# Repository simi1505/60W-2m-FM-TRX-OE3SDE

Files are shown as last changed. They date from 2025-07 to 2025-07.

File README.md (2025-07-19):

# 60W-2m-FM-TRX-OE3SDE
 60W 2m FM TRX with RA60H1317M1A + DRA818V by OE3SDE

## Result

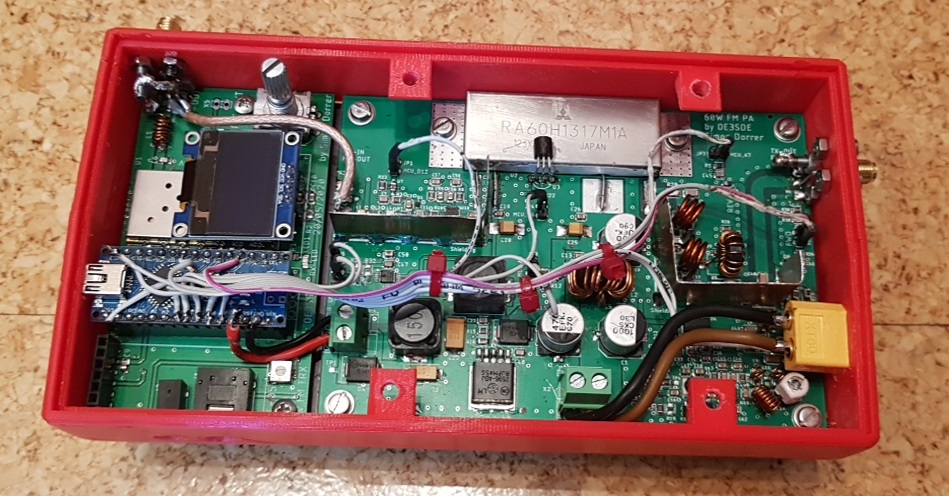
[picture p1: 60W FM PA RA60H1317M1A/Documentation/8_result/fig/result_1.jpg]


**Figure 1**: Final 60W 2m FM TRX in enclosure.

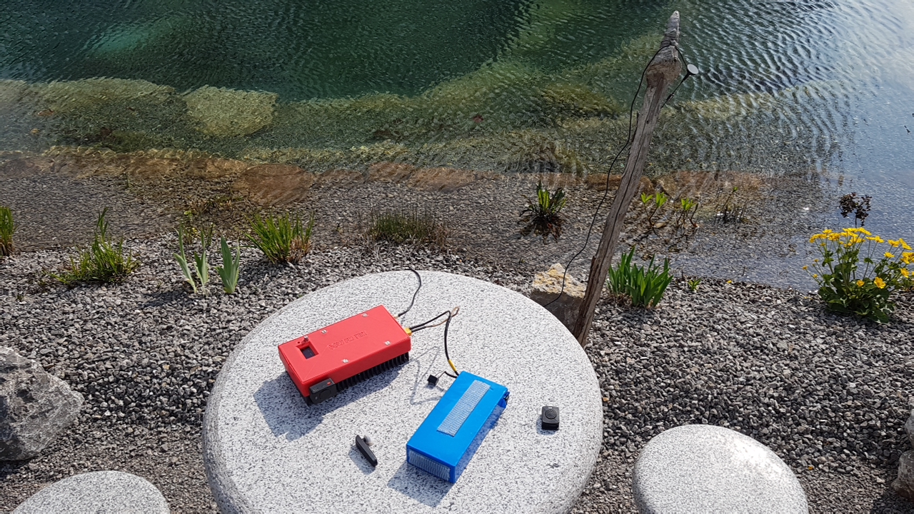
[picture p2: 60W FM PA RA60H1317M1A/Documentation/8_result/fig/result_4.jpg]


**Figure 2**: 60W 2m FM TRX on air.

## 60W TRX

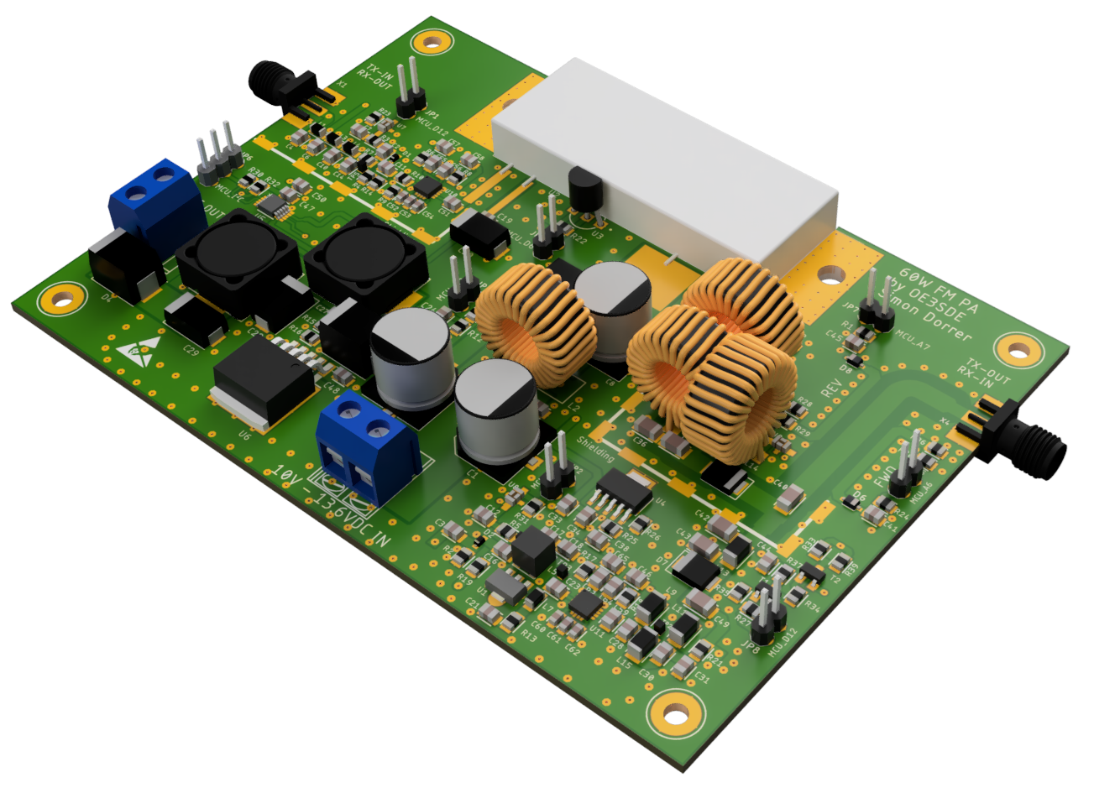
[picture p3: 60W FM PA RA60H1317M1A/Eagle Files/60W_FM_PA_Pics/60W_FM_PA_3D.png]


**Figure 3**: 3D View of RA60H1317M1A PCB.

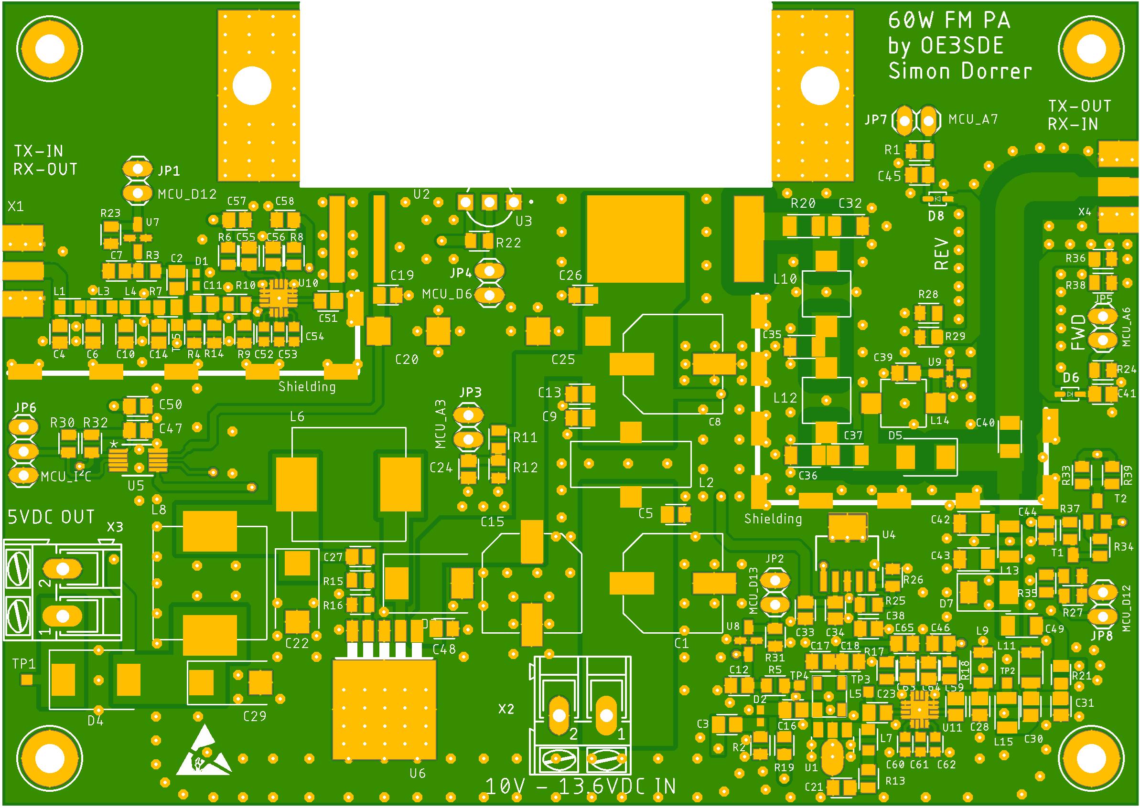
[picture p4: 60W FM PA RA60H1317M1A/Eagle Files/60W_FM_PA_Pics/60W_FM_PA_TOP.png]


**Figure 4**: Top View of RA60H1317M1A PCB.

## 1W TRX and control PCB

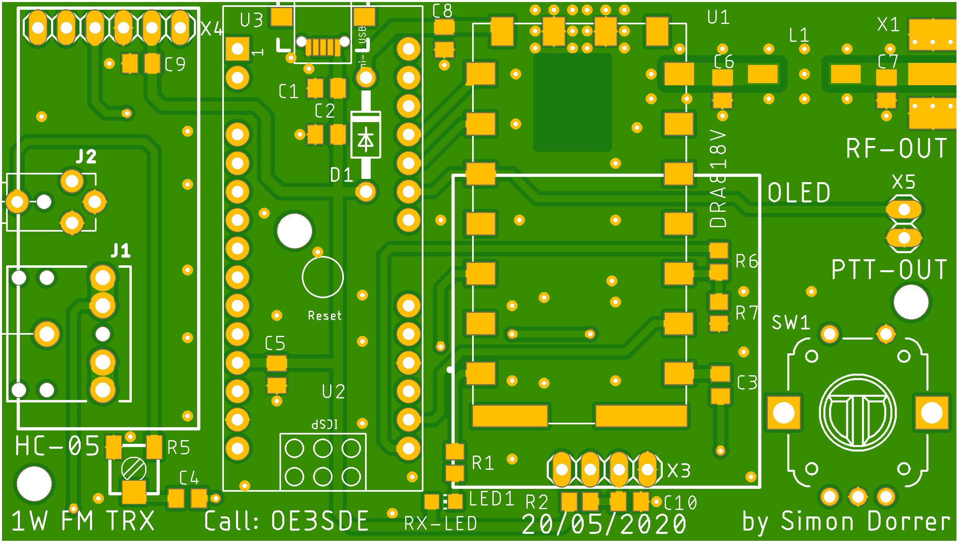
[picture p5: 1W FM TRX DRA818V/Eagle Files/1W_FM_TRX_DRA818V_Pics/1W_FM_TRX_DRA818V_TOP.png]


**Figure 5**: Top View of DRA818V PCB.

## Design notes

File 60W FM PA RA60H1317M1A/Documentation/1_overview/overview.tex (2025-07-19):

\section{Description}
On the following pages the most important details for the 60W 144MHz FM power amplifier are shown. This document includes circuits, PCB-Designs, bill of material, microcontroller codes, measurements and final result pictures.

\section{Software}
The theoretical work like circuit simulation, PCB Design and Microcontroller (MCU) programming was done with following software:
\begin{itemize}
	\item Multisim \& LTSpice: Circuit Simulation
	\item ELSIE: Analog Filter Design
	\item Autodesk EAGLE: Circuit- \& PCB-Design
	\item Autodesk Fusion 360: 3D Design
	\item Arduino: MCU Code
\end{itemize}
\newpage
\section{Devices}
The practical work like PCB assembly, fault finding and measurements are done with the following devices:
\begin{itemize}
	\item FLUKE 179 True RMS Multimeter
	\item Weller WT2020M Soldering Station
	\item Zhongdi ZD-939L Hot Air Rework Station
	\item Andonstar AD407 Digital Microscope
	\item Siglent SDS2352X-E Oscilloscope (2xCH, 350MHz)
	\item Siglent SDG2042X Function Generator (2xCH, 120MHz - hacked)
	\item Siglent SVA1015X Spektrum \& Vector Network Analyser (1.5GHz)
	\item Siglent SPD3303X-E Power Supply (2x0-32V with 3.2A, 1x2.5V/3.3V/5V with 3.2A)
	\item QJ3005EIII 300W Power Supply (2x0-30V with 5A, 1x5V with 3A)
	\item Anycubic i3 Mega S 3D Printer
\end{itemize}
A complete list of all my labor equipment can be found here: \url{https://www.oe3sde.com/Workstation.html}

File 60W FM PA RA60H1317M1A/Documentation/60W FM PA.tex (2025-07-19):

%Author: Simon Dorrer, k12005887
\input{./base/packages}
\input{./base/layout}
\input{./base/titlepage}

\begin{document}
	% Align text on top if there is space left on the page (no rubber lengths will be stretched)
	\raggedbottom
	\maketitle
	
	% Abstract
	\input{./abstract}

	\tableofcontents
	
	% -- Chapter 1 ------------------------------------------------------------------------------------	
	\chapter{Overview}
	\label{chp:overview}
	\input{./1_overview/overview}
	
	% -- Chapter 2 ------------------------------------------------------------------------------------	
	\chapter{Circuit}
	\label{chp:circuit}
	\input{./2_circuit/circuit}
	\includepdf[pages=-]{./2_circuit/60W FM PA_Circuit.pdf}
	
	% -- Chapter 3 ------------------------------------------------------------------------------------	
	\chapter{PCB}
	\label{chp:pcb}
	\input{./3_pcb/pcb}
	
	% -- Chapter 4 ------------------------------------------------------------------------------------	
	\chapter{Bill of Material}
	\label{chp:bom}
	\input{./4_bom/bom}
	
	% -- Chapter 5 ------------------------------------------------------------------------------------	
	\chapter{Measurements}
	\label{chp:measurements}
	\input{./5_measurements/measurements}
	
	% -- Chapter 6 ------------------------------------------------------------------------------------	
	\chapter{Microcontroller Code}
	\label{chp:code}
	\input{./6_code/code}
	% -- Chapter 7 ------------------------------------------------------------------------------------	
	\chapter{Enclosure}
	\label{chp:enclosure}
	\input{./7_enclosure/enclosure}
	
	% -- Chapter 8 ------------------------------------------------------------------------------------	
	\chapter{Result Pictures}
	\label{chp:result}
	\input{./8_result/result}

	%Appendix
	\appendix
	
	% -- List of Abbreviations ------------------------------------------------------------------------
	\newpage
	\chapter*{List of Abbreviations}
	\addcontentsline{toc}{chapter}{List of Abbreviations}
	\markboth{List of Abbreviations}{} % Such that also header shows the right title
	\begin{acronym}[CORDIC]
		\input{acronyms}
	\end{acronym}

	% -- List of Figures ---------------------------------------------------------------------------------
	\listoffigures
	
	% -- List of Tables ---------------------------------------------------------------------------------
	\listoftables
	
	% -- Bibliography ---------------------------------------------------------------------------------
	\bibliographystyle{./base/IEEEtran_isp}
	\bibliography{bibliography}
	
\end{document}

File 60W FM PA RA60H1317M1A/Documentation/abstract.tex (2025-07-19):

\begin{abstract}
	This 60W 144MHz FM Power Amplifier is the perfect "Add-On" for my previously released 1W 144MHz FM Transceiver. This power amplifier adds 30dB gain in the TX-Path and a lot of important analog RF filtering. Furthermore, the RX-Path is amplified with a gain of 23dB and is filtered with high order filters to improve the signal noise ration for better understanding of the other transmitters.
	All RX / TX signals are switched with PIN diodes to avoid expensive radio frequency shielded relais.
\end{abstract}

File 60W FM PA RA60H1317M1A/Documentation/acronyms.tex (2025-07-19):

\setlength{\itemsep}{1ex}
\setlength{\parskip}{0ex}

\acro{adc}[ADC]{analog to digital converter}
\acro{cmos}[CMOS]{complementary metal oxide semiconductor}
\acro{cw}[CW]{continuous wave}
\acro{dac}[DAC]{digital to analog converter}
\acro{mcu}[MCU]{microcontroller unit}
\acro{ic}[IC]{integrated circuit}
\acro{lna}[LNA]{low noise amplifier}
\acro{lpf}[LPF]{lowpass filter}
\acro{hpf}[HPF]{highpass filter}
\acro{bpf}[BPF]{bandpass filter}
\acro{lut}[LUT]{lookup table}
\acro{pa}[PA]{power amplifier}
\acro{pcb}[PCB]{printed circuit board}
\acro{rf}[RF]{radio frequency}
\acro{rx}[RX]{receive}
\acro{snr}[SNR]{signal to noise ratio}
\acro{ssb}[SSB]{single sideband}
\acro{tx}[TX]{transmit}
\acro{trx}[TRX]{transceiver}
\acro{fm}[FM]{frequency modulation}

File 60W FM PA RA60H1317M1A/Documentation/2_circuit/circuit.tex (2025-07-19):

\section{Filters}
In ham radio applications it is very important, that transmitted signals are only in the licensed band. This power amplifier works for the 2m band, that means a frequency range of 144MHz to 146MHz.
Of course, also the received signals should be filtered to avoid any unwanted noise.
\subsection{Air Coil Calculation}
The air coils for the TX-OUT and RX-IN filters according to circuit \ref{fig:TX-OUT Filter_Circuit} and \ref{fig:RX-IN Filter_Circuit} can be calculated with the following formula:
\begin{equation}
	L = \frac{N^{2} \cdot d^{2}}{18 \cdot d + 40 \cdot l}
\end{equation}
 Where:
\begin{itemize}
	\item L = Inductance
	\item N = Number of turns
	\item d = Coil outside diameter
	\item l = Length of the coil
\end{itemize}

\bigskip
For a faster result, also an online calculator\footnote{\url{https://m0ukd.com/calculators/air-cored-inductor-calculator/}} \cite{airCoilCalculator.2015} can be used. 

\newpage
\subsection{TX-IN Filter}
This filter is build up with SMT components because of the low input power of 0.5W.
The TX-IN filter is a seventh order chebyshev low pass filter with a cutoff frequency of 175MHz.
The high order is chosen because of the high harmonic distortion of the DRA818V \acs{TRX} at the input.
\begin{figure}[ht!]
	\centering
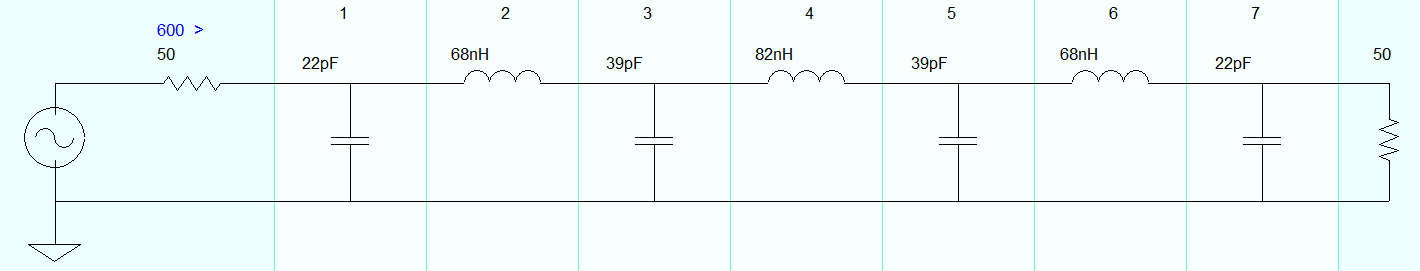
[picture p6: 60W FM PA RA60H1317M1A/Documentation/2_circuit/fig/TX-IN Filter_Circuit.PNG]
	
	\caption{Circuit of the TX-IN Filter}
	\label{fig:TX-IN Filter_Circuit}
\end{figure}
\bigskip
\begin{figure}[ht!]
	\centering
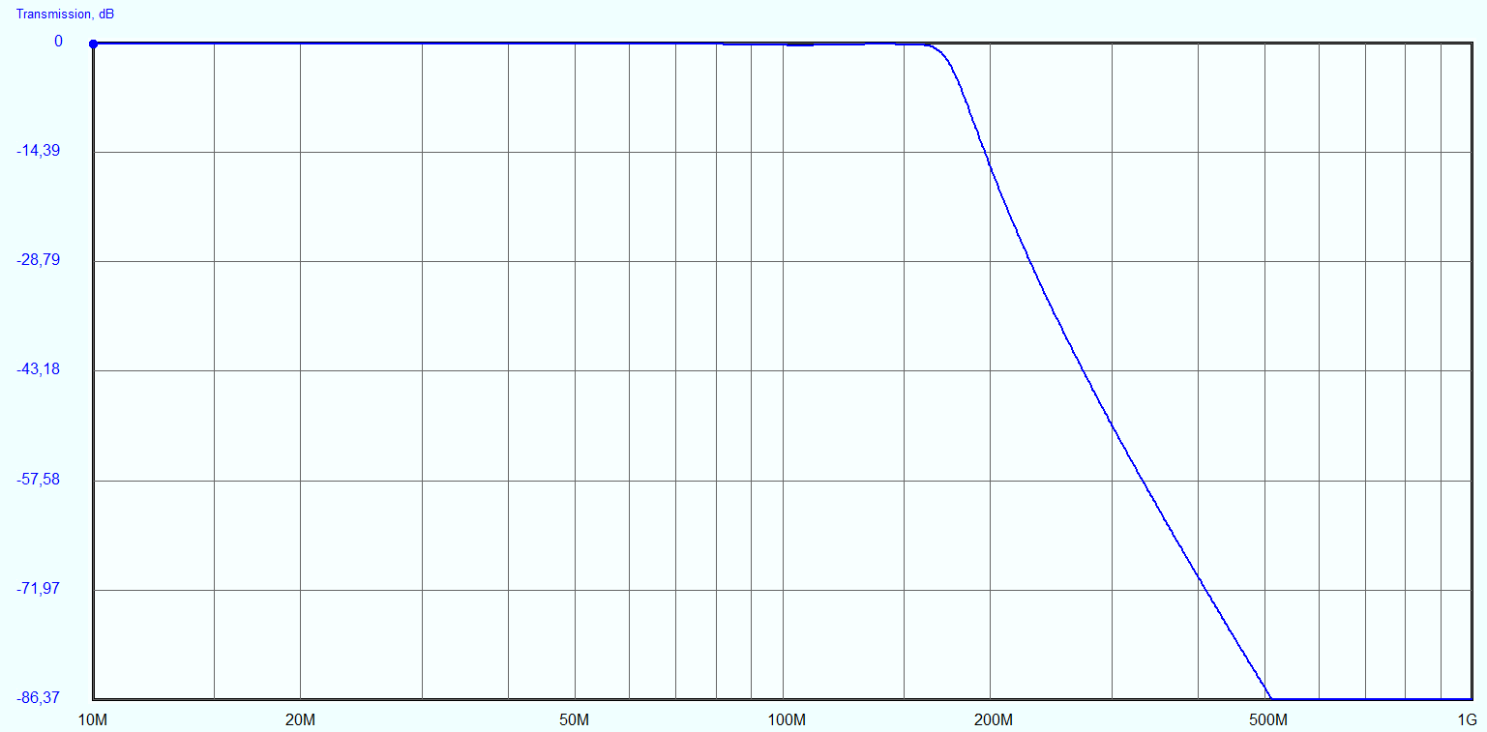
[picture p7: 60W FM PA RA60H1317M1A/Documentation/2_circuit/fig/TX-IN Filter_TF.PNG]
	
	\caption{Transfer Function of the TX-IN Filter}
	\label{fig:TX-IN Filter_TF}
\end{figure}

\newpage
\subsection{TX-OUT Filter}
This filter is build up with self-wound inductors because of the higher output power of 60W.
The TX-OUT filter is a fifth order chebyshev low pass filter with a cutoff frequency of 182MHz.

\begin{figure}[ht!]
	\centering
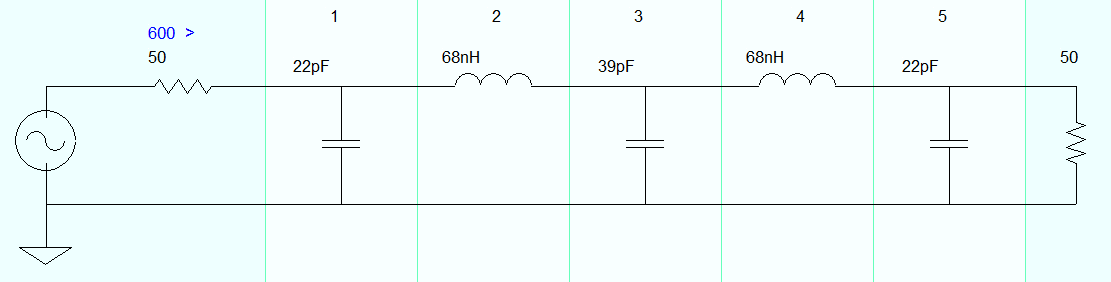
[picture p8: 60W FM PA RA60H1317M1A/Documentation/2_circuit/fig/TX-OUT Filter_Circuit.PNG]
	
	\caption{Circuit of the TX-OUT Filter}
	\label{fig:TX-OUT Filter_Circuit}
\end{figure}
\bigskip
\begin{figure}[ht!]
	\centering
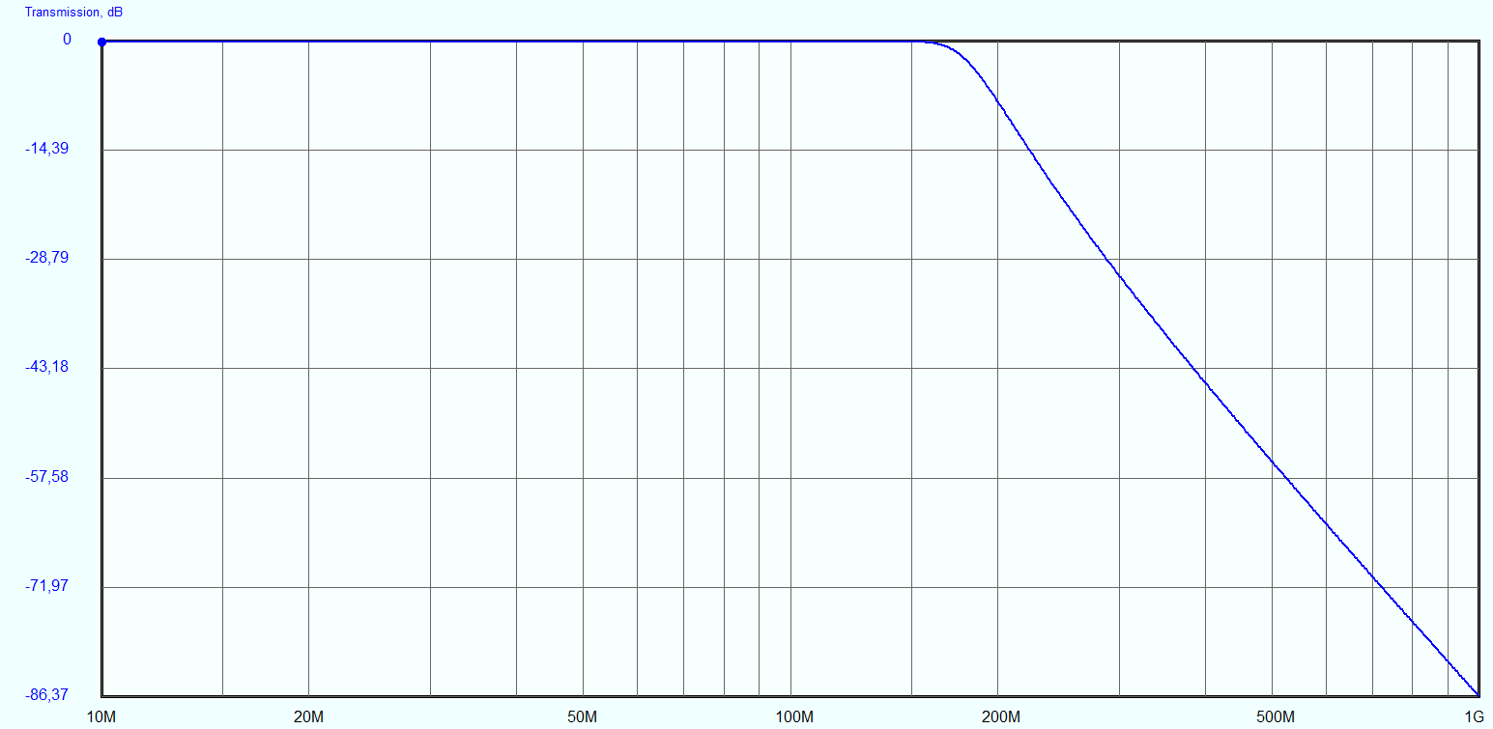
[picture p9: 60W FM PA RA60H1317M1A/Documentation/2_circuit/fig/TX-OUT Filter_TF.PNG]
	
	\caption{Transfer Function of the TX-OUT Filter}
	\label{fig:TX-OUT Filter_TF}
\end{figure}

\newpage
\subsection{RX-IN Filter}
This filter can be build up with SMT components. However, self-wound inductors can be changed easier and the filter band can be adjusted slightly.
The RX-IN filter is a third order chebyshev band pass filter with a lower cutoff frequency of 120MHz and a upper cutoff frequency of 172MHz.

\begin{figure}[ht!]
	\centering
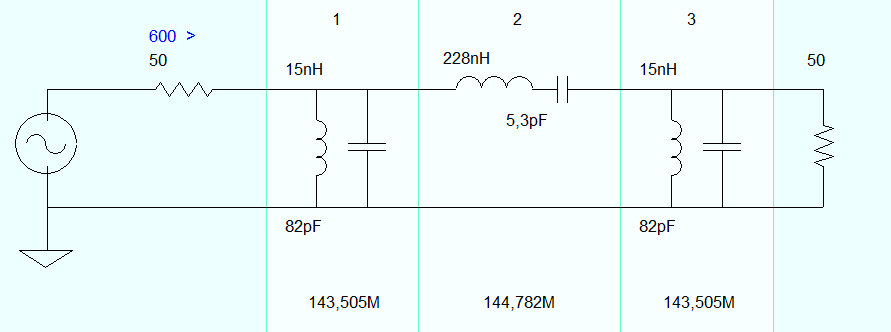
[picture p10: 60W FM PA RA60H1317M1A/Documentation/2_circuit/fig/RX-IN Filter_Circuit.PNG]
	
	\caption{Circuit of the RX-IN Filter}
	\label{fig:RX-IN Filter_Circuit}
\end{figure}
\bigskip
\begin{figure}[ht!]
	\centering
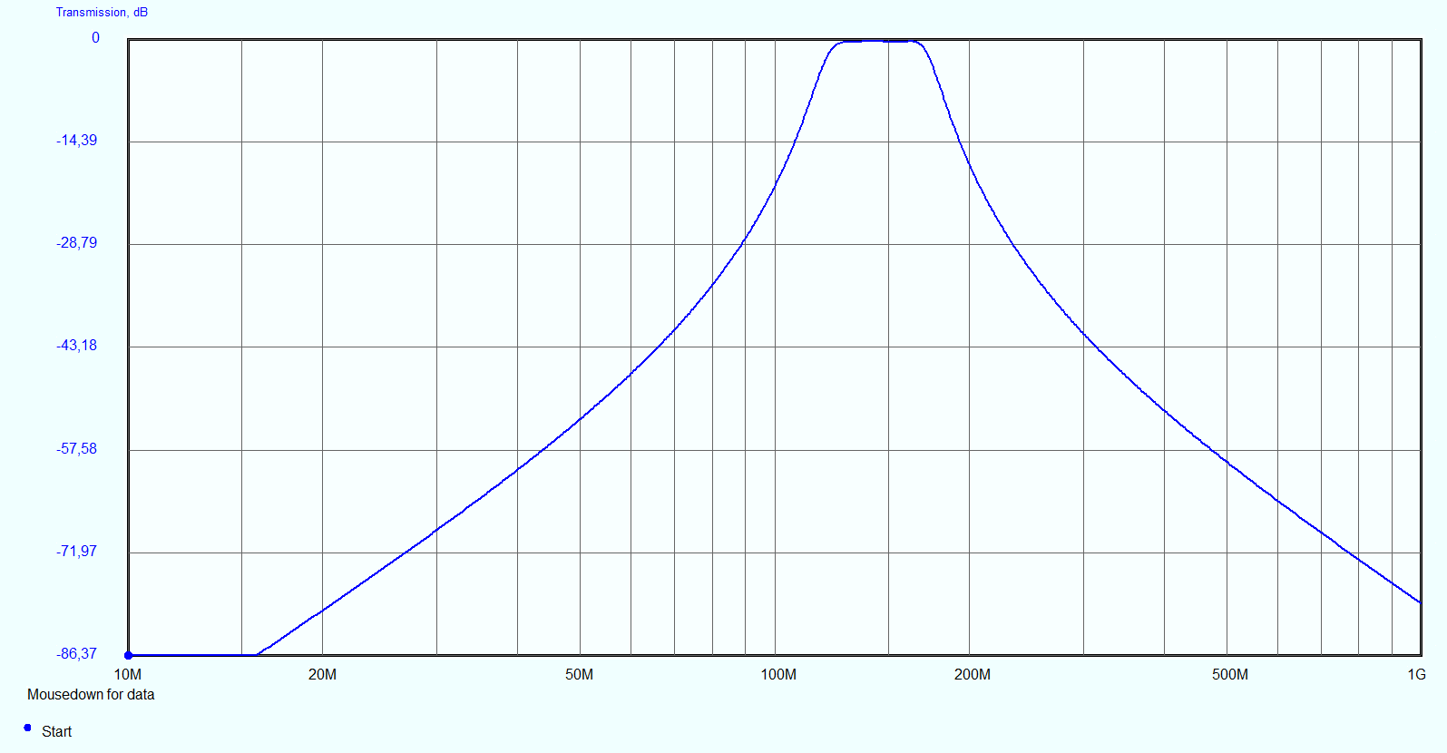
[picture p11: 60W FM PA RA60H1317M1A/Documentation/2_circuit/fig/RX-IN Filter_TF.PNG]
	
	\caption{Transfer Function of the RX-IN Filter}
	\label{fig:RX-IN Filter_TF}
\end{figure}

\newpage
\section{PIN-Diode Switches}
In this project, PIN-Diodes are used instead of relais to switch between RX and TX path.
\subsection{RX/TX Input-Switch}
ToDo Text
\begin{figure}[ht!]
	\centering
	%\includegraphics[width = 12cm]{./2_circuit/fig/}
	
	\caption{Circuit of the RX/TX Input-Switch}
	\label{fig:RX/TX Input-Switch}
\end{figure}

\newpage
\subsection{RX/TX Output-Switch}
ToDo Text
\begin{figure}[ht!]
	\centering
	%\includegraphics[width = 12cm]{./2_circuit/fig/}
	
	\caption{Circuit of the RX/TX Output-Switch}
	\label{fig:RX/TX Output-Switch}
\end{figure}

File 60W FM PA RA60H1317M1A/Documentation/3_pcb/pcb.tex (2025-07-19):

\section{Layer Stackup}
This \acs{PCB} is a two layer PCB. On the top layer the \acs{RF} signals and SMT components are placed. 
The bottom layer is a completed GND layer with some supply traces.
This PCB is produced by my sponsor JLCPCB \footnote{\url{https://jlcpcb.com/}}.
Normally, for bigger RF PCB-Designs a 4 layer PCB is used as follows: 

\begin{figure}[ht!]
	\centering
	
	\caption{Two Layer PCB Stackup}
	\label{fig:PCB Layer Stackup}
\end{figure}
\newpage

\section{Coplanar Waveguide Grounded (CPWG)}
In RF PCB-Design applications it is very important, that the trace impedance is matched to 50$\Omega$.
Therefore, different techniques like Microstrip, Stripline or Coplanar Waveguide are used.
This PCB-Design uses the Coplanar Waveguide method. However, the calculation of this technique is not that easy (elliptical integrals etc.). That is why an online calculator \footnote{\url{https://chemandy.com/calculators/coplanar-waveguide-with-ground-calculator.htm}}  \cite{CPWGCalculator.2021} is used.
The original equations are in \cite{transmissionLineDesign} on page 79.

\subsection{RX CPWG Calculation}
	\begin{figure}[ht!]
		\centering
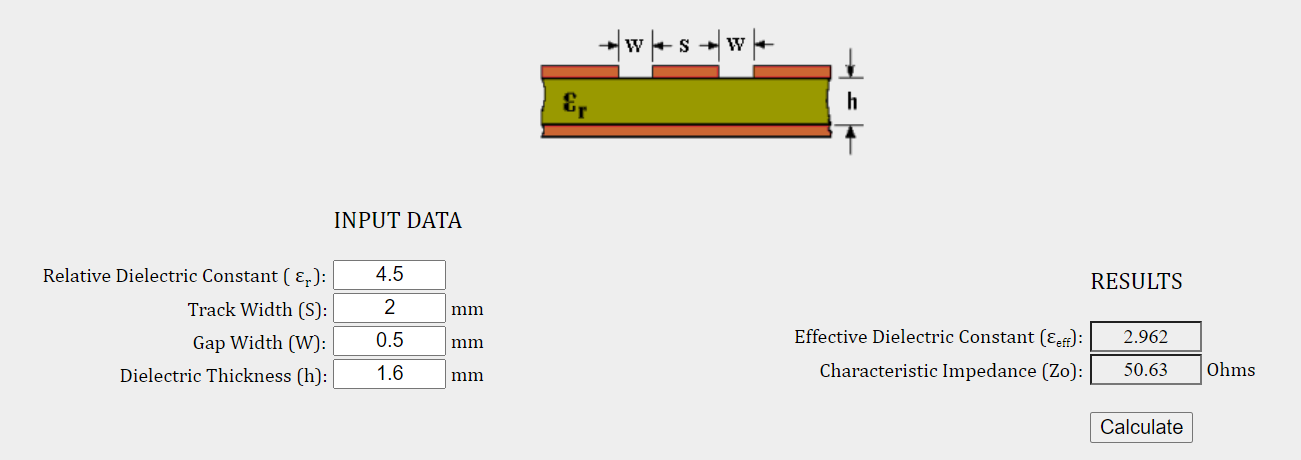
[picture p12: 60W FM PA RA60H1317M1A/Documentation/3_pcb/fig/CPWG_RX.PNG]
		
		\caption{RX CPWG Calculation}
		\label{fig:RX_CPWG}
	\end{figure}

\subsection{TX CPWG Calculation}
	\begin{figure}[ht!]
		\centering
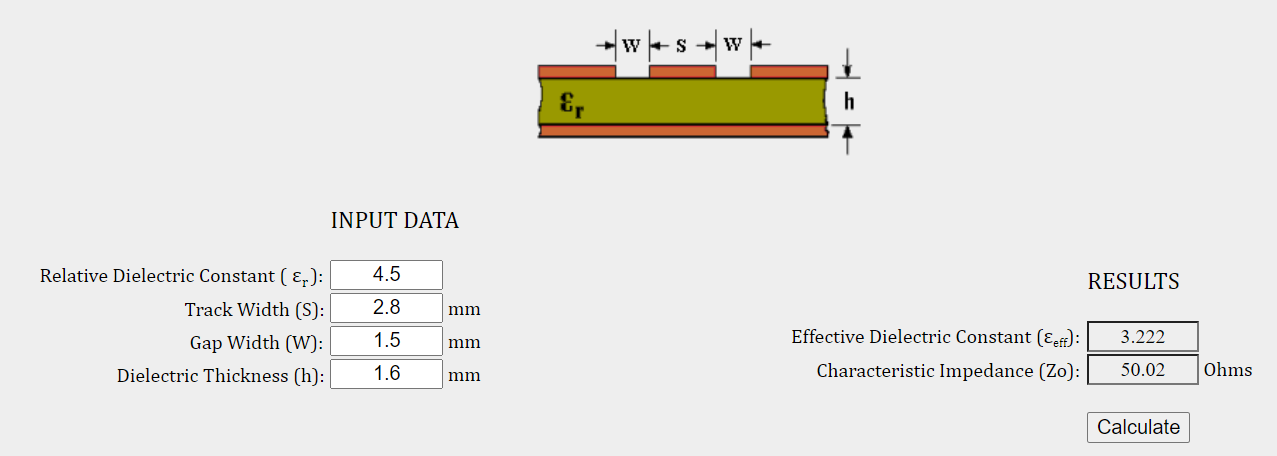
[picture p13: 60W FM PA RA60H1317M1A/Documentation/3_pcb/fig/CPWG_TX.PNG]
		
		\caption{TX CPWG Calculation}
		\label{fig:TX_CPWG}
	\end{figure}

\newpage
\section{Trace corners}	
	ToDo Text
	\begin{figure}[ht!]
		\centering
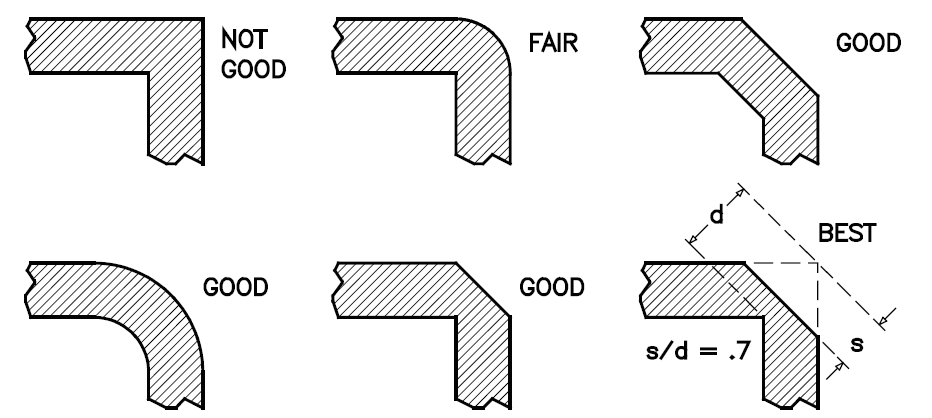
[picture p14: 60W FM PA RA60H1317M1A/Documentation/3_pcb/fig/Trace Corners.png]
		
		\caption{Corners in RF traces}
		\label{fig:Corners}
	\end{figure}

\section{3D PCB}	
	\begin{figure}[ht!]
		\centering
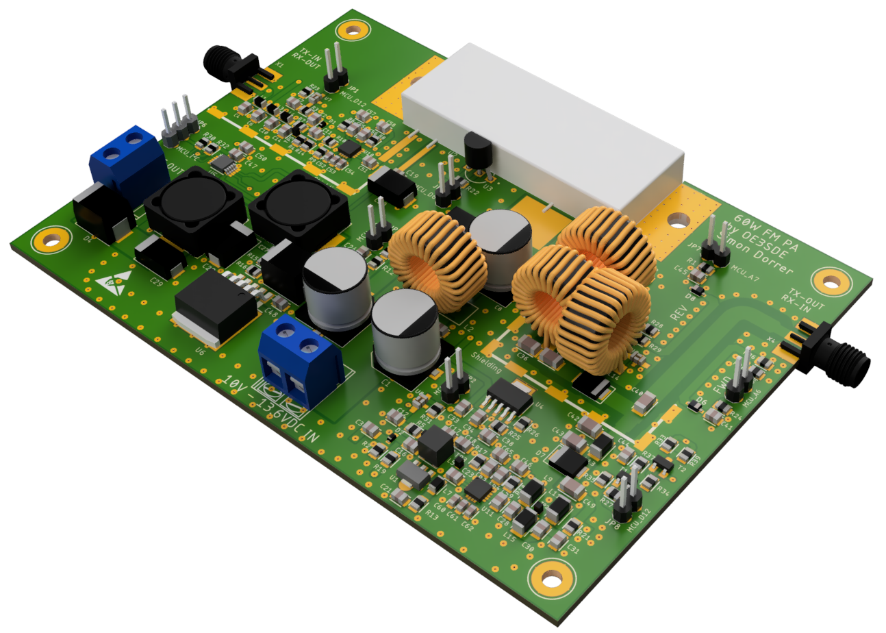
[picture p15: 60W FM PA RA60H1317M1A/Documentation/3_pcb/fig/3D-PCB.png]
		
		\caption{Finished \acs{PCB} 3D view}
		\label{fig:3D-PCB}
	\end{figure}

\newpage
\section{2D PCB}	
	\begin{figure}[ht!]
		\centering
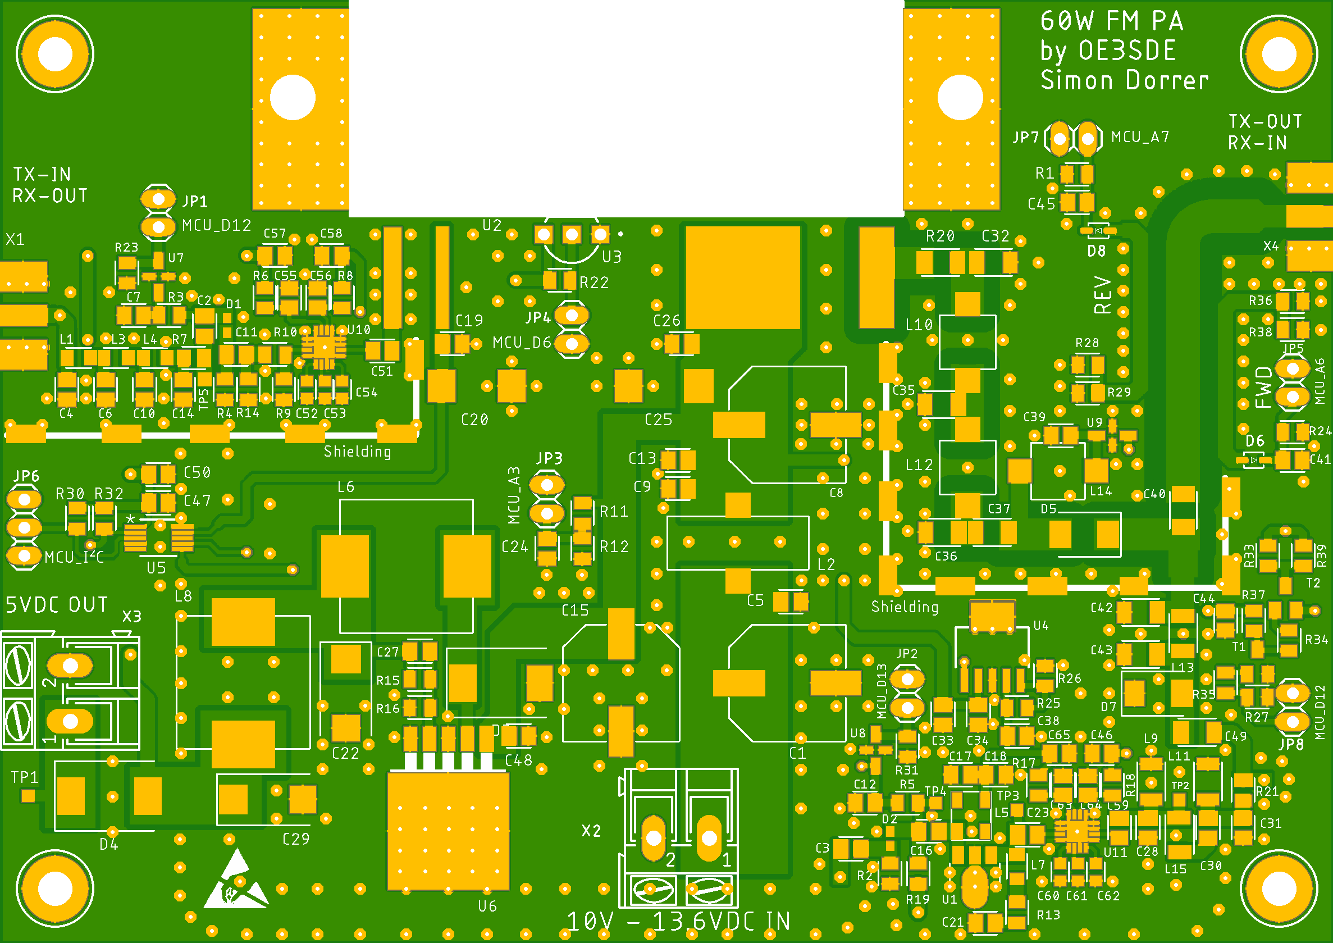
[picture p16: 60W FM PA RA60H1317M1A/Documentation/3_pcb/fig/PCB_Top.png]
		
		\caption{Finished \acs{PCB} 2D top view}
		\label{fig:PCB_Top}
	\end{figure}
	\bigskip
	\begin{figure}[ht!]
		\centering
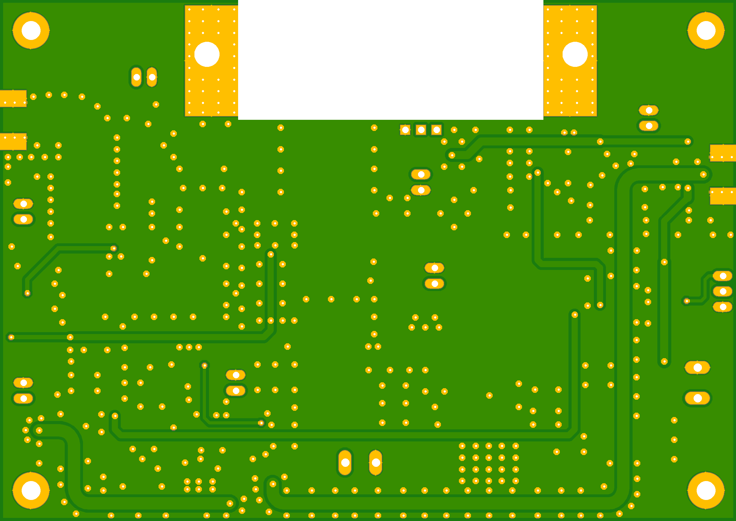
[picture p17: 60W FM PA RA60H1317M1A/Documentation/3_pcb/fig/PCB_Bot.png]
		
		\caption{Finished \acs{PCB} 2D bottom view}
		\label{fig:PCB_Bot}
	\end{figure}
\newpage

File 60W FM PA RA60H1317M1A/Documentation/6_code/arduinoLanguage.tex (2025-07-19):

 %%%%%%%%%%%%%%%%%%%%%%%%%%%%%%%%%%%%%%%%%%%%%%%%%%%%%%%%%%%%%%%%%%%%%%%%%%%%%%%% 
%%% ~ Arduino Language - Arduino IDE Colors ~                                  %%%
%%%                                                                            %%%
%%% Kyle Rocha-Brownell | 10/2/2017 | No Licence                               %%%
%%% -------------------------------------------------------------------------- %%%
%%%                                                                            %%%
%%% Place this file in your working directory (next to the latex file you're   %%%
%%% working on).  To add it to your project, place:                            %%%
%%%    \input{arduinoLanguage.tex}                                             %%%
%%% somewhere before \begin{document} in your latex file.                      %%%
%%%                                                                            %%%
%%% In your document, place your arduino code between:                         %%%
%%%   \begin{lstlisting}[language=Arduino]                                     %%%
%%% and:                                                                       %%%
%%%   \end{lstlisting}                                                         %%%
%%%                                                                            %%%
%%% Or create your own style to add non-built-in functions and variables.      %%%
%%%                                                                            %%%
%%%%%%%%%%%%%%%%%%%%%%%%%%%%%%%%%%%%%%%%%%%%%%%%%%%%%%%%%%%%%%%%%%%%%%%%%%%%%%%% 

\usepackage{color}
\usepackage{listings}    
\usepackage{courier}

%%% Define Custom IDE Colors %%%
\definecolor{arduinoGreen}    {rgb} {0.17, 0.43, 0.01}
\definecolor{arduinoGrey}     {rgb} {0.47, 0.47, 0.33}
\definecolor{arduinoOrange}   {rgb} {0.8 , 0.4 , 0   }
\definecolor{arduinoBlue}     {rgb} {0.01, 0.61, 0.98}
\definecolor{arduinoDarkBlue} {rgb} {0.0 , 0.2 , 0.5 }

%%% Define Arduino Language %%%
\lstdefinelanguage{Arduino}{
	language=C++, % begin with default C++ settings 
	%
	%
	%%% Keyword Color Group 1 %%%  (called KEYWORD3 by arduino)
	keywordstyle=\color{arduinoGreen},   
	deletekeywords={  % remove all arduino keywords that might be in c++
		break, case, override, final, continue, default, do, else, for, 
		if, return, goto, switch, throw, try, while, setup, loop, export, 
		not, or, and, xor, include, define, elif, else, error, if, ifdef, 
		ifndef, pragma, warning,
		HIGH, LOW, INPUT, INPUT_PULLUP, OUTPUT, DEC, BIN, HEX, OCT, PI, 
		HALF_PI, TWO_PI, LSBFIRST, MSBFIRST, CHANGE, FALLING, RISING, 
		DEFAULT, EXTERNAL, INTERNAL, INTERNAL1V1, INTERNAL2V56, LED_BUILTIN, 
		LED_BUILTIN_RX, LED_BUILTIN_TX, DIGITAL_MESSAGE, FIRMATA_STRING, 
		ANALOG_MESSAGE, REPORT_DIGITAL, REPORT_ANALOG, SET_PIN_MODE, 
		SYSTEM_RESET, SYSEX_START, auto, int8_t, int16_t, int32_t, int64_t, 
		uint8_t, uint16_t, uint32_t, uint64_t, char16_t, char32_t, operator, 
		enum, delete, bool, boolean, byte, char, const, false, float, double, 
		null, NULL, int, long, new, private, protected, public, short, 
		signed, static, volatile, String, void, true, unsigned, word, array, 
		sizeof, dynamic_cast, typedef, const_cast, struct, static_cast, union, 
		friend, extern, class, reinterpret_cast, register, explicit, inline, 
		_Bool, complex, _Complex, _Imaginary, atomic_bool, atomic_char, 
		atomic_schar, atomic_uchar, atomic_short, atomic_ushort, atomic_int, 
		atomic_uint, atomic_long, atomic_ulong, atomic_llong, atomic_ullong, 
		virtual, PROGMEM,
		Serial, Serial1, Serial2, Serial3, SerialUSB, Keyboard, Mouse,
		abs, acos, asin, atan, atan2, ceil, constrain, cos, degrees, exp, 
		floor, log, map, max, min, radians, random, randomSeed, round, sin, 
		sq, sqrt, tan, pow, bitRead, bitWrite, bitSet, bitClear, bit, 
		highByte, lowByte, analogReference, analogRead, 
		analogReadResolution, analogWrite, analogWriteResolution, 
		attachInterrupt, detachInterrupt, digitalPinToInterrupt, delay, 
		delayMicroseconds, digitalWrite, digitalRead, interrupts, millis, 
		micros, noInterrupts, noTone, pinMode, pulseIn, pulseInLong, shiftIn, 
		shiftOut, tone, yield, Stream, begin, end, peek, read, print, 
		println, available, availableForWrite, flush, setTimeout, find, 
		findUntil, parseInt, parseFloat, readBytes, readBytesUntil, readString, 
		readStringUntil, trim, toUpperCase, toLowerCase, charAt, compareTo, 
		concat, endsWith, startsWith, equals, equalsIgnoreCase, getBytes, 
		indexOf, lastIndexOf, length, replace, setCharAt, substring, 
		toCharArray, toInt, press, release, releaseAll, accept, click, move, 
		isPressed, isAlphaNumeric, isAlpha, isAscii, isWhitespace, isControl, 
		isDigit, isGraph, isLowerCase, isPrintable, isPunct, isSpace, 
		isUpperCase, isHexadecimalDigit, 
	}, 
	morekeywords={   % add arduino structures to group 1
		break, case, override, final, continue, default, do, else, for, 
		if, return, goto, switch, throw, try, while, setup, loop, export, 
		not, or, and, xor, include, define, elif, else, error, if, ifdef, 
		ifndef, pragma, warning,
	}, 
	% 
	%
	%%% Keyword Color Group 2 %%%  (called LITERAL1 by arduino)
	keywordstyle=[2]\color{arduinoBlue},   
	keywords=[2]{   % add variables and dataTypes as 2nd group  
		HIGH, LOW, INPUT, INPUT_PULLUP, OUTPUT, DEC, BIN, HEX, OCT, PI, 
		HALF_PI, TWO_PI, LSBFIRST, MSBFIRST, CHANGE, FALLING, RISING, 
		DEFAULT, EXTERNAL, INTERNAL, INTERNAL1V1, INTERNAL2V56, LED_BUILTIN, 
		LED_BUILTIN_RX, LED_BUILTIN_TX, DIGITAL_MESSAGE, FIRMATA_STRING, 
		ANALOG_MESSAGE, REPORT_DIGITAL, REPORT_ANALOG, SET_PIN_MODE, 
		SYSTEM_RESET, SYSEX_START, auto, int8_t, int16_t, int32_t, int64_t, 
		uint8_t, uint16_t, uint32_t, uint64_t, char16_t, char32_t, operator, 
		enum, delete, bool, boolean, byte, char, const, false, float, double, 
		null, NULL, int, long, new, private, protected, public, short, 
		signed, static, volatile, String, void, true, unsigned, word, array, 
		sizeof, dynamic_cast, typedef, const_cast, struct, static_cast, union, 
		friend, extern, class, reinterpret_cast, register, explicit, inline, 
		_Bool, complex, _Complex, _Imaginary, atomic_bool, atomic_char, 
		atomic_schar, atomic_uchar, atomic_short, atomic_ushort, atomic_int, 
		atomic_uint, atomic_long, atomic_ulong, atomic_llong, atomic_ullong, 
		virtual, PROGMEM,
	},  
	% 
	%
	%%% Keyword Color Group 3 %%%  (called KEYWORD1 by arduino)
	keywordstyle=[3]\bfseries\color{arduinoOrange},
	keywords=[3]{  % add built-in functions as a 3rd group
		Serial, Serial1, Serial2, Serial3, SerialUSB, Keyboard, Mouse,
	},      
	%
	%
	%%% Keyword Color Group 4 %%%  (called KEYWORD2 by arduino)
	keywordstyle=[4]\color{arduinoOrange},
	keywords=[4]{  % add more built-in functions as a 4th group
		abs, acos, asin, atan, atan2, ceil, constrain, cos, degrees, exp, 
		floor, log, map, max, min, radians, random, randomSeed, round, sin, 
		sq, sqrt, tan, pow, bitRead, bitWrite, bitSet, bitClear, bit, 
		highByte, lowByte, analogReference, analogRead, 
		analogReadResolution, analogWrite, analogWriteResolution, 
		attachInterrupt, detachInterrupt, digitalPinToInterrupt, delay, 
		delayMicroseconds, digitalWrite, digitalRead, interrupts, millis, 
		micros, noInterrupts, noTone, pinMode, pulseIn, pulseInLong, shiftIn, 
		shiftOut, tone, yield, Stream, begin, end, peek, read, print, 
		println, available, availableForWrite, flush, setTimeout, find, 
		findUntil, parseInt, parseFloat, readBytes, readBytesUntil, readString, 
		readStringUntil, trim, toUpperCase, toLowerCase, charAt, compareTo, 
		concat, endsWith, startsWith, equals, equalsIgnoreCase, getBytes, 
		indexOf, lastIndexOf, length, replace, setCharAt, substring, 
		toCharArray, toInt, press, release, releaseAll, accept, click, move, 
		isPressed, isAlphaNumeric, isAlpha, isAscii, isWhitespace, isControl, 
		isDigit, isGraph, isLowerCase, isPrintable, isPunct, isSpace, 
		isUpperCase, isHexadecimalDigit, 
	},      
	%
	%
	%%% Set Other Colors %%%
	stringstyle=\color{arduinoDarkBlue},    
	commentstyle=\color{arduinoGrey},    
	%          
	%   
	%%%% Line Numbering %%%%
	numbers=left,                    
	numbersep=5pt,                   
	numberstyle=\color{arduinoGrey},    
	%stepnumber=2,                      % show every 2 line numbers
	%
	%
	%%%% Code Box Style %%%%
	breaklines=true,                    % wordwrapping
	tabsize=2,         
	basicstyle=\ttfamily  
}

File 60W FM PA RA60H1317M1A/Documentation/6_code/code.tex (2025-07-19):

In this chapter, the MCU Code written with Arduino IDE is implemented. 
The internal hardware of the used MCU (ATmega328) is programmed on register level.
To control the OLED display, the external DAC and some sensors, external libraries are used.

\begin{lstlisting}[language=Arduino]
//Arduino Code for DRA818V FM TRX + 60W RA60H1317M1A
//This code is written by OE3SDE, Simon Dorrer!

//Define CPU-Clock-Speed (16MHz internal clock)
//#define F_CPU 16000000UL

//Define Baudrate for UART
//#define BAUD 9600UL

//Include Libraries
#include <avr/io.h>
#include <stdio.h>
#include <avr/interrupt.h>

//I2C
#include <Wire.h>

//MCP4728
#include <Adafruit_MCP4728.h>

//DS18B20
#include <OneWire.h> 
#include <DallasTemperature.h>

//Libs. for SD1306 OLED-Display
#include <Adafruit_GFX.h>               // Include core graphics library for the display
#include <Adafruit_SSD1306.h>           // Include Adafruit_SSD1306 library to drive the display
#include <Fonts/FreeMono9pt7b.h>        // Add a custom font
/*List of different fonts :
FreeMono9pt7b.h
FreeMonoBold9pt7b.h
FreeMonoBoldOblique9pt7b.h
FreeMonoOblique9pt7b.h  
*/
//----------------------------------------------------------------------------

//Definitions
//I/O Declaration
//1W FM TRX Board (DRA818V)
//#define TX        0     //PD0 / D0
//#define RX        1     //PD1 / D1
#define SW1         2     //PD2 / D2 - INT0
#define PTT_IN      3     //PD3 / D3 - INT1
#define PTT_OUT     7     //PD7 / D7
#define PD          0     //PB0 / D8
#define H_L         1     //PB1 / D9
#define HC05_TX     2     //PB2 / D10
#define HC05_RX     3     //PB3 / D11
#define E1          0     //PC0 / A0
#define E2          1     //PC1 / A1

//60W FM TRX Board (RA60H1317M1A)
#define PGA_SHDN    5     //PB5 / D13 (LOW --> PGA OFF, HIGH --> PGA ON) + RX Switch
#define TX_SW       4     //PB4 / D12 (HIGH TX Switch)
//#define T1_SW     7     //PD7 / D7  (switches T1 for TRX Switch - LOW for TX, HIGH for RX) --> see PTT_OUT D7
#define DS18B20_OW  6     //PD6 / D6  (One wire input of DS18B20 Temp. Sensor)
#define SWR_REV     7     //PC7 / A7  (ADC samples reverse voltage)
#define SWR_FWD     6     //PC6 / A6  (ADC samples forward voltage)
#define ADC_VDD     3     //PC3 / A3  (ADC samples VDD voltage) 

//I2C: OLED Display, MCP4728

//Makros
//RX or TX ATTENUATOR
#define RX_ATTENUATOR_CHANNEL  MCP4728_CHANNEL_A
#define TX_ATTENUATOR_CHANNEL  MCP4728_CHANNEL_B

//PA max. ratings
#define VDD_LOWER_LIMIT 10.7  //in V
#define VDD_UPPER_LIMIT 14.2  //in V
#define SWR_LOWER_LIMIT 0.5   
#define SWR_UPPER_LIMIT 2
#define HEAT_UPPER_LIMIT 45   //in degrees
//----------------------------------------------------------------------------

//Global variables / Objects
uint8_t TX = 0;  // 0... RX; 1... TX
uint8_t switched = 0;

//OLED
Adafruit_SSD1306 display(128, 64);    // Create display
volatile uint16_t timer1Count = 0;

//DRA818 Variables
typedef struct{
	float txFreq;         //TX-Frequency in MHz (134.0000 - 174.0000)
	float rxFreq;         //RX-Frequency in MHz (134.0000 - 174.0000)
	String txCTCSS;       //CTCSS frequency (0000 - 0038); 0000 = "no CTCSS" 
	String rxCTCSS;       //CTCSS frequency (0000 - 0038); 0000 = "no CTCSS" 
	uint8_t bw;           //Bandwith in KHz (0= 12.5KHz or 1= 25KHz)
	uint8_t squ;          //Squelch level  (0 - 8); 0 = "open" 
	uint8_t vol;
	uint8_t prf;
	uint8_t hpf;
	uint8_t lpf;
}DRA818;

DRA818 dra818 = {145.5000, 145.5000, "0000", "0000", 1, 4, 8, 0, 0, 0};

//DS18B20
OneWire oneWire(DS18B20_OW); 
DallasTemperature ds18b20(&oneWire);

//MCP4728
Adafruit_MCP4728 mcp4728;

//Rotary Encoder Variables
int counter = 0; 
int aState;
int aLastState;  

//RA60H1317M1A Variables
float txGain = 10;
float txAtt = 0;
float rxAtt = 0;
uint8_t monitorPA = 0;  //monitorPA = 1... PA is OK!
//----------------------------------------------------------------------------

//Subprograms
//Hardware Init Methods
void IO_Init()                  //initialize IO
{
	//Define INPUTs
	DDRD &= ~(1 << SW1);          //set PD2 (SW1) as Input
	PORTD |= (1 << SW1);          //activate Pull-Up-R at PD2 (SW1)    
	
	DDRD &= ~(1 << PTT_IN);       //set PD3 (PTT-IN) as Input
	PORTD |= (1 << PTT_IN);       //activate Pull-Up-R at PD3 (PTT_IN)     
	
	DDRC &= ~(1 << E1);           //set PC0 (E1) as Input    
	DDRC &= ~(1 << E2);           //set PC1 (E2) as Input
	
	DDRC &= ~(1 << ADC_VDD);      //set PC3 (ADC_VDD) as Input  
	//PORTC |= (1 << ADC_VDD);      //activate Pull-Up-R at PC3 (ADC_VDD)
	
	DDRC &= ~(1 << SWR_FWD);      //set PC6 (SWR_FWD) as Input  
	PORTC |= (1 << SWR_FWD);      //activate Pull-Up-R at PC6 (SWR_FWD)
	
	DDRC &= ~(1 << SWR_REV);      //set PC7 (SWR_REV) as Input  
	PORTC |= (1 << SWR_REV);      //activate Pull-Up-R at PC7 (SWR_REV)
	
	//Define OUTPUTs
	DDRD |= (1 << PTT_OUT);       //set PD7 (PTT_OUT) as Output
	DDRB |= (1 << PD);            //set PB0 (PD) as Output
	DDRB |= (1 << H_L);           //set PB1 (H_L) as Output
	
	DDRB |= (1 << TX_SW);         //set PB4 (TX_Switch) as Output
	DDRB |= (1 << PGA_SHDN);      //set PB5 (PGA_SHDN) as Output
}

void Timer1_COMPA_Init()
{
	//Control Registers
	TCCR1A = 0; TCCR1B = 0; TCCR1C = 0; //Reset
	
	// set CTC mode
	//TCCR1A |= (1 << WGM10);
	//TCCR1A |= (1 << WGM11);
	TCCR1B |= (1 << WGM12);
	
	// Set Prescaler 1024 (TCCR1B = (1 << WGM12) | (0x5 << CS10);)
	TCCR1B |= (1 << CS12);
	TCCR1B &= ~(1 << CS11);
	TCCR1B |= (1 << CS10);
	
	// initialize compare value
	OCR1A = 16;
	
	// enable timer compare interrupt
	TIMSK1 |= (1 << OCIE1A);
}

void Timer2_COMPA_Init()
{
	//Timer2 settings
	TCCR2A = 0x00; TCCR2B = 0x00; //Reset
	
	//Enable Timer2 CTC Mode
	//TCCR2A |= (1 << WGM20);
	TCCR2A |= (1 << WGM21);
	//TCCR2B |= (1 << WGM22);
	
	//Prescaler
	// 1024 prescaling for Timer2 (TCCR2B = (0x7 << CS20);)
	TCCR2B |= (1 << CS20);
	TCCR2B |= (1 << CS21);
	TCCR2B |= (1 << CS22);
	
	//Initialize compare value
	OCR2A = 0;
	
	//initialize TIMER0-Counter
	//TCNT2 = 0; // set counter value FORMEL: x = maximaler Zaehlwert - ((CPUtakt/PRESCALER)/ gesuchte Frequenz)
	
	//disable Timer compare interrupt
	TIMSK2 &= ~(1 << OCIE2A);
}

void INT0_Init()
{
	//enable Interrupt
	EIMSK |= (1 << INT0); //Ext. Int0 ein
	
	//Set falling Edge Interrupt (EICRA |= (0x2 << ISC00);)
	EICRA &= ~(1 << ISC00);
	EICRA |= (1 << ISC01);
}
void INT1_Init()
{
	//enable Interrupt
	EIMSK |= (1 << INT1); //Ext. Int1 ein
	
	//Set rising & falling Edge Interrupt (EICRA |= (0x2 << ISC10);)
	EICRA |= (1 << ISC10);
	EICRA &= ~(1 << ISC11);
}

void ADC_Init()
{
	//ADC Setup
	//Set Reference Voltage (VCC = VREF)
	ADMUX &= ~(1 << REFS1);
	ADMUX |= (1 << REFS0);
	
	//Prescaler --> 128 (50kHz - 200kHz)
	ADCSRA |= (1 << ADPS0);
	ADCSRA |= (1 << ADPS1);
	ADCSRA |= (1 << ADPS2);
	
	ADCSRA |= (1 << ADEN); //Enable ADC
	
	//Dummy Readout to warm up the ADC
	ADCSRA |= (1<<ADSC);          //Start ADC conclusion
	while (ADCSRA & (1<<ADSC)){}  //wait until ADC is ready
	(void) ADC;
}
uint16_t ADC_ReadValue(uint8_t channel)
{
	ADMUX = (ADMUX & ~(0x1F)) | (channel & 0x1F); //which ADCx? Bit Mask to secure ADMUX settings in Init() function
	
	ADCSRA |= (1<<ADSC);          //Start ADC conclusion
	while (ADCSRA & (1<<ADSC)){}  //wait until ADC is ready
	
	return ADC;                   //return the ADC value
}

//DRA818V Methods
void DRA818V_setGroup()
{
	Serial.print("AT+DMOSETGROUP=");         // begin message
	Serial.print(dra818.bw);
	Serial.print(",");
	Serial.print(dra818.txFreq, 4);
	Serial.print(",");
	Serial.print(dra818.rxFreq, 4);
	Serial.print(",");
	Serial.print(dra818.txCTCSS);
	Serial.print(",");
	Serial.print(dra818.squ);
	Serial.print(",");
	Serial.println(dra818.rxCTCSS);
}
void DRA818V_setVolume()
{
	Serial.print("AT+DMOSETVOLUME=");
	Serial.println(dra818.vol);
}
void DRA818V_setFilter()
{
	Serial.print("AT+SETFILTER=");
	Serial.print(dra818.prf);
	Serial.print(",");
	Serial.print(dra818.hpf);
	Serial.print(",");
	Serial.println(dra818.lpf);
}
void DRA818V_Init()             // initialize DRA818V
{
	PORTB &= ~(1 << PD);
	delay(2000);
	
	//I/O
	PORTD |= (1 << PTT_OUT);      // set PD7 (PTT_OUT) HIGH at the beginning (RX-Mode)
	PORTB |= (1 << PD);           // set PB0 (PD) HIGH at the beginning (Normal-Mode)
	PORTB &= ~(1 << H_L);         // set PB1 (H/L) LOW at the beginning (LOW-Power = 0.5W)
	
	//UART
	Serial.begin(9600);
	delay(10);
	DRA818V_setGroup();
	delay(500);
	DRA818V_setVolume();
	delay(500);
	DRA818V_setFilter();
	delay(500);
}

//RA60H1317M1A Methods
float getVDD()      //Get VDD Voltage (10.8VDC to 13.6VDC)
{
	float vdd = 0;
	// #PJN: You may spend a LOT of time in this loop => make ADC reading asynchronous
	
	vdd = ADC_ReadValue(ADC_VDD) * 5.0 / 1024.0;
	
	return((vdd * ((4700 + 18000) / 4700)) + 2.2);  //returns supply voltage without voltage division (magic numbers equals the voltage divider resistor values)
}
float getSWR()      //Get SWR of output load (should be between 0.5 and 2)
{
	float rev = 0;
	float fwd = 0;
	// #PJN: You may spend just more time in this loop => make ADC reading asynchronous
	for(int i = 0; i < 10; i++)   //10 iterations for a more precise result
	{
		rev = rev + ADC_ReadValue(SWR_REV);
		fwd = fwd + ADC_ReadValue(SWR_FWD);
	}
	rev = rev / 10 / 1024 * 5;
	fwd = fwd / 10 / 1024 * 5;
	
	//SWR Calculation
	return((fwd + rev) / (fwd - rev));
}
float getPWR()
{
	float fwd = 0;
	for(int i = 0; i < 10; i++)   //10 iterations for a more precise result
	{
		fwd = fwd + ADC_ReadValue(SWR_FWD);
	}
	fwd = fwd / 10 / 1024 * 5;
	
	//PWR Calculation
	return((fwd * fwd) / 50);
}
float getHeat()     //Get heat of RA60H1317M1A measured by DS18B20, should be smaller than 50
{
	ds18b20.requestTemperatures();
	return(ds18b20.getTempCByIndex(0));
}
void setTXGain(float gain)  //Set Gain of RA60H1317M1A via MCP4728 (VOUTD)
{
	if(gain == 0)
	{
		mcp4728.setChannelValue(MCP4728_CHANNEL_D, 0);
	}
	else
	{
		//ToDo Formula
		mcp4728.setChannelValue(MCP4728_CHANNEL_D, 4095);
	}
}
void setAttenuation(MCP4728_channel_t channel, float att) //Attenuation of U11 (RX) or U12 (TX) (F2255NLGK)
{
	//Note that the PGA-103 has a constant gain of 25dB for RX path! RX_ATTENUATOR_CHANNEL MCP4728_CHANNEL_A
	//Note that an 6dB Attenuator is assembled on board for TX path! TX_ATTENUATOR_CHANNEL MCP4728_CHANNEL_B
	
	if(att > 35)
	{
		mcp4728.setChannelValue(channel, 2048);
	}
	else if(att < 2.5)
	{
		mcp4728.setChannelValue(channel, 0);
	}
	else
	{
		att = att * (-1);
		mcp4728.setChannelValue(channel, (uint16_t)(4096 * (-0.03692 * att + 0.60769) / 5));  //0.7V (-2.5dB) to 1.9V (-35dB), magic numbers are calculated according to the attenuation curve of the datasheet!
	}
}
void switchPAtoTX(uint8_t TX_Att, uint8_t TX_Gain)
{
	if(monitorPA == 1)
	{
		//turn OFF RX:
		mcp4728.setChannelValue(MCP4728_CHANNEL_C, 0);    //turn RX Path in TRX Switch OFF (VOUTC to LOW)
		PORTB &= ~(1 << PGA_SHDN);                        //turn OFF PGA RX-Amp. and RX Switch (D13 to LOW)
		setAttenuation(RX_ATTENUATOR_CHANNEL, 36);        //set full attenuation of U11 (F2255NLGK)
		
		delay(100);     //100ms settling time
		
		//turn ON TX:
		PORTD &= ~(1 << PTT_OUT);                         //turn TX Path in TRX Switch ON (D7 LOW)
		PORTB |= (1 << TX_SW);                            //turn on TX Switch (D12 to HIGH)
		setAttenuation(TX_ATTENUATOR_CHANNEL, TX_Att);    //set attenuation of U12 (F2255NLGK)
		setTXGain(TX_Gain);                               //Set TX gain (VGG (Gate) voltage) of RA60H1317M1A
		delay(100);                                       //100ms settling time
	}
	else
	{
		switchPAtoRX(rxAtt);
	}
}
void switchPAtoRX(float RX_Att)
{
	//turn OFF TX:
	setTXGain(0);                                       //Set gain of RA60H1317M1A to 0
	setAttenuation(TX_ATTENUATOR_CHANNEL, 36);          //set full attenuation of U12 (F2255NLGK)
	PORTB &= ~(1 << TX_SW);                             //turn OFF TX Switch (D12 to LOW)
	PORTD |= (1 << PTT_OUT);                            //turn TX Path in TRX Switch OFF (D7 HIGH)
	delay(100);                                         //100ms settling time
	
	//turn ON RX
	mcp4728.setChannelValue(MCP4728_CHANNEL_C, 4095);   //turn RX Path in TRX Switch ON (VOUTC to HIGH)
	PORTB |= (1 << PGA_SHDN);                           //turn ON PGA RX-Amp. and RX Switch (D13 to HIGH)
	setAttenuation(RX_ATTENUATOR_CHANNEL, RX_Att);      //set attenuation of U11 (F2255NLGK)
	delay(100);                                         //100ms settling time
}
void verifyPA()   //Shutdown RA60H1317M1A according to SWR, VDD and Heat
{
	float vdd = getVDD();
	float swr = getSWR();
	float heat = getHeat();
	Serial.print("VDD: ");
	Serial.println(vdd);
	Serial.print("SWR: ");
	Serial.println(swr);
	Serial.print("HEAT: ");
	Serial.println(heat);
	
	//if((vdd >= VDD_LOWER_LIMIT && vdd <= VDD_UPPER_LIMIT) && (swr >= SWR_LOWER_LIMIT && swr <= SWR_UPPER_LIMIT) && heat <= HEAT_UPPER_LIMIT)
	if((vdd >= VDD_LOWER_LIMIT && vdd <= VDD_UPPER_LIMIT) && heat <= HEAT_UPPER_LIMIT)
	{
		monitorPA = 1;  //PA is OK!
	}
	else
	{
		monitorPA = 0;
		if(TX == 1)
		{
			switchPAtoRX(rxAtt);
		}
	}
}

//Display Methods
void displayInit()
{
	delay(100);                                 // This delay is needed to let the display to initialize
	if(!display.begin(SSD1306_SWITCHCAPVCC, 0x3C)){ // Address 0x3C for 128x32
		Serial.println(F("SSD1306 allocation failed"));
		while (1){
			delay(10);
		}
	}
	display.clearDisplay();                     // Clear the buffer
	display.setTextColor(WHITE);                // Set color of the text
	//display.setRotation(2);                     // Set orientation. Goes from 0, 1, 2 or 3
	display.setTextWrap(false);                 // By default, long lines of text are set to automatically "wrap" back to the leftmost column. 
	// To override this behavior (so text will run off the right side of the display - useful for scrolling marquee effects), use setTextWrap(false).
	display.dim(0);                             //Set brightness (0 is maximun and 1 is a little dim)
	display.setFont(&FreeMono9pt7b);            // Set a custom font
	display.setTextSize(0);                     // Set text size. We are using a custom font so you should always use the text size of 0
	display.display();                          // Print everything we set previously
}
void displayStartScreen()
{
	display.setCursor(10, 15);                  // (x,y)
	display.println("60W FM TRX");              // Text or value to print
	display.setCursor(10, 35);                  // (x,y)
	display.println("by OE3SDE");               // Text or value to print
	display.setCursor(10, 55);                  // (x,y)
	display.println("S. Dorrer");               // Text or value to print
	display.display();                          // Print everything we set previously
}
void refreshDisplay()
{
	display.clearDisplay();
	
	// TX / RX
	if(TX == 1)
	{
		display.setCursor(10, 15);                  // (x,y)
		display.println("TX");
	}
	else if(TX == 0)
	{
		display.setCursor(10, 15);                  // (x,y)
		display.println("RX");
	}
	
	// Power
	display.setCursor(50, 15);                    // (x,y)
	display.println("PWR:.5W");
	
	// Frequency
	display.setCursor(30, 35);                    // (x,y)
	display.println(dra818.txFreq);
	
	//Values
	display.setCursor(2, 55);                  // (x,y)
	display.print(getVDD());                    // Text or value to print
	display.print(" ");
	display.print(getHeat());                  // Text or value to print  
	display.display();
}
//----------------------------------------------------------------------------

//Setup (Initialize hardware)
void setup()
{
	//HW Init
	IO_Init();
	INT0_Init();
	INT1_Init();
	Timer1_COMPA_Init();
	Timer2_COMPA_Init();
	ADC_Init();
	
	// OLED Init
	displayInit();
	displayStartScreen();
	
	//DRA818V Init
	DRA818V_Init();
	
	//DS18B20 Init
	ds18b20.begin(); 
	
	//MCP4728 Init
	if(!mcp4728.begin()){
		Serial.println("Failed to find MCP4728 chip!");
		while (1){
			delay(10);
		}
	}
	
	//RA60H1317M1A
	verifyPA();
	switchPAtoRX(rxAtt); //standard attenuation of 10dB
	
	sei(); //enable global interrupts
	
	//Reads the initial state of the outputA (E2)
	aLastState = digitalRead(E2); 	// #PJN: wondering why you're now using the digitalRead() because output handling is done via direct register access - it's however OK anyways
	
	display.clearDisplay();
	display.display();
}
//----------------------------------------------------------------------------

//Loop
void loop()
{
	if(timer1Count >= 500)
	{
		timer1Count = 0;
		verifyPA();
		refreshDisplay();
	}
	
	if(TX == 1 && switched == 1)
	{
		switchPAtoTX(txAtt, txGain);    //PA PCB is transmitting now!
		//PORTD &= ~(1 << PTT_OUT);     //DRA818V TX (done in switchPAtoTX)
		switched = 0;
	}
	else if (TX == 0 && switched == 1)
	{
		//PORTD |= (1 << PTT_OUT);      //DRA818V RX (done in switchPAtoRX)
		switchPAtoRX(rxAtt);            //PA PCB is receiving now!
		switched = 0;
	}
	
	// #PJN: Because of the above code you'll get a lot of jitter when reading the encoder below
	aState = digitalRead(E2); // Reads the "current" state of the outputA
	// If the previous and the current state of the outputA are different, that means a Pulse has occured
	if (aState != aLastState)
	{     
		// If the outputB state is different to the outputA state, that means the encoder is rotating clockwise
		if (digitalRead(E1) != aState) 
		{ 
			counter++;
		} 
		else 
		{
			counter--;
		}
	} 
	aLastState = aState; // Updates the previous state of the outputA with the current state
}
//----------------------------------------------------------------------------

//ISP (Interrupt Service Routine) 
ISR(TIMER1_COMPA_vect)  // every 1ms
{
	timer1Count++;
}

ISR(TIMER2_COMPA_vect) // execute by TIMER2 CTC
{
	static uint16_t timer2Count = 0; //only at first ISR call
	
	timer2Count++; //inkrementieren
	
	if(timer2Count == 4000) //256ms sperren
	{
		//enable INT0
		EIMSK |= (1 << INT0); //Ext. Int0 on
		
		//enable INT1
		EIMSK |= (1 << INT1); //Ext. Int0 on
		
		//clear INTF0
		EIFR |= (1 << INTF0);
		
		//clear INTF1
		EIFR |= (1 << INTF1);
		
		//disable TIMER2 compare interrupt
		TIMSK2 &= ~(1 << OCIE2A);
		
		//reset of counter value
		timer2Count = 0;
	}
}

ISR(INT0_vect)  //Rotary Encoder Switch
{
	static uint8_t encoderPressedCounter = 1; //only at first ISR call
	
	uint8_t temp = SREG; //Store SREG
	
	encoderPressedCounter++;
	
	//DEBOUNCE
	//disable INT0
	EIMSK &= ~(1 << INT0); //Ext. INT0 off
	//enable TIMER2 compare interrupt
	TIMSK2 |= (1 << OCIE2A);
	
	switch (encoderPressedCounter) 
	{
		case 1:
		// #PJN: Off topic: channel spacing on 2m is 12.5 kHz ... maybe just increase/decrease frequency values instead of fixed ones?
		dra818.txFreq = 145.5000;   //TX-Frequency in MHz
		dra818.rxFreq = 145.5000;   //RX-Frequency in MHz
		DRA818V_setGroup();
		break;
		case 2:
		dra818.txFreq = 144.2000;   //TX-Frequency in MHz
		dra818.rxFreq = 144.2000;   //RX-Frequency in MHz
		DRA818V_setGroup();
		break;
		case 3:
		dra818.txFreq = 144.5000;   //TX-Frequency in MHz
		dra818.rxFreq = 144.5000;   //RX-Frequency in MHz
		DRA818V_setGroup();
		break;
		case 4:
		dra818.txFreq = 145.2000;   //TX-Frequency in MHz
		dra818.rxFreq = 145.2000;   //RX-Frequency in MHz
		DRA818V_setGroup();
		break;
		case 5:
		dra818.txFreq = 145.0000;   //TX-Frequency in MHz
		dra818.rxFreq = 145.0000;   //RX-Frequency in MHz
		DRA818V_setGroup();
		encoderPressedCounter = 0;
		break;
		default:
		encoderPressedCounter = 0;
		break;
	}
	
	SREG = temp;
}

ISR(INT1_vect) //PTT-IN (active LOW)
{
	//DEBOUNCE
	//disable INT1
	//EIMSK &= ~(1 << INT1); //Ext. INT1 off
	//enable TIMER2 compare interrupt
	//TIMSK2 |= (1 << OCIE2A);
	
	switched = 1;
	
	if(!(PIND & (1 << PTT_IN)))         //PTT_IN changed to LOW
	{
		//switchPAtoTX(txAtt, txGain);    //PA PCB is transmitting now!
		//PORTD &= ~(1 << PTT_OUT);       //DRA818V TX (done in switchPAtoTX)
		TX = 1;
	}
	else if (PIND & (1 << PTT_IN))      //PTT_IN changed to HIGH
	{
		//PORTD |= (1 << PTT_OUT);        //DRA818V RX (done in switchPAtoRX)
		//switchPAtoRX(rxAtt);            //PA PCB is receiving now!
		TX = 0;
	}
}
//----------------------------------------------------------------------------
//End of Code!
\end{lstlisting}

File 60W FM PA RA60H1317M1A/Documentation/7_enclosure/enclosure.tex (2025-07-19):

Unfortunately, the 3D enclosure is not finished yet. In the end, the enclosure will be 3D printed.

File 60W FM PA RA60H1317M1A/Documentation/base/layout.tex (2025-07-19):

%Geometry of document: A4 portrait
%\geometry{paper=a4paper, top=1.6cm, bottom=2.85cm, left=0.9cm, right=2.15cm}
%\geometry{paper=a4paper, top=3.6cm, bottom=3.6cm, left=2.6cm, right=3.7cm}
\geometry{paper = a4paper, left = 20mm, right = 15mm, top = 15mm, bottom = 12.5mm, includeheadfoot}

%Header formation
\pagestyle{fancy}
\fancyhf{}												% Clear header / footer
\fancyhead[EL, OR]{\textsc{\nouppercase{\leftmark}}}    % Chapter in the right on even pages
\fancyhead[ER, OL]{\thepage}							%Page number location
\fancyfoot[ER, OL]{\copyright\/ Simon Dorrer, OE3SDE}	%Copyright + Name + Matrikelnmmer

\fancypagestyle{plain}{									%set pagestyle also for plain page
	\pagestyle{fancy}
}

%Separation line header / footer with 1.25pt
%\renewcommand{\headrulewidth}{1.25pt}
%\renewcommand{\footrulewidth}{1.25pt}

% Optional: Correct bad hyphenation
\hyphenation{}

%10mm area between header / footer and textarea
\setlength{\headsep}{10mm}
\setlength{\footskip}{12.5mm}

%No indentation, 1.1ex between paragraphs
\setlength{\parindent}{0ex}
\setlength{\parskip}{1.1ex plus0.25ex minus0.25ex}

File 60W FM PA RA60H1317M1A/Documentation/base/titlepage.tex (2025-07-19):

%Title
\title{\emph{60W 144MHz FM Power Amplifier}}	%Set title (no new page)
\author{by Simon Dorrer, OE3SDE}				%Set Name and matrikelnumber (also \footnote instead of \thanks is possible)
\date{\today}									%Set date

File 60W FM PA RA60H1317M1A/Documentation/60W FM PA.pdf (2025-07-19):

# 60W 144MHz FM Power Amplifier

## by Simon Dorrer, OE3SDE

## May 18, 2021

Abstract

### This 60W 144MHz FM Power Amplifier is the perfect "Add-On" for my previously released 1W 144MHz FM Transceiver. This power amplifier adds 30dB gain in the TX-Path and a lot of

important analog RF filtering. Furthermore, the RX-Path is amplified with a gain of 23dB and is filtered with high order filters to improve the signal noise ration for better understanding of the other transmitters. All RX / TX signals are switched with PIN diodes to avoid expensive radio frequency shielded relais.

Contents | 2

# Contents

1 Overview | 4
2 Circuit | 6
3 PCB | 13
4 Bill of Material | 17
5 Measurements | 19

### © Simon Dorrer, OE3SDE

3 | Contents
6 Microcontroller Code | 25
7 Enclosure | 42
8 Result Pictures | 43
List of Abbreviations | 45
List of Figures | 46
List of Tables | 47
Bibliography | 48

Chapter 1. | Overview | 4

# Chapter 1

# Overview

## 1.1 Description

On the following pages the most important details for the 60W 144MHz FM power amplifier are shown. This document includes circuits, PCB-Designs, bill of material, microcontroller codes, measurements and final result pictures.

## 1.2 Software

The theoretical work like circuit simulation, PCB Design and Microcontroller (MCU) programming

### was done with following software:

### - Multisim & LTSpice: Circuit Simulation

### - ELSIE: Analog Filter Design

### - Autodesk EAGLE: Circuit- & PCB-Design

### - Autodesk Fusion 360: 3D Design

### - Arduino: MCU Code

5 | Chapter 1. | Overview

## 1.3 Devices

The practical work like PCB assembly, fault finding and measurements are done with the following

### devices:

### - FLUKE 179 True RMS Multimeter

### - Weller WT2020M Soldering Station

### - Zhongdi ZD-939L Hot Air Rework Station

### - Andonstar AD407 Digital Microscope

### - Siglent SDS2352X-E Oscilloscope (2xCH, 350MHz)

### - Siglent SDG2042X Function Generator (2xCH, 120MHz - hacked)

### - Siglent SVA1015X Spektrum & Vector Network Analyser (1.5GHz)

### - Siglent SPD3303X-E Power Supply (2x0-32V with 3.2A, 1x2.5V/3.3V/5V with 3.2A)

### - QJ3005EIII 300W Power Supply (2x0-30V with 5A, 1x5V with 3A)

### - Anycubic i3 Mega S 3D Printer

### A complete list of all my labor equipment can be found here: https://www.oe3sde.com/

Workstation.html (https://www.oe3sde.com/Workstation.html)

Chapter 2. | Circuit | 6

# Chapter 2

# Circuit

## 2.1 Filters

In ham radio applications it is very important, that transmitted signals are only in the licensed band. This power amplifier works for the 2m band, that means a frequency range of 144MHz to 146MHz. Of course, also the received signals should be filtered to avoid any unwanted noise.

## 2.1.1 Air Coil Calculation

The air coils for the TX-OUT and RX-IN filters according to circuit 2.3 and 2.5 can be calculated

### with the following formula:

L =

N²
- d

2
18 · d + 40 · l

(2.1)

### Where:

### - L = Inductance

### - N = Number of turns

### - d = Coil outside diameter

### - l = Length of the coil

### For a faster result, also an online calculator¹

[1] can be used.

1https://m0ukd.com/calculators/air-cored-inductor-calculator/

## 2.1.2 TX-IN Filter

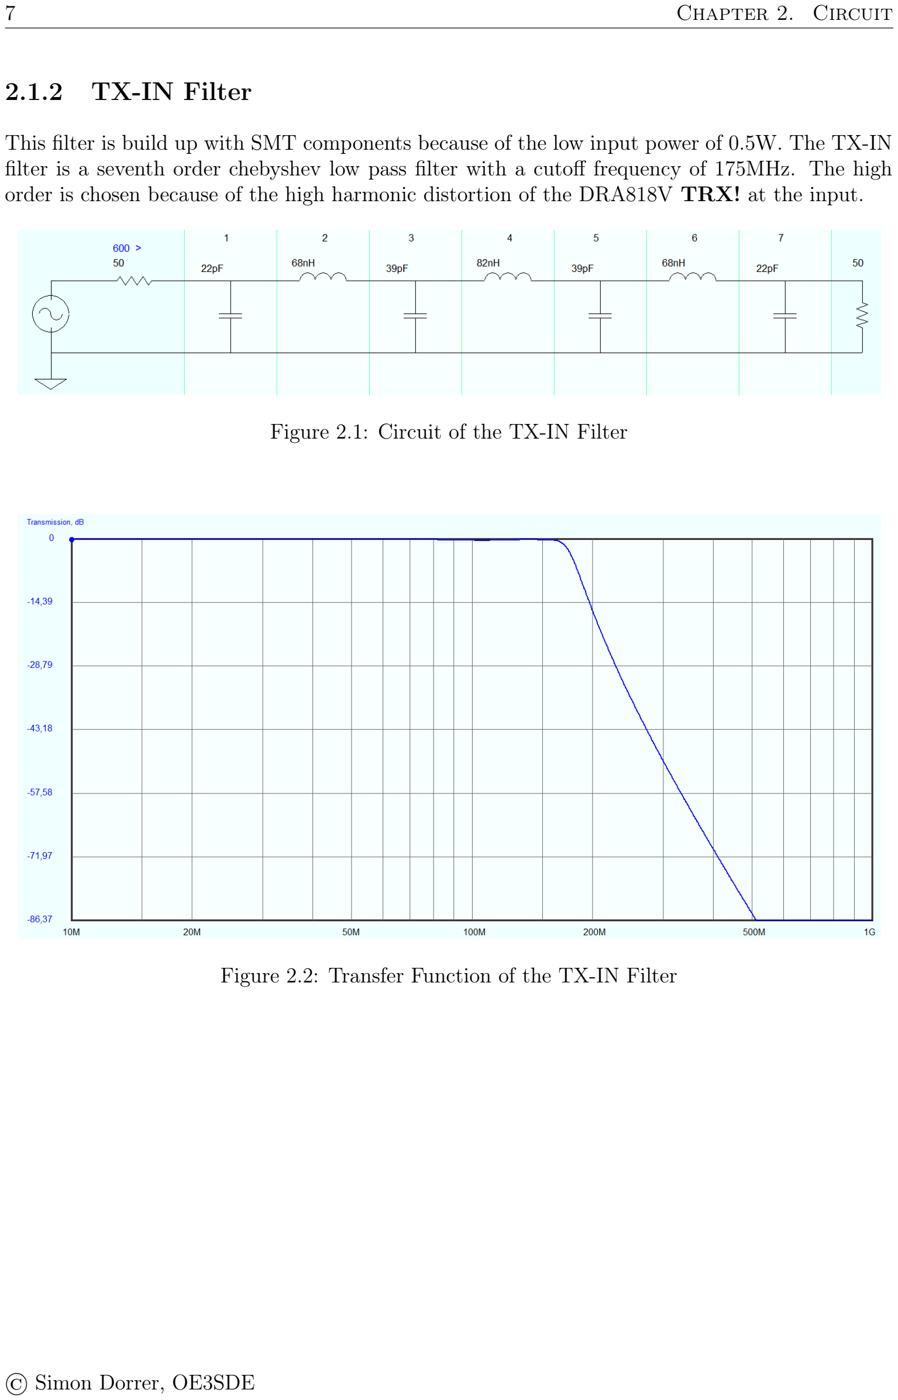
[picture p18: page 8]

7 | Chapter 2. | Circuit

This filter is build up with SMT components because of the low input power of 0.5W. The TX-IN filter is a seventh order chebyshev low pass filter with a cutoff frequency of 175MHz. The high order is chosen because of the high harmonic distortion of the DRA818V TRX! at the input.

### Figure 2.1: Circuit of the TX-IN Filter

### Figure 2.2: Transfer Function of the TX-IN Filter

## 2.1.3 TX-OUT Filter

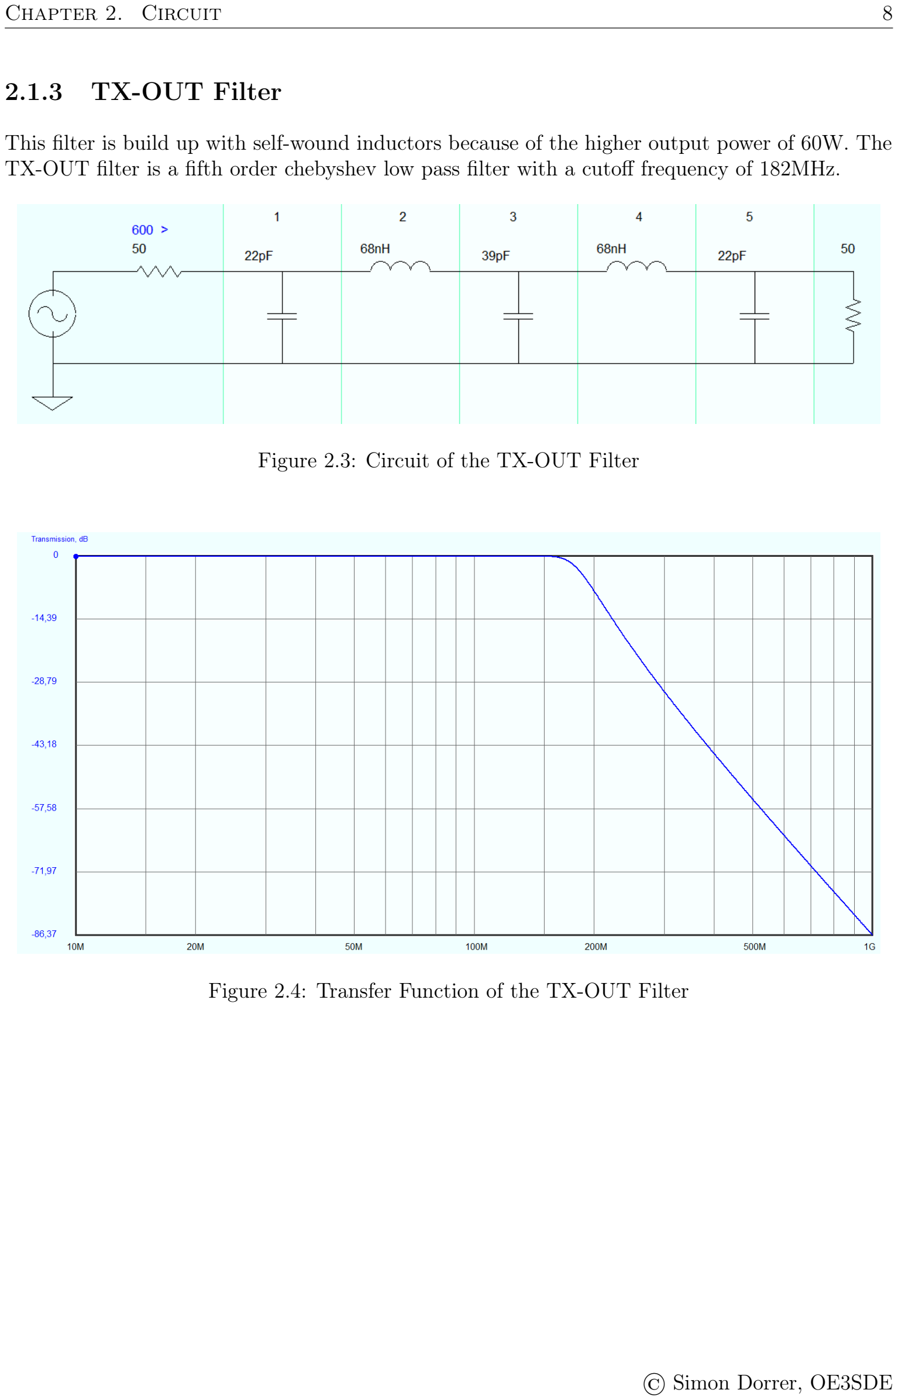
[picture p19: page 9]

Chapter 2. | Circuit | 8

This filter is build up with self-wound inductors because of the higher output power of 60W. The TX-OUT filter is a fifth order chebyshev low pass filter with a cutoff frequency of 182MHz.

### Figure 2.3: Circuit of the TX-OUT Filter

### Figure 2.4: Transfer Function of the TX-OUT Filter

## 2.1.4 RX-IN Filter

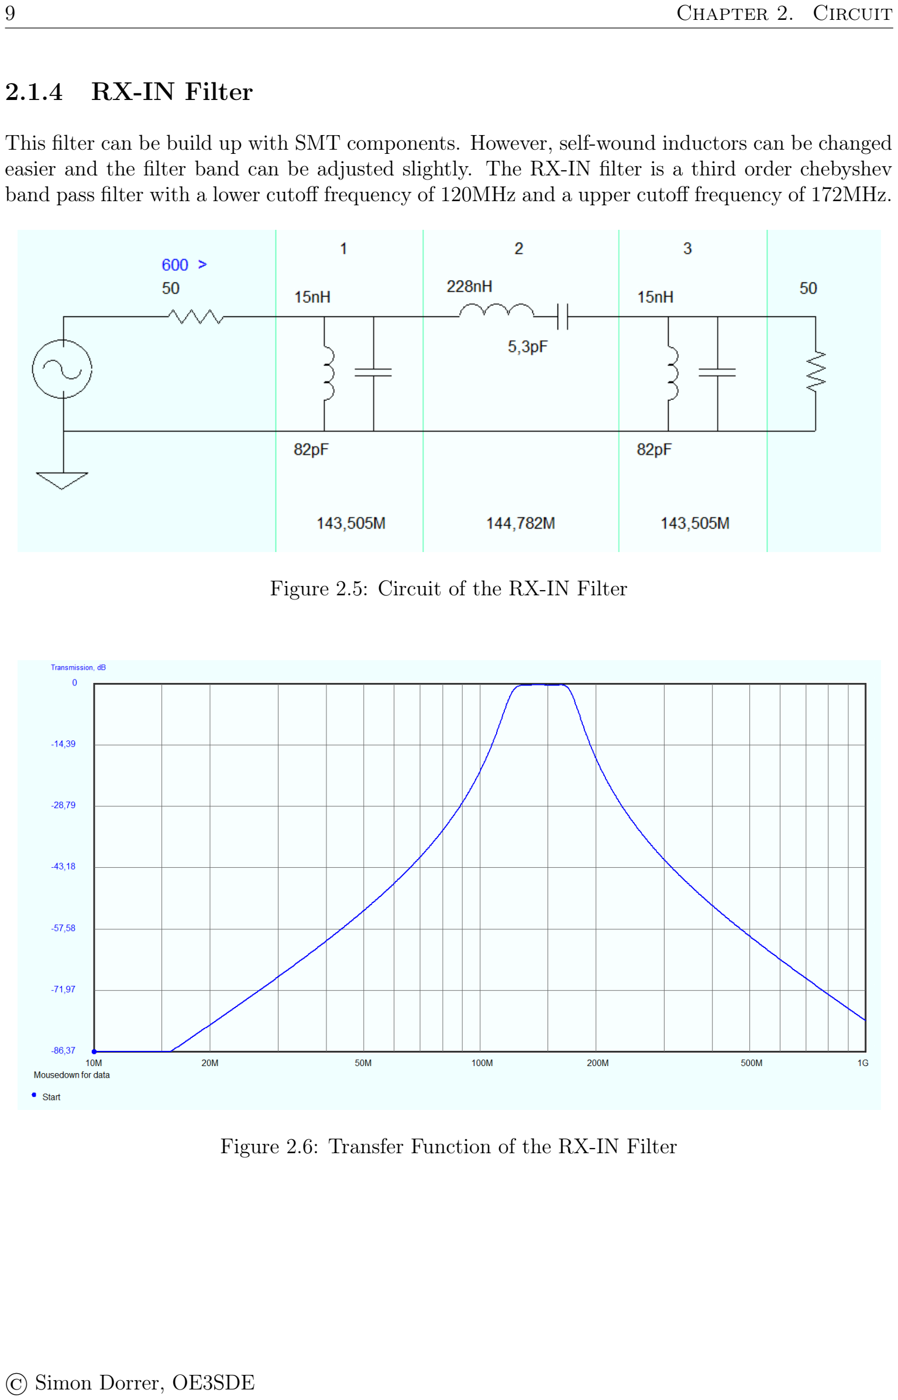
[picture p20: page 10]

9 | Chapter 2. | Circuit

This filter can be build up with SMT components. However, self-wound inductors can be changed easier and the filter band can be adjusted slightly. The RX-IN filter is a third order chebyshev band pass filter with a lower cutoff frequency of 120MHz and a upper cutoff frequency of 172MHz.

### Figure 2.5: Circuit of the RX-IN Filter

### Figure 2.6: Transfer Function of the RX-IN Filter

Chapter 2. | Circuit | 10

## 2.2 PIN-Diode Switches

In this project, PIN-Diodes are used instead of relais to switch between RX and TX path.

## 2.2.1 RX/TX Input-Switch

### ToDo Text

# Image

### Figure 2.7: Circuit of the RX/TX Input-Switch

11 | Chapter 2. | Circuit

## 2.2.2 RX/TX Output-Switch

### ToDo Text

# Image

### Figure 2.8: Circuit of the RX/TX Output-Switch

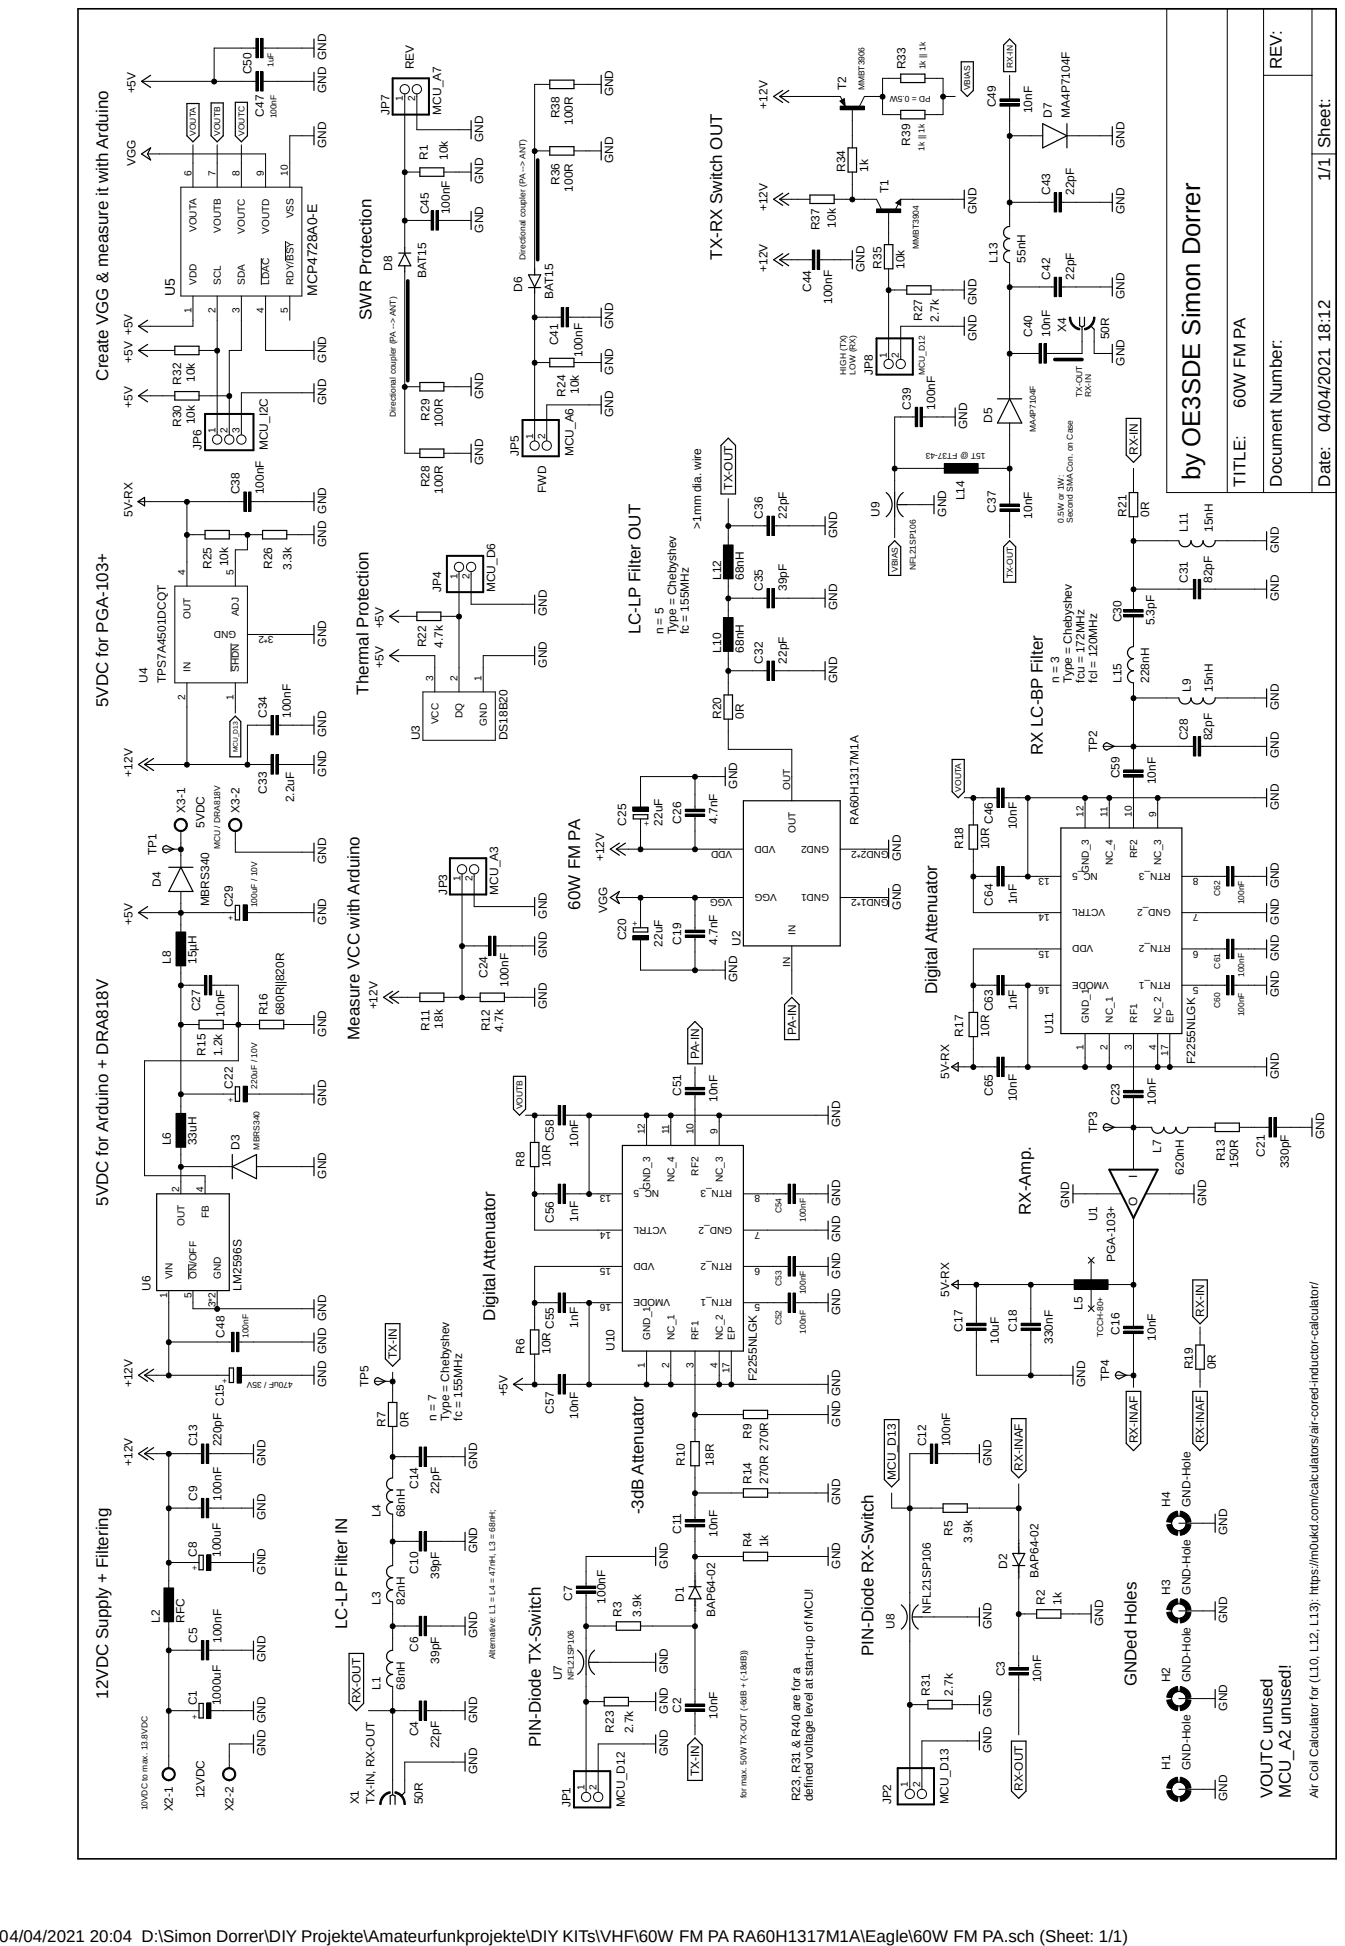
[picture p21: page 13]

I O Date: Sheet: REV: TITLE: Document Number: 04/04/2021 18:12 1/1 60W FM PA

9 EP 17 VMODE 16 VDD 15 VCTRL 14 NC_5 13 U11 C59 C60 C61 C62 R17 C63 C64 R18 C65 C46 R31 R27 R23 C48 C1 H2 H3 H4 D7 R34 T2 T1 R39 R33 L14 C40 C42 C43 L15 C49

2 JP8 R24 R1 L13 TX-OUT TX-OUT RX-IN RX-IN RX-IN PA-INPA-IN TX-IN TX-IN MCU_D13 MCU_D13 RX-INAF RX-INAF RX-INAF VOUTB VOUTB VOUTA VOUTA VOUTC VBIAS VBIAS RX-OUT RX-OUT

9 EP 17 VMODE 16 VDD 15 VCTRL 14 NC_5 13 U10 C51 C52 C53 C54 R6 C55 C56 R8 C57 C58 R9 R10 R14 GND_1

13 | Chapter 3. | PCB

# Chapter 3

# PCB

## 3.1 Layer Stackup

This PCB! is a two layer PCB. On the top layer the RF! signals and SMT components are placed. The bottom layer is a completed GND layer with some supply traces. This PCB is produced by

### my sponsor JLCPCB 1 . Normally, for bigger RF PCB-Designs a 4 layer PCB is used as follows:

### Image Figure 3.1: Two Layer PCB Stackup

1https://jlcpcb.com/

Chapter 3. | PCB | 14

## 3.2 Coplanar Waveguide Grounded (CPWG)

In RF PCB-Design applications it is very important, that the trace impedance is matched to 50Ω. Therefore, different techniques like Microstrip, Stripline or Coplanar Waveguide are used. This PCB-Design uses the Coplanar Waveguide method. However, the calculation of this technique is

### not that easy (elliptical integrals etc.). That is why an online calculator 2 [2] is used. The original

equations are in [3] on page 79.

## 3.2.1 RX CPWG Calculation


### Figure 3.2: RX CPWG Calculation

## 3.2.2 TX CPWG Calculation


### Figure 3.3: TX CPWG Calculation

2https://chemandy.com/calculators/coplanar-waveguide-with-ground-calculator.htm

## 3.3 Trace corners

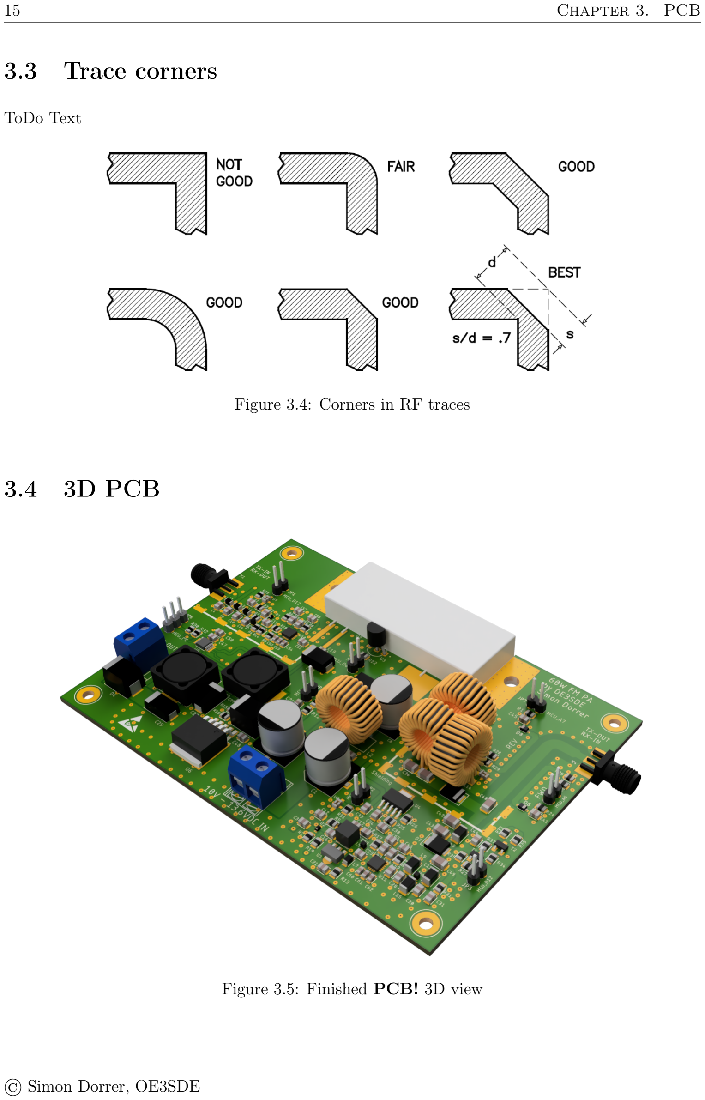
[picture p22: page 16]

15 | Chapter 3. | PCB

### ToDo Text

### Figure 3.4: Corners in RF traces

## 3.4 3D PCB

### Figure 3.5: Finished PCB! 3D view

## 3.5 2D PCB

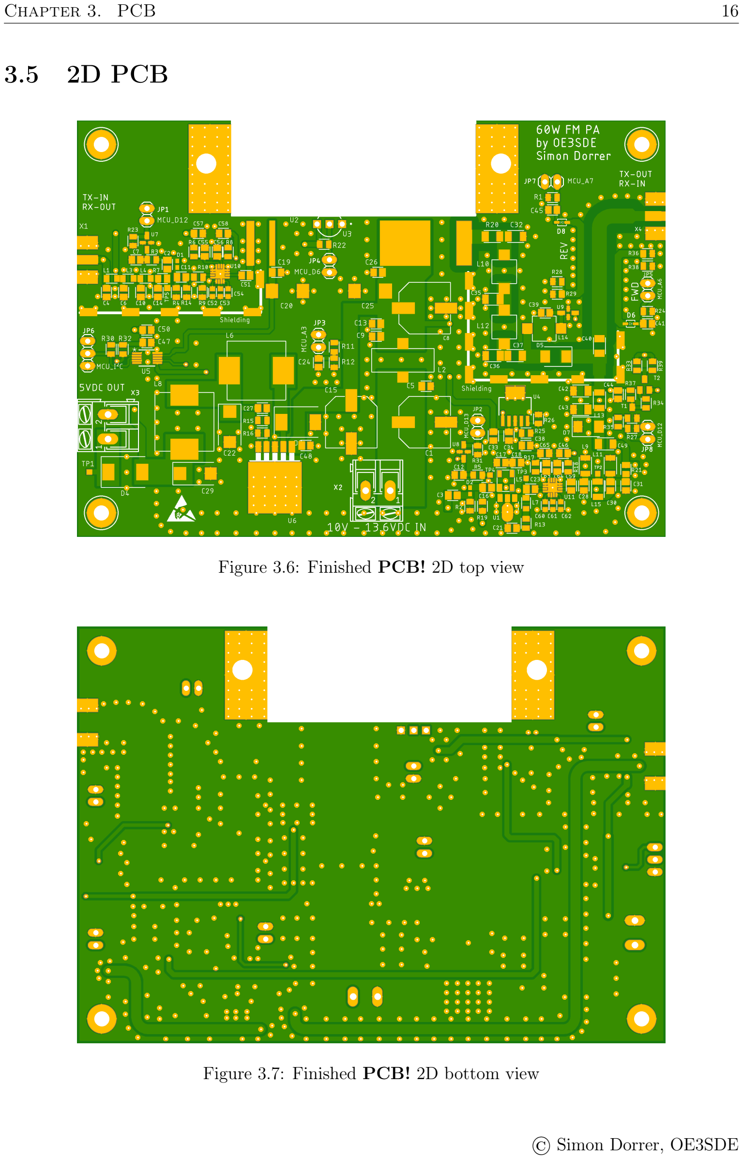
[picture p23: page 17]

Chapter 3. | PCB | 16

### Figure 3.6: Finished PCB! 2D top view

### Figure 3.7: Finished PCB! 2D bottom view

17 | Chapter 4. | Bill of Material

# Chapter 4

# Bill of Material

Qty | Value | Parts
4 | 0R | R7, R19, R20, R21
1 | 1.2k | R15
1 | 1000uF | C1
4 | 100R | R28, R29, R36, R38
6 | 100nF | C52, C53, C54, C60, C61, C62
13 | 100nF | C5, C7, C9, C12, C24, C34, C38, C39, C41, C44, C45, C47, C48
1 | 100uF | C8
1 | 100uF / 10V | C29
4 | 10R | R6, R8, R17, R18
7 | 10k | R1, R24, R25, R30, R32, R35, R37
12 | 10nF | C2, C3, C11, C16, C23, C27, C46, C51, C57, C58, C59, C65
3 | 10nF | C37, C40, C49
1 | 10uF | C17
1 | 12VDC | X2
1 | 150R | R13
1 | 15T @ FT37-43 | L14
2 | 15nH | L9, L11
1 | 15ÁH | L8
1 | 18R | R10
1 | 18k | R11
3 | 1k | R2, R4, R34
2 | 1k || 1k | R33, R39
4 | 1nF | C55, C56, C63, C64
1 | 1uF | C50
1 | 2.2uF | C33
3 | 2.7k | R23, R27, R31
1 | 220pF | C13
1 | 220uF / 10V | C22
1 | 228nH | L15
2 | 22pF | C4, C14
4 | 22pF | C32, C36, C42, C43
2 | 22uF | C20, C25
2 | 270R | R9, R14

Chapter 4. | Bill of Material | 18
Qty | Value | Parts
1 | 3.3k | R26
2 | 3.9k | R3, R5
1 | 330nF | C18
1 | 330pF | C21
1 | 33uH | L6
2 | 39pF | C6, C10
1 | 39pF | C35
2 | 4.7k | R12, R22
2 | 4.7nF | C19, C26
1 | 470uF / 35V | C15
1 | 5.3pF | C30
1 | 50R | X4
1 | 55nH | L13
1 | 5VDC | X3
1 | 620nH | L7
1 | 680R||820R | R16
2 | 68nH | L10, L12
2 | 68nH | L1, L4
1 | 82nH | L3
2 | 82pF | C28, C31
2 | BAP64-02 | D1, D2
2 | BAT15 | D6, D8
1 | DS18B20 | U3
2 | F2255NLGK | U10, U11
4 | GND-Hole | H1, H2, H3, H4
1 | LM2596S | U6
2 | MA4P7104F | D5, D7
2 | MBRS340 | D3, D4
1 | MCP4728A0-E | U5
1 | MMBT3904 | T1
1 | MMBT3906 | T2
3 | NFL21SP106 | U7, U8, U9
1 | PGA-103+ | U1
1 | RA60H1317M1A | U2
1 | RFC | L2
1 | TCCH-80+ | L5
1 | TPS7A4501DCQT | U4
5 | TPSTP10SQ | TP1, TP2, TP3, TP4, TP5
1 | TX-IN, RX-OUT | X1

### Table 4.1: Bill of Material

19 | Chapter 5. | Measurements

# Chapter 5

# Measurements

## 5.1 TX-Path Transfer Function

### ToDo Text (Variable Gain with Vdd of RA60, XY V for every gain)

## 5.1.1 TF of RA60H1317M1A

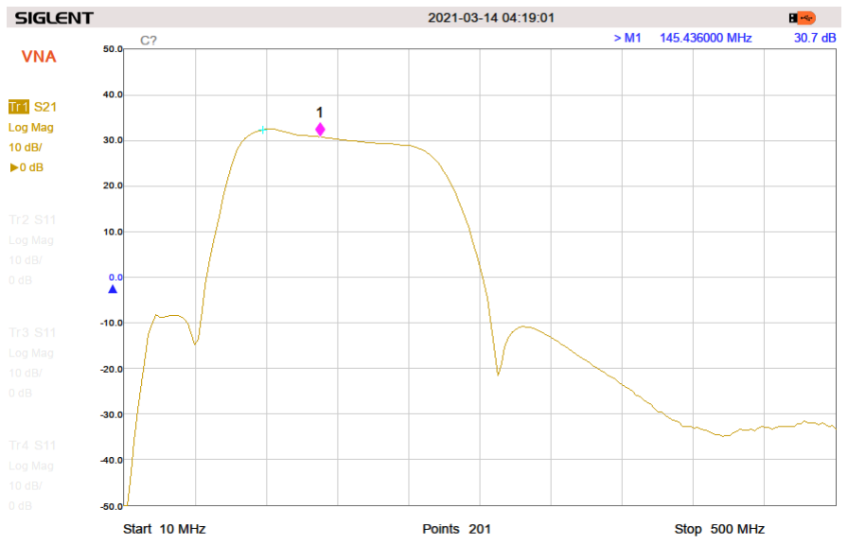
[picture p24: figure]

### Figure 5.1: Transfer Function of RA60H1317M1A

Chapter 5. | Measurements | 20

## 5.1.2 10dB Gain

# Image

### Figure 5.2: TX-Path Transfer Function with 10dB gain

## 5.1.3 30dB Gain

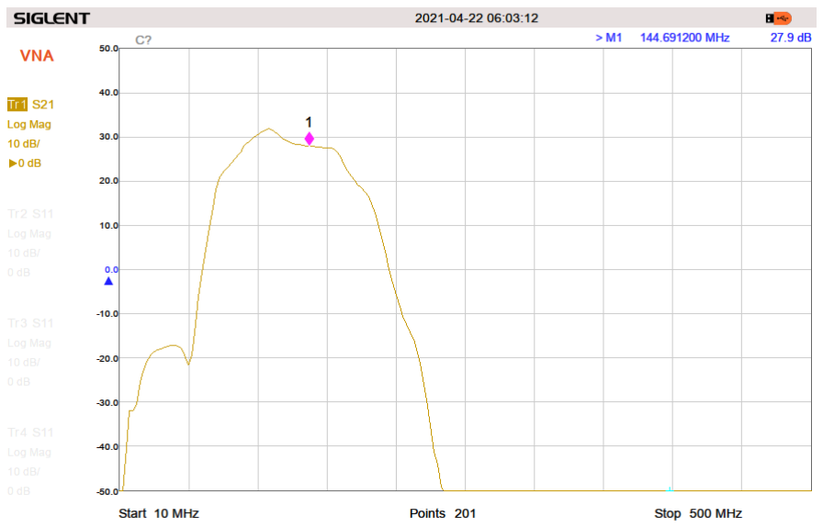
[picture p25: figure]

### Figure 5.3: TX-Path Transfer Function with 30dB gain

21 | Chapter 5. | Measurements

## 5.2 RX-Path Transfer Function

### ToDo Text (Variable Attenuation with F2255)

## 5.2.1 F2255NLGK Attenuation Diagram

### ToDo Text (What is a F2255)

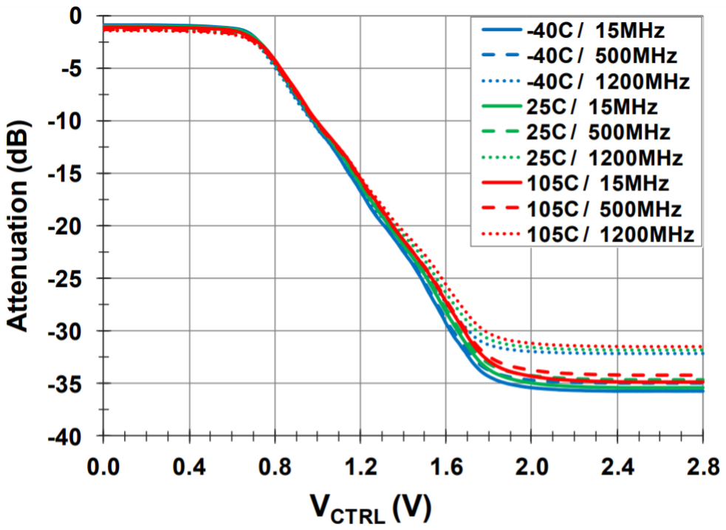
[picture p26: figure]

### Figure 5.4: F2255NLGK Attenuation Diagram¹

[4]

1https://www.mouser.at/datasheet/2/698/IDT_F2255_Datasheet_DST_20180209-1997542.

pdf (https://www.mouser.at/datasheet/2/698/IDT_F2255_Datasheet_DST_20180209-1997542.pdf)

Chapter 5. | Measurements | 22

## 5.2.2 No Attenuation

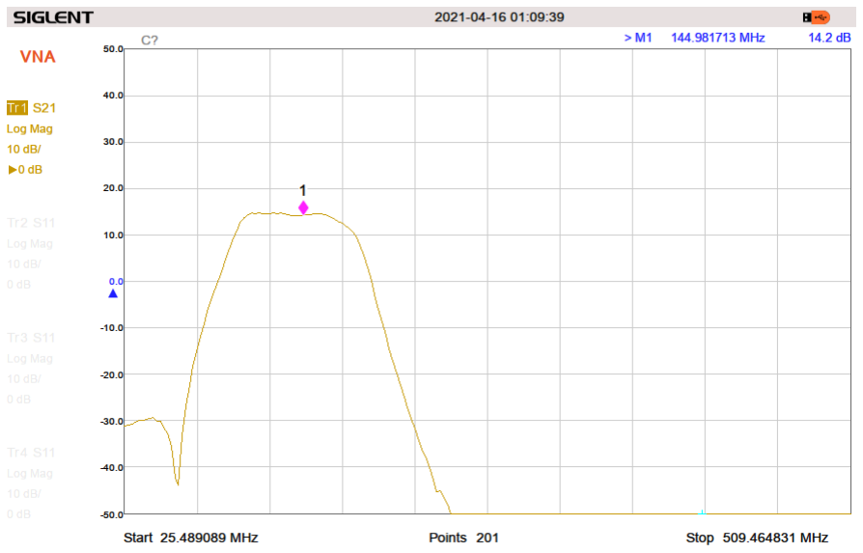
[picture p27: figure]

### Figure 5.5: RX-Path Transfer Function without attenuation

## 5.2.3 20dB Attenuation

### Image Figure 5.6: RX-Path Transfer Function with 20dB attenuation

23 | Chapter 5. | Measurements

## 5.3 Output Power

### For all output power measurements an input power of XYdBm (xyW) is used. Furthermore, at

the input of the Vector Network Analyzer a 23dBm attenuator is mounted to handle the power. So, the final output Power consists of the measured power and the 23dBm.
For exmaple, if the spectrum analyser shows an output power of XYdBm the output power equals XY + 23dBm = dBm(XY W).

## 5.3.1 20W Output Power

# Image

### Figure 5.7: 20W Output Power

Chapter 5. | Measurements | 24

## 5.3.2 40W Output Power

# Image

### Figure 5.8: 40W Output Power

## 5.3.3 60W Output Power

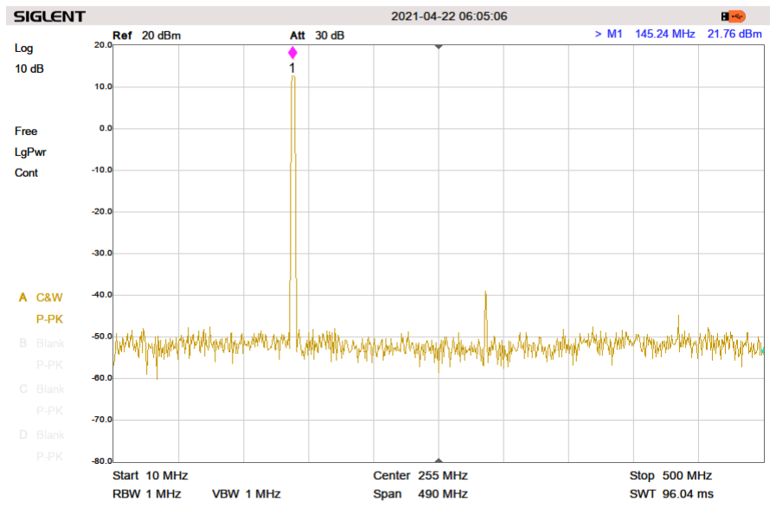
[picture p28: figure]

### Figure 5.9: 60W Output Power

25 | Chapter 6. | Microcontroller Code

# Chapter 6

# Microcontroller Code

In this chapter, the MCU Code written with Arduino IDE is implemented. The internal hardware of the used MCU (ATmega328) is programmed on register level. To control the OLED display, the external DAC and some sensors, external libraries are used.

1 //Arduino Code for DRA818V FM TRX + 60W RA60H1317M1A
2 //This code is written by OE3SDE, Simon Dorrer!
3
4 //Define CPU-Clock-Speed (16MHz internal clock)
5 //#define F_CPU 16000000UL
6
7 //Define Baudrate for UART
8 //#define BAUD 9600UL
9
10 //Include Libraries
11 #include <avr/io.h>
12 #include <stdio.h>
13 #include <avr/interrupt.h>
14
15 //I2C
16 #include <Wire.h>
17
18 //MCP4728
19 #include <Adafruit_MCP4728.h>
20
21 //DS18B20
22 #include <OneWire.h>
23 #include <DallasTemperature.h>
24
25 //Libs. for SD1306 OLED-Display
26 #include <Adafruit_GFX.h> | // Include core graphics
library for the display
27 #include <Adafruit_SSD1306.h> | // Include Adafruit_SSD1306
library to drive the display
28 #include <Fonts/FreeMono9pt7b.h> | // Add a custom font
29 /*List of different fonts :

Chapter 6. | Microcontroller Code | 26

30 FreeMono9pt7b.h
31 FreeMonoBold9pt7b.h
32 FreeMonoBoldOblique9pt7b.h 33 FreeMonoOblique9pt7b.h
34 */
35 //

36
37 //Definitions
38 //I/O Declaration
39 //1W FM TRX Board (DRA818V)
40 //#define TX | 0 | //PD0 / D0
41 //#define RX | 1 | //PD1 / D1
42 #define SW1 | 2 | //PD2 / D2 - INT0
43 #define PTT_IN | 3 | //PD3 / D3 - INT1
44 #define PTT_OUT | 7 | //PD7 / D7
45 #define PD | 0 | //PB0 / D8
46 #define H_L | 1 | //PB1 / D9
47 #define HC05_TX | 2 | //PB2 / D10
48 #define HC05_RX | 3 | //PB3 / D11
49 #define E1 | 0 | //PC0 / A0
50 #define E2 | 1 | //PC1 / A1
51
52 //60W FM TRX Board (RA60H1317M1A)
53 #define PGA_SHDN | 5 | //PB5 / D13 (LOW --> PGA OFF, HIGH --> PGA
ON) + RX Switch
54 #define TX_SW | 4 | //PB4 / D12 (HIGH TX Switch)
55 //#define T1_SW | 7 | //PD7 / D7 | (switches T1 for TRX Switch -
LOW for TX, HIGH for RX) --> see PTT_OUT D7
56 #define DS18B20_OW | 6 | //PD6 / D6 | (One wire input of DS18B20 Temp
. Sensor)
57 #define SWR_REV | 7 | //PC7 / A7 | (ADC samples reverse voltage)
58 #define SWR_FWD | 6 | //PC6 / A6 | (ADC samples forward voltage)
59 #define ADC_VDD | 3 | //PC3 / A3 | (ADC samples VDD voltage)
60
61 //I2C: OLED Display, MCP4728
62
63 //Makros
64 //RX or TX ATTENUATOR
65 #define RX_ATTENUATOR_CHANNEL | MCP4728_CHANNEL_A
66 #define TX_ATTENUATOR_CHANNEL | MCP4728_CHANNEL_B
67
68 //PA max. ratings
69 #define VDD_LOWER_LIMIT 10.7 | //in V
70 #define VDD_UPPER_LIMIT 14.2 | //in V
71 #define SWR_LOWER_LIMIT 0.5
72 #define SWR_UPPER_LIMIT 2

27 | Chapter 6. | Microcontroller Code
73 #define HEAT_UPPER_LIMIT 45 | //in degrees
74 //

75
76 //Global variables / Objects
77 uint8_t TX = 0; // 0... RX; 1... TX 78 uint8_t switched = 0;
79
80 //OLED
81 Adafruit_SSD1306 display(128, 64); | // Create display
82 volatile uint16_t timer1Count = 0;
83
84 //DRA818 Variables
85 typedef struct{
86 | float txFreq; | //TX-Frequency in MHz (134.0000 - 174.0000)
87 | float rxFreq; | //RX-Frequency in MHz (134.0000 - 174.0000)
88 | String txCTCSS; | //CTCSS frequency (0000 - 0038); 0000 = "no
CTCSS"
89 | String rxCTCSS; | //CTCSS frequency (0000 - 0038); 0000 = "no
CTCSS"
90 | uint8_t bw; | //Bandwith in KHz (0= 12.5KHz or 1= 25KHz)
91 | uint8_t squ; | //Squelch level | (0 - 8); 0 = "open"
92 | uint8_t vol;
93 | uint8_t prf;
94 | uint8_t hpf;
95 | uint8_t lpf;
96 }DRA818;
97
98 DRA818 dra818 = {145.5000, 145.5000, "0000", "0000", 1, 4, 8, 0, 0,
| 0};
99
100 //DS18B20
101 OneWire oneWire(DS18B20_OW);
102 DallasTemperature ds18b20(&oneWire);
103
104 //MCP4728
105 Adafruit_MCP4728 mcp4728;
106
107 //Rotary Encoder Variables 108 int counter = 0;
109 int aState;
110 int aLastState;
111
112 //RA60H1317M1A Variables 113 float txGain = 10;
114 float txAtt = 0;
115 float rxAtt = 0;

Chapter 6. | Microcontroller Code | 28
116 uint8_t monitorPA = 0; | //monitorPA = 1... PA is OK!
117 //

118
119 //Subprograms
120 //Hardware Init Methods
121 void IO_Init() | //initialize IO
122 {
123 | //Define INPUTs
124 | DDRD &= ~(1 << SW1); | //set PD2 (SW1) as Input
125 | PORTD |= (1 << SW1); | //activate Pull-Up-R at PD2 (SW1)
126
127 | DDRD &= ~(1 << PTT_IN); | //set PD3 (PTT-IN) as Input
128 | PORTD |= (1 << PTT_IN); | //activate Pull-Up-R at PD3 (PTT_IN)
129
130 | DDRC &= ~(1 << E1); | //set PC0 (E1) as Input
131 | DDRC &= ~(1 << E2); | //set PC1 (E2) as Input
132
133 | DDRC &= ~(1 << ADC_VDD); | //set PC3 (ADC_VDD) as Input
134 | //PORTC |= (1 << ADC_VDD); | //activate Pull-Up-R at PC3 (
| ADC_VDD)
135
136 | DDRC &= ~(1 << SWR_FWD); | //set PC6 (SWR_FWD) as Input
137 | PORTC |= (1 << SWR_FWD); | //activate Pull-Up-R at PC6 (SWR_FWD)
138
139 | DDRC &= ~(1 << SWR_REV); | //set PC7 (SWR_REV) as Input
140 | PORTC |= (1 << SWR_REV); | //activate Pull-Up-R at PC7 (SWR_REV)
141
142 | //Define OUTPUTs
143 | DDRD |= (1 << PTT_OUT); | //set PD7 (PTT_OUT) as Output
144 | DDRB |= (1 << PD); | //set PB0 (PD) as Output
145 | DDRB |= (1 << H_L); | //set PB1 (H_L) as Output
146
147 | DDRB |= (1 << TX_SW); | //set PB4 (TX_Switch) as Output
148 | DDRB |= (1 << PGA_SHDN); | //set PB5 (PGA_SHDN) as Output
149 }
150
151 void Timer1_COMPA_Init()
152 {
153 | //Control Registers
154 | TCCR1A = 0; TCCR1B = 0; TCCR1C = 0; //Reset
155
156 | // set CTC mode
157 | //TCCR1A |= (1 << WGM10);
158 | //TCCR1A |= (1 << WGM11);
159 | TCCR1B |= (1 << WGM12);
160

29 | Chapter 6. | Microcontroller Code
161 | // Set Prescaler 1024 (TCCR1B = (1 << WGM12) | (0x5 << CS10);)
162 | TCCR1B |= (1 << CS12);
163 | TCCR1B &= ~(1 << CS11);
164 | TCCR1B |= (1 << CS10);
165
166 | // initialize compare value
167 | OCR1A = 16;
168
169 | // enable timer compare interrupt
170 | TIMSK1 |= (1 << OCIE1A);
171 }
172
173 void Timer2_COMPA_Init()
174 {
175 | //Timer2 settings
176 | TCCR2A = 0x00; TCCR2B = 0x00; //Reset
177
178 | //Enable Timer2 CTC Mode
179 | //TCCR2A |= (1 << WGM20);
180 | TCCR2A |= (1 << WGM21);
181 | //TCCR2B |= (1 << WGM22);
182
183 | //Prescaler
184 | // 1024 prescaling for Timer2 (TCCR2B = (0x7 << CS20);)
185 | TCCR2B |= (1 << CS20);
186 | TCCR2B |= (1 << CS21);
187 | TCCR2B |= (1 << CS22);
188
189 | //Initialize compare value
190 | OCR2A = 0;
191
192 | //initialize TIMER0-Counter
193 | //TCNT2 = 0; // set counter value FORMEL: x = maximaler Zaehlwert -
| ((CPUtakt/PRESCALER)/ gesuchte Frequenz)
194
195 | //disable Timer compare interrupt
196 | TIMSK2 &= ~(1 << OCIE2A);
197 }
198
199 void INT0_Init()
200 {
201 | //enable Interrupt
202 | EIMSK |= (1 << INT0); //Ext. Int0 ein
203
204 | //Set falling Edge Interrupt (EICRA |= (0x2 << ISC00);)
205 | EICRA &= ~(1 << ISC00);
206 | EICRA |= (1 << ISC01);
207 }

Chapter 6. | Microcontroller Code | 30

208 void INT1_Init()
209 {
210 | //enable Interrupt
211 | EIMSK |= (1 << INT1); //Ext. Int1 ein
212
213 | //Set rising & falling Edge Interrupt (EICRA |= (0x2 << ISC10);)
214 | EICRA |= (1 << ISC10);
215 | EICRA &= ~(1 << ISC11);
216 }
217
218 void ADC_Init()
219 {
220 | //ADC Setup
221 | //Set Reference Voltage (VCC = VREF)
222 | ADMUX &= ~(1 << REFS1);
223 | ADMUX |= (1 << REFS0);
224
225 | //Prescaler --> 128 (50kHz - 200kHz)
226 | ADCSRA |= (1 << ADPS0);
227 | ADCSRA |= (1 << ADPS1);
228 | ADCSRA |= (1 << ADPS2);
229
230 ADCSRA |= (1 << ADEN); //Enable ADC
231
232 | //Dummy Readout to warm up the ADC
233 | ADCSRA |= (1<<ADSC); | //Start ADC conclusion
234 | while (ADCSRA & (1<<ADSC)){} | //wait until ADC is ready
235 | (void) ADC;
236 }
237 uint16_t ADC_ReadValue(uint8_t channel)
238 {
239 ADMUX = (ADMUX & ~(0x1F)) | (channel & 0x1F); //which ADCx? Bit
Mask to secure ADMUX settings in Init() function
240
241 | ADCSRA |= (1<<ADSC); | //Start ADC conclusion
242 | while (ADCSRA & (1<<ADSC)){} | //wait until ADC is ready
243
244 | return ADC; | //return the ADC value
245 }
246
247 //DRA818V Methods
248 void DRA818V_setGroup()
249 {
250 | Serial.print("AT+DMOSETGROUP="); | // begin message
251 | Serial.print(dra818.bw);
252 | Serial.print(",");
253 | Serial.print(dra818.txFreq, 4);
254 | Serial.print(",");

31 | Chapter 6. | Microcontroller Code
255 | Serial.print(dra818.rxFreq, 4);
256 | Serial.print(",");
257 | Serial.print(dra818.txCTCSS);
258 | Serial.print(",");
259 | Serial.print(dra818.squ);
260 | Serial.print(",");
261 | Serial.println(dra818.rxCTCSS);
262 }
263 void DRA818V_setVolume()
264 {
265 | Serial.print("AT+DMOSETVOLUME=");
266 | Serial.println(dra818.vol);
267 }
268 void DRA818V_setFilter()
269 {
270 | Serial.print("AT+SETFILTER=");
271 | Serial.print(dra818.prf);
272 | Serial.print(",");
273 | Serial.print(dra818.hpf);
274 | Serial.print(",");
275 | Serial.println(dra818.lpf);
276 }
277 void DRA818V_Init() | // initialize DRA818V
278 {
279 | PORTB &= ~(1 << PD);
280 | delay(2000);
281
282 | //I/O
283 | PORTD |= (1 << PTT_OUT); | // set PD7 (PTT_OUT) HIGH at the
| beginning (RX-Mode)
284 | PORTB |= (1 << PD); | // set PB0 (PD) HIGH at the beginning
| (Normal-Mode)
285 | PORTB &= ~(1 << H_L); | // set PB1 (H/L) LOW at the beginning
| (LOW-Power = 0.5W)
286
287 | //UART
288 | Serial.begin(9600);
289 | delay(10);
290 | DRA818V_setGroup();
291 | delay(500);
292 | DRA818V_setVolume();
293 | delay(500);
294 | DRA818V_setFilter();
295 | delay(500);
296 }
297
298 //RA60H1317M1A Methods
299 float getVDD() | //Get VDD Voltage (10.8VDC to 13.6VDC)

Chapter 6. | Microcontroller Code | 32

300 {
301 | float vdd = 0;
302 | // #PJN: You may spend a LOT of time in this loop => make ADC
reading asynchronous
303
304 vdd = ADC_ReadValue(ADC_VDD) * 5.0 / 1024.0;
305
306 | return((vdd * ((4700 + 18000) / 4700)) + 2.2); | //returns supply
voltage without voltage division (magic numbers equals the voltage divider resistor values)
307 }
308 float getSWR() | //Get SWR of output load (should be between 0.5
and 2)
309 {
310 | float rev = 0;
311 | float fwd = 0;
312 | // #PJN: You may spend just more time in this loop => make ADC
reading asynchronous
313 | for(int i = 0; i < 10; i++) | //10 iterations for a more precise
result
314 | {
315 | rev = rev + ADC_ReadValue(SWR_REV);
316 | fwd = fwd + ADC_ReadValue(SWR_FWD);
317 | }
318 | rev = rev / 10 / 1024 * 5;
319 | fwd = fwd / 10 / 1024 * 5;
320
321 | //SWR Calculation
322 | return((fwd + rev) / (fwd - rev));
323 }
324 float getPWR()
325 {
326 | float fwd = 0;
327 | for(int i = 0; i < 10; i++) | //10 iterations for a more precise
result
328 | {
329 | fwd = fwd + ADC_ReadValue(SWR_FWD);
330 | }
331 | fwd = fwd / 10 / 1024 * 5;
332
333 | //PWR Calculation
334 | return((fwd * fwd) / 50);
335 }
336 float getHeat() | //Get heat of RA60H1317M1A measured by DS18B20,
should be smaller than 50
337 {
338 | ds18b20.requestTemperatures();
339 | return(ds18b20.getTempCByIndex(0));

33 | Chapter 6. | Microcontroller Code

340 }
341 void setTXGain(float gain) //Set Gain of RA60H1317M1A via MCP4728 ( VOUTD)
342 {
343 | if(gain == 0)
344 | {
345 | mcp4728.setChannelValue(MCP4728_CHANNEL_D, 0);
346 | }
347 | else
348 | {
349 | //ToDo Formula
350 | mcp4728.setChannelValue(MCP4728_CHANNEL_D, 4095);
351 | }
352 }
353 void setAttenuation(MCP4728_channel_t channel, float att) //
| Attenuation of U11 (RX) or U12 (TX) (F2255NLGK)
354 {
355 | //Note that the PGA-103 has a constant gain of 25dB for RX path!
| RX_ATTENUATOR_CHANNEL MCP4728_CHANNEL_A
356 | //Note that an 6dB Attenuator is assembled on board for TX path!
| TX_ATTENUATOR_CHANNEL MCP4728_CHANNEL_B
357
358 | if(att > 35)
359 | {
360 | mcp4728.setChannelValue(channel, 2048);
361 | }
362 | else if(att < 2.5)
363 | {
364 | mcp4728.setChannelValue(channel, 0);
365 | }
366 | else
367 | {
368 | att = att * (-1);
369 | mcp4728.setChannelValue(channel, (uint16_t)(4096 * (-0.03692 *
att + 0.60769) / 5)); | //0.7V (-2.5dB) to 1.9V (-35dB), magic
numbers are calculated according to the attenuation curve of
| the datasheet!
370 | }
371 }
372 void switchPAtoTX(uint8_t TX_Att, uint8_t TX_Gain)
373 {
374 | if(monitorPA == 1)
375 | {
376 | //turn OFF RX:
377 | mcp4728.setChannelValue(MCP4728_CHANNEL_C, 0); | //turn RX Path
| in TRX Switch OFF (VOUTC to LOW)
378 | PORTB &= ~(1 << PGA_SHDN); | //turn OFF PGA
| RX-Amp. and RX Switch (D13 to LOW)

Chapter 6. | Microcontroller Code | 34
379 | setAttenuation(RX_ATTENUATOR_CHANNEL, 36); | //set full
attenuation of U11 (F2255NLGK)
380
381 | delay(100); | //100ms settling time
382
383 | //turn ON TX:
384 | PORTD &= ~(1 << PTT_OUT); | //turn TX Path
in TRX Switch ON (D7 LOW)
385 | PORTB |= (1 << TX_SW); | //turn on TX
Switch (D12 to HIGH)
386 | setAttenuation(TX_ATTENUATOR_CHANNEL, TX_Att); | //set
attenuation of U12 (F2255NLGK)
387 | setTXGain(TX_Gain); | //Set TX gain (
VGG (Gate) voltage) of RA60H1317M1A
388 | delay(100); | //100ms
settling time
389 | }
390 | else
391 | {
392 | switchPAtoRX(rxAtt);
393 | }
394 }
395 void switchPAtoRX(float RX_Att)
396 {
397 | //turn OFF TX:
398 | setTXGain(0); | //Set gain of
RA60H1317M1A to 0
399 | setAttenuation(TX_ATTENUATOR_CHANNEL, 36); | //set full
attenuation of U12 (F2255NLGK)
400 | PORTB &= ~(1 << TX_SW); | //turn OFF TX
Switch (D12 to LOW)
401 | PORTD |= (1 << PTT_OUT); | //turn TX Path
in TRX Switch OFF (D7 HIGH)
402 | delay(100); | //100ms
settling time
403
404 | //turn ON RX
405 | mcp4728.setChannelValue(MCP4728_CHANNEL_C, 4095); | //turn RX Path
in TRX Switch ON (VOUTC to HIGH)
406 | PORTB |= (1 << PGA_SHDN); | //turn ON PGA
RX-Amp. and RX Switch (D13 to HIGH)
407 | setAttenuation(RX_ATTENUATOR_CHANNEL, RX_Att); | //set
attenuation of U11 (F2255NLGK)
408 | delay(100); | //100ms
settling time
409 }
410 void verifyPA() //Shutdown RA60H1317M1A according to SWR, VDD and Heat

35 | Chapter 6. | Microcontroller Code

411 {
412 | float vdd = getVDD();
413 | float swr = getSWR();
414 | float heat = getHeat();
415 | Serial.print("VDD: ");
416 | Serial.println(vdd);
417 | Serial.print("SWR: ");
418 | Serial.println(swr);
419 | Serial.print("HEAT: ");
420 | Serial.println(heat);
421
422 //if((vdd >= VDD_LOWER_LIMIT && vdd <= VDD_UPPER_LIMIT) && (swr >= SWR_LOWER_LIMIT && swr <= SWR_UPPER_LIMIT) && heat <= HEAT_UPPER_LIMIT)
423 if((vdd >= VDD_LOWER_LIMIT && vdd <= VDD_UPPER_LIMIT) && heat <= HEAT_UPPER_LIMIT)
424 | {
425 | monitorPA = 1; | //PA is OK!
426 | }
427 | else
428 | {
429 | monitorPA = 0;
430 | if(TX == 1)
431 | {
432 | switchPAtoRX(rxAtt);
433 | }
434 | }
435 }
436
437 //Display Methods
438 void displayInit()
439 {
440 | delay(100); | // This delay is needed
to let the display to initialize 441 if(!display.begin(SSD1306_SWITCHCAPVCC, 0x3C)){ // Address 0x3C for 128x32
442 | Serial.println(F("SSD1306 allocation failed"));
443 | while (1){
444 | delay(10);
445 | }
446 | }
447 | display.clearDisplay(); | // Clear the buffer
448 | display.setTextColor(WHITE); | // Set color of the
text
449 | //display.setRotation(2); | // Set orientation.
Goes from 0, 1, 2 or 3
450 | display.setTextWrap(false); | // By default, long
lines of text are set to automatically "wrap" back to the

Chapter 6. | Microcontroller Code | 36

leftmost column.
451 // To override this behavior (so text will run off the right side of the display - useful for scrolling marquee effects), use setTextWrap(false).
452 | display.dim(0); | //Set brightness (0 is
| maximun and 1 is a little dim)
453 | display.setFont(&FreeMono9pt7b); | // Set a custom font
454 | display.setTextSize(0); | // Set text size. We
are using a custom font so you should always use the text size
| of 0
455 | display.display(); | // Print everything we
| set previously
456 }
457 void displayStartScreen()
458 {
459 | display.setCursor(10, 15); | // (x,y)
460 | display.println("60W FM TRX"); | // Text or value to
| print
461 | display.setCursor(10, 35); | // (x,y)
462 | display.println("by OE3SDE"); | // Text or value to
| print
463 | display.setCursor(10, 55); | // (x,y)
464 | display.println("S. Dorrer"); | // Text or value to
| print
465 | display.display(); | // Print everything we
| set previously
466 }
467 void refreshDisplay()
468 {
469 display.clearDisplay();
470
471 | // TX / RX
472 | if(TX == 1)
473 | {
474 | display.setCursor(10, 15); | // (x,y)
475 | display.println("TX");
476 | }
477 | else if(TX == 0)
478 | {
479 | display.setCursor(10, 15); | // (x,y)
480 | display.println("RX");
481 | }
482
483 | // Power
484 | display.setCursor(50, 15); | // (x,y)
485 | display.println("PWR:.5W");
486
487 // Frequency

37 | Chapter 6. | Microcontroller Code
488 | display.setCursor(30, 35); | // (x,y)
489 | display.println(dra818.txFreq);
490
491 | //Values
492 | display.setCursor(2, 55); | // (x,y)
493 | display.print(getVDD()); | // Text or value to
| print
494 | display.print(" ");
495 | display.print(getHeat()); | // Text or value to
| print
496 | display.display();
497 }
498 //

499
500 //Setup (Initialize hardware) 501 void setup()
502 {
503 | //HW Init
504 | IO_Init();
505 | INT0_Init();
506 | INT1_Init();
507 | Timer1_COMPA_Init();
508 | Timer2_COMPA_Init();
509 | ADC_Init();
510
511 | // OLED Init
512 | displayInit();
513 | displayStartScreen();
514
515 | //DRA818V Init
516 | DRA818V_Init();
517
518 | //DS18B20 Init
519 | ds18b20.begin();
520
521 | //MCP4728 Init
522 | if(!mcp4728.begin()){
523 | Serial.println("Failed to find MCP4728 chip!");
524 | while (1){
525 | delay(10);
526 | }
527 | }
528
529 | //RA60H1317M1A
530 | verifyPA();
531 | switchPAtoRX(rxAtt); //standard attenuation of 10dB

Chapter 6. | Microcontroller Code | 38

532
533 sei(); //enable global interrupts
534
535 | //Reads the initial state of the outputA (E2)
536 | aLastState = digitalRead(E2); | // #PJN: wondering why you’re now
using the digitalRead() because output handling is done via direct register access - it’s however OK anyways
537
538 | display.clearDisplay();
539 | display.display();
540 }
541 //

542

### 543 //Loop

544 void loop()
545 {
546 | if(timer1Count >= 500)
547 | {
548 | timer1Count = 0;
549 | verifyPA();
550 | refreshDisplay();
551 | }
552
553 | if(TX == 1 && switched == 1)
554 | {
555 | switchPAtoTX(txAtt, txGain); | //PA PCB is transmitting now!
556 | //PORTD &= ~(1 << PTT_OUT); | //DRA818V TX (done in
| switchPAtoTX)
557 | switched = 0;
558 | }
559 | else if (TX == 0 && switched == 1)
560 | {
561 | //PORTD |= (1 << PTT_OUT); | //DRA818V RX (done in
| switchPAtoRX)
562 | switchPAtoRX(rxAtt); | //PA PCB is receiving now!
563 | switched = 0;
564 | }
565
566 | // #PJN: Because of the above code you’ll get a lot of jitter when
| reading the encoder below
567 | aState = digitalRead(E2); // Reads the "current" state of the
| outputA
568 | // If the previous and the current state of the outputA are
different, that means a Pulse has occured
569 | if (aState != aLastState)
570 | {

39 | Chapter 6. | Microcontroller Code

// If the outputB state is different to the outputA state, that means the encoder is rotating clockwise
if (digitalRead(E1) != aState)
{
counter++;
}
else
{
counter--;
}
}
aLastState = aState; // Updates the previous state of the outputA with the current state
582 }
583 //

585 //ISP (Interrupt Service Routine) 586 ISR(TIMER1_COMPA_vect) // every 1ms
587 {
timer1Count++;
589 }

591 ISR(TIMER2_COMPA_vect) // execute by TIMER2 CTC
592 {
static uint16_t timer2Count = 0; //only at first ISR call

timer2Count++; //inkrementieren

if(timer2Count == 4000) //256ms sperren
{
//enable INT0
EIMSK |= (1 << INT0); //Ext. Int0 on

//enable INT1
EIMSK |= (1 << INT1); //Ext. Int0 on

//clear INTF0
EIFR |= (1 << INTF0);

//clear INTF1
EIFR |= (1 << INTF1);

//disable TIMER2 compare interrupt TIMSK2 &= ~(1 << OCIE2A);

//reset of counter value

Chapter 6. | Microcontroller Code | 40
615 | timer2Count = 0;
616 | }
617 }
618
619 ISR(INT0_vect) //Rotary Encoder Switch
620 {
621 static uint8_t encoderPressedCounter = 1; //only at first ISR call
622
623 uint8_t temp = SREG; //Store SREG
624
625 encoderPressedCounter++;
626
627 | //DEBOUNCE
628 | //disable INT0
629 | EIMSK &= ~(1 << INT0); //Ext. INT0 off
630 | //enable TIMER2 compare interrupt
631 | TIMSK2 |= (1 << OCIE2A);
632
633 | switch (encoderPressedCounter)
634 | {
635 | case 1:
636 | // #PJN: Off topic: channel spacing on 2m is 12.5 kHz ... maybe
just increase/decrease frequency values instead of fixed ones?
637 | dra818.txFreq = 145.5000; | //TX-Frequency in MHz
638 | dra818.rxFreq = 145.5000; | //RX-Frequency in MHz
639 | DRA818V_setGroup();
640 | break;
641 | case 2:
642 | dra818.txFreq = 144.2000; | //TX-Frequency in MHz
643 | dra818.rxFreq = 144.2000; | //RX-Frequency in MHz
644 | DRA818V_setGroup();
645 | break;
646 | case 3:
647 | dra818.txFreq = 144.5000; | //TX-Frequency in MHz
648 | dra818.rxFreq = 144.5000; | //RX-Frequency in MHz
649 | DRA818V_setGroup();
650 | break;
651 | case 4:
652 | dra818.txFreq = 145.2000; | //TX-Frequency in MHz
653 | dra818.rxFreq = 145.2000; | //RX-Frequency in MHz
654 | DRA818V_setGroup();
655 | break;
656 | case 5:
657 | dra818.txFreq = 145.0000; | //TX-Frequency in MHz
658 | dra818.rxFreq = 145.0000; | //RX-Frequency in MHz
659 | DRA818V_setGroup();
660 | encoderPressedCounter = 0;
661 | break;

41 | Chapter 6. | Microcontroller Code
662 | default:
663 | encoderPressedCounter = 0;
664 | break;
665 | }
666
667 SREG = temp;
668 }
669
670 ISR(INT1_vect) //PTT-IN (active LOW)
671 {
672 | //DEBOUNCE
673 | //disable INT1
674 | //EIMSK &= ~(1 << INT1); //Ext. INT1 off
675 | //enable TIMER2 compare interrupt
676 | //TIMSK2 |= (1 << OCIE2A);
677
678 switched = 1;
679
680 | if(!(PIND & (1 << PTT_IN))) | //PTT_IN changed to LOW
681 | {
682 | //switchPAtoTX(txAtt, txGain); | //PA PCB is transmitting now!
683 | //PORTD &= ~(1 << PTT_OUT); | //DRA818V TX (done in
| switchPAtoTX)
684 | TX = 1;
685 | }
686 | else if (PIND & (1 << PTT_IN)) | //PTT_IN changed to HIGH
687 | {
688 | //PORTD |= (1 << PTT_OUT); | //DRA818V RX (done in
| switchPAtoRX)
689 | //switchPAtoRX(rxAtt); | //PA PCB is receiving now!
690 | TX = 0;
691 | }
692 }
693 //

694 //End of Code!

Chapter 7. | Enclosure | 42

# Chapter 7

# Enclosure

Unfortunately, the 3D enclosure is not finished yet. In the end, the enclosure will be 3D printed.

43 | Chapter 8. | Result Pictures

# Chapter 8

# Result Pictures

## 8.1 Assembled PCB

### ToDo Text

### Image Figure 8.1: Assembled PCB

Chapter 8. | Result Pictures | 44

## 8.2 Transceiver with Power Amplifier

### ToDo Text

# Image

### Figure 8.2: DRA818V Transceiver with Power Amplifier

## 8.3 Implemented in Enclosure

Unfortunately, the 3D enclosure is not finished yet.

45 | List of Abbreviations

# List of Abbreviations

ADC | analog to digital converter
CMOS | complementary metal oxide semiconductor
CW | continuous wave
DAC | digital to analog converter
MCU | microcontroller unit
IC | integrated circuit
LNA | low noise amplifier
LPF | lowpass filter
HPF | highpass filter
BPF | bandpass filter
LUT | lookup table
PA | power amplifier
PCB | printed circuit board
RF | radio frequency
RX | receive
SNR | signal to noise ratio
SSB | single sideband
TX | transmit
TRX | transceiver
FM | frequency modulation

List of Figures | 46

# List of Figures

2.1 Circuit of the TX-IN Filter | | 7
2.2 Transfer Function of the TX-IN Filter | | 7
2.3 Circuit of the TX-OUT Filter | | 8
2.4 Transfer Function of the TX-OUT Filter | | 8
2.5 Circuit of the RX-IN Filter | | 9
2.6 Transfer Function of the RX-IN Filter | | 9
2.7 Circuit of the RX/TX Input-Switch | | 10
2.8 Circuit of the RX/TX Output-Switch | | 11
3.1 Two Layer PCB Stackup | | 13
3.2 RX CPWG Calculation | | 14
3.3 TX CPWG Calculation | | 14
3.4 Corners in RF traces | | 15
3.5 Finished PCB! 3D view | | 15
3.6 Finished PCB! 2D top view | | 16
3.7 Finished PCB! 2D bottom view | | 16
5.1 Transfer Function of RA60H1317M1A | | 19
5.2 TX-Path Transfer Function with 10dB gain | | 20
5.3 TX-Path Transfer Function with 30dB gain | | 20

### 5.4 F2255NLGK Attenuation Diagram¹

[4] | | 21
5.5 RX-Path Transfer Function without attenuation | | 22
5.6 RX-Path Transfer Function with 20dB attenuation | | 22
5.7 20W Output Power | | 23
5.8 40W Output Power | | 24
5.9 60W Output Power | | 24
8.1 Assembled PCB | | 43
8.2 DRA818V Transceiver with Power Amplifier | | 44

47 | List of Tables

# List of Tables

Bibliography | 48

# Bibliography

### [1] M0UKD. Online air cored inductor calculator. [Online]. Available: https://m0ukd.com/

calculators/air-cored-inductor-calculator/ (https://m0ukd.com/calculators/air-cored-inductor-calculator/)

[2] C. ELECTRONICS. Online coplanar waveguide grounded impedance calculator. [Online]. Available: https://chemandy.com/calculators/coplanar-waveguide-with-ground-calculator.

### htm (https://chemandy.com/calculators/coplanar-waveguide-with-ground-calculator.htm)

[3] B. C. Wadell, Transmission Line Design Handbook. Artech House, 1991.

### [4] R. E. Corporation. Datasheet f2255nlgk - digital controllable rf attenuator. [Online]. Available: https://www.mouser.at/datasheet/2/698/IDT_F2255_Datasheet_DST_

20180209-1997542.pdf (https://www.mouser.at/datasheet/2/698/IDT_F2255_Datasheet_DST_20180209-1997542.pdf)

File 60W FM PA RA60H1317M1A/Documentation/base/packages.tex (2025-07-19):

%% !TeX document-id = {b8e7f259-21c3-4834-b29d-9cf620be8d99}
%% !BIB program = biber
\documentclass[12pt, twoside]{report}

%Language Settings:
\usepackage[utf8]{inputenc}
\usepackage[english]{babel}
\usepackage[T1]{fontenc}		%Separation pattern

\usepackage{geometry}

\usepackage{fancyhdr}

%Text generation
\usepackage{lipsum}	

%Tables
\usepackage{numprint}
\usepackage{longtable}						%Table over several pages
\usepackage[table]{xcolor}

%Pictures
\usepackage{float}
\usepackage{graphicx}

%Verweise
\usepackage{url}
\usepackage{hyperref}

%Math
\usepackage{amsmath}
\usepackage{amssymb}

\usepackage[nottoc]{tocbibind}

%Bibliography
%\usepackage{biblatex}
%\addbibresource{bibliography.bib}

% Acronyms
\usepackage{acronym}

%PDF Pages
\usepackage{pdfpages}

%Adding Arduino Language
\input{./6_code/arduinoLanguage}

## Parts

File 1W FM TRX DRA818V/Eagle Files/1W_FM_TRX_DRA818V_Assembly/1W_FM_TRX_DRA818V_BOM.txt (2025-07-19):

Partlist exported from E:/Simon Dorrer/DIY Projekte/Amateurfunkprojekte/DIY KITs/VHF/1W FM TRX DRA818V/Eagle Files/1W FM TRX DRA818V.sch at 24/02/2021 19:53

Qty Value        Device                      Package                         Parts                       Description                                                                                                   AVAILABILITY DESCRIPTION MF                 MP      MPN          OC_FARNELL OC_NEWARK PACKAGE                POPULARITY PRICE PROD_ID    SF_ID     SPICEMODEL SPICEPREFIX SPICEPREFIXL
7   100nF        C-EUC0805K                  C0805K                          C2, C3, C4, C5, C8, C9, C10 CAPACITOR, European symbol                                                                                                                                                                                                 52                                               C                       
1   10R          R-EU_R0805                  R0805                           R2                          RESISTOR, European symbol                                                                                                                                                                                                  86                                               R                       
1   10k          R-TRIMM3314J                RTRIM3314J                      R5                          Trimm resistor                                                                                                                                                                                                             0                                     X                      POT         
1   10uF         C-EUC0805K                  C0805K                          C1                          CAPACITOR, European symbol                                                                                                                                                                                                 52                                               C                       
1   1N4004       1N4004                      DO41-10                         D1                          DIODE                                                                                                                                                                                                                      82                                                                       
1   2.5mm        AUDIO_JACK_2.5MM_2.5MM      STEREOJACK2.5MM_STEREOJACK2.5MM J2                          Audio Jack                                                                                                                                                                                                                                  CONN-09878                                              
2   22pF         C-EUC0805K                  C0805K                          C6, C7                      CAPACITOR, European symbol                                                                                                                                                                                                 52                                               C                       
2   2k           R-EU_R0805                  R0805                           R3, R6                      RESISTOR, European symbol                                                                                                                                                                                                  86                                               R                       
1   3.5mm        AUDIO_JACK_3.5MM_PTH        AUDIO-JACK                      J1                          Audio Jack                                                                                                                                                                                                                                  CONN-08774 PRT-08032                                    
2   4.7k         R-EU_R0805                  R0805                           R4, R7                      RESISTOR, European symbol                                                                                                                                                                                                  86                                               R                       
1   470R         R-EU_R0805                  R0805                           R1                          RESISTOR, European symbol                                                                                                                                                                                                  86                                               R                       
1   60nH         L-EUL8530M                  L8530M                          L1                          INDUCTOR, European symbol                                                                                                                                                                                                  0                                                L                       
1   Arduino Nano ARDUINO_NANO                ARDUINO_NANO                    U2                          Arduino Nano V3.0                                                                                                                                                                                                                                                                                   
1   DRA818V      DRA818V                     DORJI_DRA818V                   U1                          VHF Band Voice Transceiver Module                                                                             Unavailable              DORJI              DRA818V                                   Package Analog Devices            None                                                          
1   EC11E        ENCODER_SW1-PEC12           EC11E_INCREMENTAL_ENCODER       SW1                         Incremental Encoder with push switch                                                                                                                                                                                                                                                                
1   HC-05        PINHD-1X6                   1X06                            X4                          PIN HEADER                                                                                                                                                                                                                                                                                          
1   OLED         PINHD-1X4                   1X04                            X3                          PIN HEADER                                                                                                                                                                                                                                                                                          
1   PTT-OUT      PINHD-1X2                   1X02                            X5                          PIN HEADER                                                                                                                                                                                                                                                                                          
1   RF-OUT       SMA-PCB-CON142-0711-821/826 J502-ND-142-0711-821/826        X1                          SMA 50 Ohm End Launch Jack Receptacle - Round Contact                                                                                  JOHNSON COMPONENTS         142-0711-821 1019328    16F3627                                                                                                   
1   USB Micro    USB""                       USB-MICRO-SMD                   U3                          This is a USB AB connector that is compatible with USB OTG. i.e. this connector can serve as a host or device                                                                                                                                                                                       
1   red          LEDCHIP-LED0805             CHIP-LED0805                    LED1                        LED

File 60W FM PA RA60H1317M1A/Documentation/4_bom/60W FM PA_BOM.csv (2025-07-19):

Qty | Value | Device | Package | Parts | Description | BUILT_BY | CATEGORY | COPYRIGHT | CREATED_BY | CURRENT_RATING | DATASHEET_URL | DESCRIPTION | DIGIKEY_PART_NUMBER | FAMILY_NAME | FORWARD_CURRENT | GENERIC_PART_NUMBER | HEIGHT | INDUSTRY_STD_PKG_TYPE | MANUFACTURER | MANUFACTURER_NAME | MANUFACTURER_PART_NUMBER | MF | MOUSER_PART_NUMBER | MOUSER_PRICE-STOCK | MPN | OC_FARNELL | OC_NEWARK | OPERATING_TEMP | PACKAGE | PACKAGE_DESIGNATOR | PART_STATUS | PIN_COUNT | POPULARITY | RATING | REVERSE_VOLTAGE | REVISION | ROHS_COMPLIANT | SERIES | SOURCELIBRARY | SPICEPREFIX | SUB-CATEGORY | THERMALLOSS | TOLERANCE | TP_SIGNAL_NAME | TYPE | VALUE | VENDOR | VOLTAGE_RATING
3 | 0R | R_CHIP-0805(2012-METRIC) | RESC2012X65 | R7, R19, R21 | Resistor Fixed - Generic |  | Resistor |  |  |  |  |  |  |  |  |  |  |  |  |  |  |  |  |  |  |  |  |  |  |  |  |  |  |  |  |  |  |  |  |  | Fixed
1 | 0R | R_CHIP-1206(3216-METRIC) | RESC3216X70 | R20 | Resistor Fixed - Generic |  | Resistor |  |  |  |  |  |  |  |  |  |  |  |  |  |  |  |  |  |  |  |  |  |  |  |  |  |  |  |  |  |  |  |  |  | Fixed
1 | 1.2k | R_CHIP-0805(2012-METRIC) | RESC2012X65 | R15 | Resistor Fixed - Generic |  | Resistor |  |  |  |  |  |  |  |  |  |  |  |  |  |  |  |  |  |  |  |  |  |  |  |  |  |  |  |  |  |  |  |  |  | Fixed
1 | 1000uF | C-POL_ECAP-10.5MM | CAPAE1030X1050N | C1 | Capacitor Polarised - Generic |  | Capacitor
4 | 100R | R_CHIP-0805(2012-METRIC) | RESC2012X65 | R28, R29, R36, R38 | Resistor Fixed - Generic |  | Resistor |  |  |  |  |  |  |  |  |  |  |  |  |  |  |  |  |  |  |  |  |  |  |  |  |  |  |  |  |  |  |  |  |  | Fixed
6 | 100nF | C_CHIP-0603(1608-METRIC) | CAPC1608X85 | C52, C53, C54, C60, C61, C62 | Capacitor - Generic |  | Capacitor
13 | 100nF | C_CHIP-0805(2012-METRIC) | CAPC2012X110 | C5, C7, C9, C12, C24, C34, C38, C39, C41, C44, C45, C47, C48 | Capacitor - Generic |  | Capacitor
1 | 100uF | C-POL_ECAP-10.5MM | CAPAE1030X1050N | C8 | Capacitor Polarised - Generic |  | Capacitor
1 | 100uF / 10V | C-POL_TANTALUM-2917(7343-METRIC) | CAPMP7343X310N | C29 | Capacitor Polarised - Generic |  | Capacitor
4 | 10R | R_CHIP-0805(2012-METRIC) | RESC2012X65 | R6, R8, R17, R18 | Resistor Fixed - Generic |  | Resistor |  |  |  |  |  |  |  |  |  |  |  |  |  |  |  |  |  |  |  |  |  |  |  |  |  |  |  |  |  |  |  |  |  | Fixed
7 | 10k | R_CHIP-0805(2012-METRIC) | RESC2012X65 | R1, R24, R25, R30, R32, R35, R37 | Resistor Fixed - Generic |  | Resistor |  |  |  |  |  |  |  |  |  |  |  |  |  |  |  |  |  |  |  |  |  |  |  |  |  |  |  |  |  |  |  |  |  | Fixed
12 | 10nF | C_CHIP-0805(2012-METRIC) | CAPC2012X110 | C2, C3, C11, C16, C23, C27, C46, C51, C57, C58, C59, C65 | Capacitor - Generic |  | Capacitor
3 | 10nF | C_CHIP-1206(3216-METRIC) | CAPC3216X135 | C37, C40, C49 | Capacitor - Generic |  | Capacitor
1 | 10uF | C_CHIP-0805(2012-METRIC) | CAPC2012X110 | C17 | Capacitor - Generic |  | Capacitor
1 | 12VDC | AK300/2 | AK300/2 | X2 | CONNECTOR |  |  |  |  |  |  |  |  |  |  |  |  |  |  |  |  |  |  |  |  | unknown | unknown |  |  |  |  |  | 16
1 | 150R | R_CHIP-0805(2012-METRIC) | RESC2012X65 | R13 | Resistor Fixed - Generic |  | Resistor |  |  |  |  |  |  |  |  |  |  |  |  |  |  |  |  |  |  |  |  |  |  |  |  |  |  |  |  |  |  |  |  |  | Fixed
1 | 15T @ FT37-43 | AIR-COIL | AIR-COIL-SMD | L14
2 | 15nH | L_CHIP-1206(3216-METRIC) | INDC3216X190 | L9, L11 | Inductor Fixed - Generic |  | Inductor |  |  |  |  |  |  |  |  |  |  |  |  |  |  |  |  |  |  |  |  |  |  |  |  |  |  |  |  |  |  |  |  |  | Fixed
1 | 15µH | L-EU | 1260 | L8 | INDUCTOR, European symbol
1 | 18R | R_CHIP-0805(2012-METRIC) | RESC2012X65 | R10 | Resistor Fixed - Generic |  | Resistor |  |  |  |  |  |  |  |  |  |  |  |  |  |  |  |  |  |  |  |  |  |  |  |  |  |  |  |  |  |  |  |  |  | Fixed
1 | 18k | R_CHIP-0805(2012-METRIC) | RESC2012X65 | R11 | Resistor Fixed - Generic |  | Resistor |  |  |  |  |  |  |  |  |  |  |  |  |  |  |  |  |  |  |  |  |  |  |  |  |  |  |  |  |  |  |  |  |  | Fixed
3 | 1k | R_CHIP-0805(2012-METRIC) | RESC2012X65 | R2, R4, R34 | Resistor Fixed - Generic |  | Resistor |  |  |  |  |  |  |  |  |  |  |  |  |  |  |  |  |  |  |  |  |  |  |  |  |  |  |  |  |  |  |  |  |  | Fixed
2 | 1k || 1k | R_CHIP-0805(2012-METRIC) | RESC2012X65 | R33, R39 | Resistor Fixed - Generic |  | Resistor |  |  |  |  |  |  |  |  |  |  |  |  |  |  |  |  |  |  |  |  |  |  |  |  |  |  |  |  |  |  |  |  |  | Fixed
4 | 1nF | C_CHIP-0805(2012-METRIC) | CAPC2012X110 | C55, C56, C63, C64 | Capacitor - Generic |  | Capacitor
1 | 1uF | C_CHIP-0805(2012-METRIC) | CAPC2012X110 | C50 | Capacitor - Generic |  | Capacitor
1 | 2.2uF | C_CHIP-0805(2012-METRIC) | CAPC2012X110 | C33 | Capacitor - Generic |  | Capacitor
3 | 2.7k | R_CHIP-0805(2012-METRIC) | RESC2012X65 | R23, R27, R31 | Resistor Fixed - Generic |  | Resistor |  |  |  |  |  |  |  |  |  |  |  |  |  |  |  |  |  |  |  |  |  |  |  |  |  |  |  |  |  |  |  |  |  | Fixed
1 | 220pF | C_CHIP-0805(2012-METRIC) | CAPC2012X110 | C13 | Capacitor - Generic |  | Capacitor
1 | 220uF / 10V | C-POL_TANTALUM-2917(7343-METRIC) | CAPMP7343X310N | C22 | Capacitor Polarised - Generic |  | Capacitor
1 | 228nH | L_CHIP-1206(3216-METRIC) | INDC3216X190 | L15 | Inductor Fixed - Generic |  | Inductor |  |  |  |  |  |  |  |  |  |  |  |  |  |  |  |  |  |  |  |  |  |  |  |  |  |  |  |  |  |  |  |  |  | Fixed
2 | 22pF | C_CHIP-0805(2012-METRIC) | CAPC2012X110 | C4, C14 | Capacitor - Generic |  | Capacitor
4 | 22pF | C_CHIP-1206(3216-METRIC) | CAPC3216X135 | C32, C36, C42, C43 | Capacitor - Generic |  | Capacitor
2 | 22uF | CPOL-EUSMCD | SMC_D | C20, C25 | POLARIZED CAPACITOR, European symbol |  |  |  |  |  |  |  |  |  |  |  |  |  |  |  |  |  |  |  |  |  |  |  |  |  |  |  | 0 |  |  |  |  |  |  | C
2 | 270R | R_CHIP-0805(2012-METRIC) | RESC2012X65 | R9, R14 | Resistor Fixed - Generic |  | Resistor |  |  |  |  |  |  |  |  |  |  |  |  |  |  |  |  |  |  |  |  |  |  |  |  |  |  |  |  |  |  |  |  |  | Fixed
1 | 3.3k | R_CHIP-0805(2012-METRIC) | RESC2012X65 | R26 | Resistor Fixed - Generic |  | Resistor |  |  |  |  |  |  |  |  |  |  |  |  |  |  |  |  |  |  |  |  |  |  |  |  |  |  |  |  |  |  |  |  |  | Fixed
2 | 3.9k | R_CHIP-0805(2012-METRIC) | RESC2012X65 | R3, R5 | Resistor Fixed - Generic |  | Resistor |  |  |  |  |  |  |  |  |  |  |  |  |  |  |  |  |  |  |  |  |  |  |  |  |  |  |  |  |  |  |  |  |  | Fixed
1 | 330nF | C_CHIP-0805(2012-METRIC) | CAPC2012X110 | C18 | Capacitor - Generic |  | Capacitor
1 | 330pF | C_CHIP-0805(2012-METRIC) | CAPC2012X110 | C21 | Capacitor - Generic |  | Capacitor
1 | 33uH | L-EU | 1260 | L6 | INDUCTOR, European symbol
2 | 39pF | C_CHIP-0805(2012-METRIC) | CAPC2012X110 | C6, C10 | Capacitor - Generic |  | Capacitor
1 | 39pF | C_CHIP-1206(3216-METRIC) | CAPC3216X135 | C35 | Capacitor - Generic |  | Capacitor
2 | 4.7k | R_CHIP-0805(2012-METRIC) | RESC2012X65 | R12, R22 | Resistor Fixed - Generic |  | Resistor |  |  |  |  |  |  |  |  |  |  |  |  |  |  |  |  |  |  |  |  |  |  |  |  |  |  |  |  |  |  |  |  |  | Fixed
2 | 4.7nF | C_CHIP-0805(2012-METRIC) | CAPC2012X110 | C19, C26 | Capacitor - Generic |  | Capacitor
1 | 470uF / 35V | C-POL_ECAP-10.5MM | CAPAE1030X1050N | C15 | Capacitor Polarised - Generic |  | Capacitor
1 | 5.3pF | C_CHIP-0805(2012-METRIC) | CAPC2012X110 | C30 | Capacitor - Generic |  | Capacitor
1 | 50R | SMA-142-0711-821/826 | J502-ND-142-0711-821/826 | X4 | SMA 50 Ohm End Launch Jack Receptacle - Round Contact |  |  |  |  |  |  |  |  |  |  |  |  |  |  |  |  | JOHNSON COMPONENTS |  |  | 142-0711-821 | 1019328 | 16F3627 |  |  |  |  |  | 0
1 | 55nH | L_CHIP-1206(3216-METRIC) | INDC3216X190 | L13 | Inductor Fixed - Generic |  | Inductor |  |  |  |  |  |  |  |  |  |  |  |  |  |  |  |  |  |  |  |  |  |  |  |  |  |  |  |  |  |  |  |  |  | Fixed
1 | 5VDC | AK300/2 | AK300/2 | X3 | CONNECTOR |  |  |  |  |  |  |  |  |  |  |  |  |  |  |  |  |  |  |  |  | unknown | unknown |  |  |  |  |  | 16
1 | 620nH | L_CHIP-0805(2012-METRIC) | INDC2009X120 | L7 | Inductor Fixed - Generic |  | Inductor |  |  |  |  |  |  |  |  |  |  |  |  |  |  |  |  |  |  |  |  |  |  |  |  |  |  |  |  |  |  |  |  |  | Fixed
1 | 680R||820R | R_CHIP-0805(2012-METRIC) | RESC2012X65 | R16 | Resistor Fixed - Generic |  | Resistor |  |  |  |  |  |  |  |  |  |  |  |  |  |  |  |  |  |  |  |  |  |  |  |  |  |  |  |  |  |  |  |  |  | Fixed
2 | 68nH | AIR-COIL | AIR-COIL-SMD | L10, L12
2 | 68nH | L_CHIP-0805(2012-METRIC) | INDC2009X120 | L1, L4 | Inductor Fixed - Generic |  | Inductor |  |  |  |  |  |  |  |  |  |  |  |  |  |  |  |  |  |  |  |  |  |  |  |  |  |  |  |  |  |  |  |  |  | Fixed
1 | 82nH | L_CHIP-0805(2012-METRIC) | INDC2009X120 | L3 | Inductor Fixed - Generic |  | Inductor |  |  |  |  |  |  |  |  |  |  |  |  |  |  |  |  |  |  |  |  |  |  |  |  |  |  |  |  |  |  |  |  |  | Fixed
2 | 82pF | C_CHIP-0805(2012-METRIC) | CAPC2012X110 | C28, C31 | Capacitor - Generic |  | Capacitor
2 | BAP64-02 | DIODE-SOD523 | SOD523 | D1, D2 | DIODE |  |  |  |  |  |  |  |  |  |  |  |  |  |  |  |  |  |  |  |  |  |  |  |  |  |  |  | 3
2 | BAT15 | 1N4148WS | SOD-323 | D6, D8 | DIODE GEN PURP 75V 150MA SOD323F |  |  |  | PCBLayout.com |  |  |  | 1N4148WSFSTR-ND |  |  |  |  |  | Diodes Incorporated |  |  |  |  |  | 1N4148WS |  |  |  | SOD-323
1 | DS18B20 | DS1810-10 | 21-0248A_MXM | U3 |  | EMA_UL_Team |  |  |  |  |  |  |  |  |  |  |  |  |  |  | DS1810-10 |  |  |  |  |  |  |  |  |  |  |  |  |  |  | 2 |  |  | Maxim_2011-05-13 |  |  |  |  |  |  |  | Maxim Integrated Products
2 | F2255NLGK | F2255NLGK | QFN50P300X300X100-17N | U10, U11 | Attenuators RF Attenuator 1.1dB 1MHz to 3000MHz |  |  |  |  |  |  | Attenuators RF Attenuator 1.1dB 1MHz to 3000MHz |  |  |  |  | 1mm |  |  | IDT | F2255NLGK |  | 972-F2255NLGK | https://www.mouser.com/Search/Refine.aspx?Keyword=972-F2255NLGK
4 | GND-Hole | MOUNT-PAD-ROUND3.0 | 3,0-PAD | H1, H2, H3, H4 | MOUNTING PAD, round |  |  |  |  |  |  |  |  |  |  |  |  |  |  |  |  |  |  |  |  |  |  |  |  |  |  |  | 17
1 | LM2596S | LM2596S | TO263-5 | U6 | SIMPLE SWITCHER® Power Converter 150 kHz 3A Step-Down Voltage Regulator |  |  |  |  |  |  |  |  |  |  |  |  |  |  |  |  | NATIONAL SEMICONDUCTOR |  |  | LM2596S-ADJ/NOPB | 9494367 | 41K3842 |  |  |  |  |  | 12
2 | MA4P7104F | DIODE_DO-221-AA | SODFL5336X110 | D5, D7 | Diode Rectifier - Generic |  | Diode |  |  |  |  |  |  |  |  |  |  |  |  |  |  |  |  |  |  |  |  |  |  |  |  |  |  |  |  |  |  |  |  |  | Rectifier |  |  |  |  | DIODE
2 | MBRS340 | DIODEDO-214AB(SMC) | DIOM7959X625N | D3, D4 | Diode Rectifier - Generic |  | Diode |  |  |  |  |  |  |  |  |  |  |  |  |  |  |  |  |  |  |  |  |  |  |  |  |  |  |  |  |  |  |  |  |  | Rectifier |  |  |  |  | DIODE
1 | MCP4728A0-E | MCP4728A0-E/UNMSOP10_MC_MCH-M | MSOP10_MC_MCH-M | U5 |  | EMA_Jessica |  | Copyright (C) 2018 Accelerated Designs. All rights reserved |  |  |  |  |  |  |  |  |  |  |  |  | MCP4728A0-E/UN |  |  |  |  |  |  |  |  |  |  |  |  |  |  |  |  |  | Microchip_2019-08-23_21 |  |  |  |  |  |  |  | Microchip
1 | MCU_A3 | PINHD-1X2 | 1X02 | JP3 | PIN HEADER |  | CONNECTOR |  |  |  |  |  |  |  |  |  |  |  |  |  |  |  |  |  |  |  |  |  |  |  |  |  |  |  |  |  |  |  |  |  | PIN-HEADER
1 | MCU_A6 | PINHD-1X2 | 1X02 | JP5 | PIN HEADER |  | CONNECTOR |  |  |  |  |  |  |  |  |  |  |  |  |  |  |  |  |  |  |  |  |  |  |  |  |  |  |  |  |  |  |  |  |  | PIN-HEADER
1 | MCU_A7 | PINHD-1X2 | 1X02 | JP7 | PIN HEADER |  | CONNECTOR |  |  |  |  |  |  |  |  |  |  |  |  |  |  |  |  |  |  |  |  |  |  |  |  |  |  |  |  |  |  |  |  |  | PIN-HEADER
2 | MCU_D12 | PINHD-1X2 | 1X02 | JP1, JP8 | PIN HEADER |  | CONNECTOR |  |  |  |  |  |  |  |  |  |  |  |  |  |  |  |  |  |  |  |  |  |  |  |  |  |  |  |  |  |  |  |  |  | PIN-HEADER
1 | MCU_D13 | PINHD-1X2 | 1X02 | JP2 | PIN HEADER |  | CONNECTOR |  |  |  |  |  |  |  |  |  |  |  |  |  |  |  |  |  |  |  |  |  |  |  |  |  |  |  |  |  |  |  |  |  | PIN-HEADER
1 | MCU_D6 | PINHD-1X2 | 1X02 | JP4 | PIN HEADER |  | CONNECTOR |  |  |  |  |  |  |  |  |  |  |  |  |  |  |  |  |  |  |  |  |  |  |  |  |  |  |  |  |  |  |  |  |  | PIN-HEADER
1 | MCU_I2C | PINHD-1X3 | 1X03 | JP6 | PIN HEADER |  | CONNECTOR |  |  |  |  |  |  |  |  |  |  |  |  |  |  |  |  |  |  |  |  |  |  |  |  |  |  |  |  |  |  |  |  |  | PIN-HEADER
1 | MMBT3904 | MMBT3904LT1-NPN-SOT23-BEC | SOT23-BEC | T1 | NPN Transistror |  |  |  |  |  |  |  |  |  |  |  |  |  |  |  |  |  |  |  |  |  |  |  |  |  |  |  | 0
1 | MMBT3906 | MMBT3906LT1SMD | SOT23-BEC | T2 | PNP Transistror |  |  |  |  |  |  |  |  |  |  |  |  |  |  |  |  |  |  |  |  |  |  |  |  |  |  |  | 6
3 | NFL21SP106 | NFL21SP106 | NFM21C | U7, U8, U9
1 | PGA-103+ | PGA-103+ | SOT89 | U1
1 | RA60H1317M1A | RA60H1317M1A | RA60H1317M1A | U2
1 | RFC | T50-6 | T50-6SMD | L2
1 | TCCH-80+ | TCCH-80+ | TCCH-80 | L5
1 | TPS7A4501DCQT | TPS7A4501DCQT | DCQ6 | U4 |  |  |  |  |  |  | http://www.ti.com/lit/gpn/TPS7A4533 | Low-Noise Fast-Transient-Response 1.5-A LDO Regulator |  | SINGLE CHANNEL LDO |  | TPS7A4533 |  | SOT-223 | Texas Instruments |  | TPS7A4501DCQT |  |  |  |  |  |  |  |  | DCQ |  | 6 |  |  |  |  |  |  |  |  |  |  |  |  |  |  | Texas Instruments
5 | TPSTP10SQ | TPSTP10SQ | TP10SQ | TP1, TP2, TP3, TP4, TP5 | TEST PIN |  |  |  |  |  |  |  |  |  |  |  |  |  |  |  |  |  |  |  |  |  |  |  |  |  |  |  | 0
1 | TX-IN, RX-OUT | SMA-142-0711-821/826 | J502-ND-142-0711-821/826 | X1 | SMA 50 Ohm End Launch Jack Receptacle - Round Contact |  |  |  |  |  |  |  |  |  |  |  |  |  |  |  |  | JOHNSON COMPONENTS |  |  | 142-0711-821 | 1019328 | 16F3627 |  |  |  |  |  | 0

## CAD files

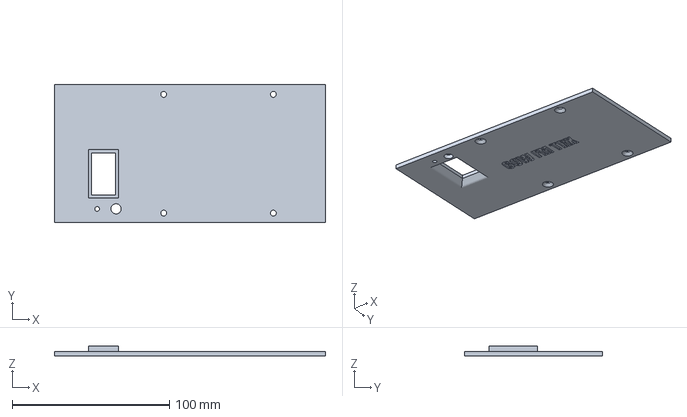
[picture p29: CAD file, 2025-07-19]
60W FM PA RA60H1317M1A/Enclosure/60W-FM-PA_Lid/60W-FM-PA_Lid.3mf
172.5 x 88.0 x 6.50 mm

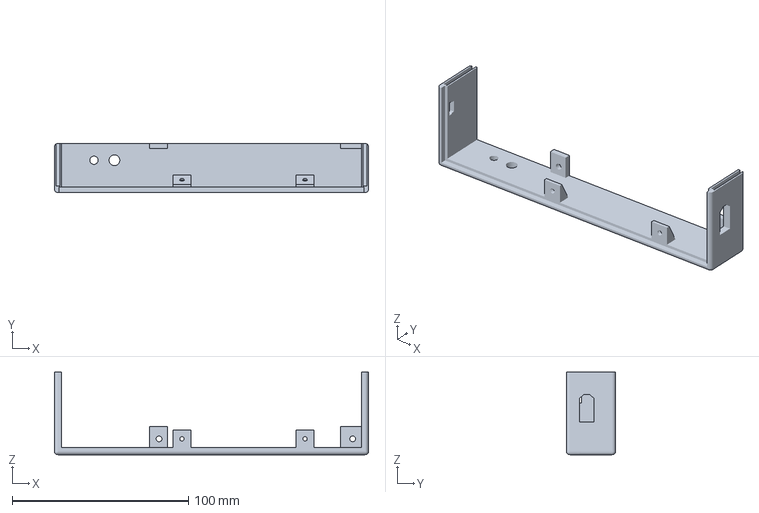
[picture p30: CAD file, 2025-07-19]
60W FM PA RA60H1317M1A/Enclosure/60W-FM-PA_Side1/60W-FM-PA_Side1.3mf
178.1 x 28.0 x 46.8 mm

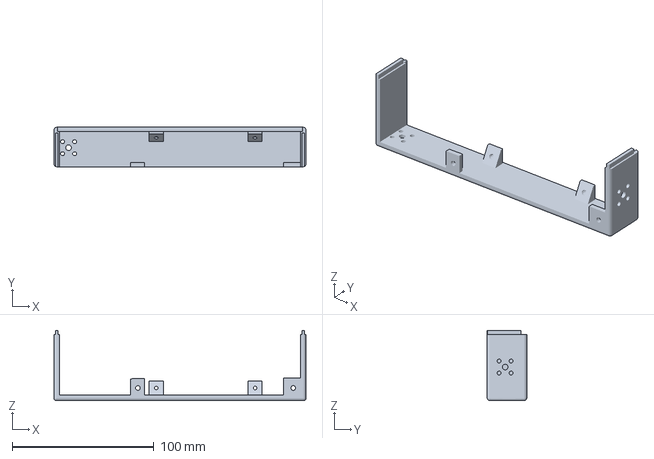
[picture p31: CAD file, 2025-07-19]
60W FM PA RA60H1317M1A/Enclosure/60W-FM-PA_Side2/60W-FM-PA_Side2.3mf
178.1 x 28.0 x 49.8 mm

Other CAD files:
60W FM PA RA60H1317M1A/Enclosure/60W-FM-PA_Lid/60W-FM-PA_Lid.stl
60W FM PA RA60H1317M1A/Enclosure/60W-FM-PA_Side1/60W-FM-PA_Side1.stl
60W FM PA RA60H1317M1A/Enclosure/60W-FM-PA_Side2/60W-FM-PA_Side2.stl

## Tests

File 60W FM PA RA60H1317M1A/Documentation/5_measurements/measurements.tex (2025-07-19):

\section{TX-Path Transfer Function}
ToDo Text (Variable Gain with Vdd of RA60, XY V for every gain)

\subsection{TF of RA60H1317M1A}
	\begin{figure}[ht!]
		\centering
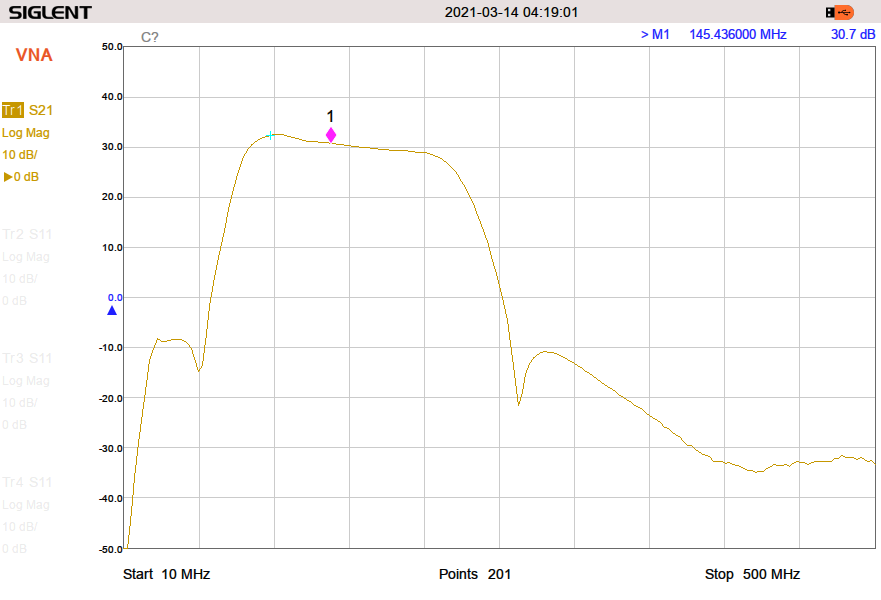
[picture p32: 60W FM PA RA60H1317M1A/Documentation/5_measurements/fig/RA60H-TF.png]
		
		\caption{Transfer Function of RA60H1317M1A}
		\label{fig:ra60h1317m1a TF}
	\end{figure}
	\newpage

\subsection{10dB Gain}
\begin{figure}[ht!]
	\centering
	
	\caption{TX-Path Transfer Function with 10dB gain}
	\label{fig:10dB Gain}
\end{figure}

\subsection{30dB Gain}
	\begin{figure}[ht!]
		\centering
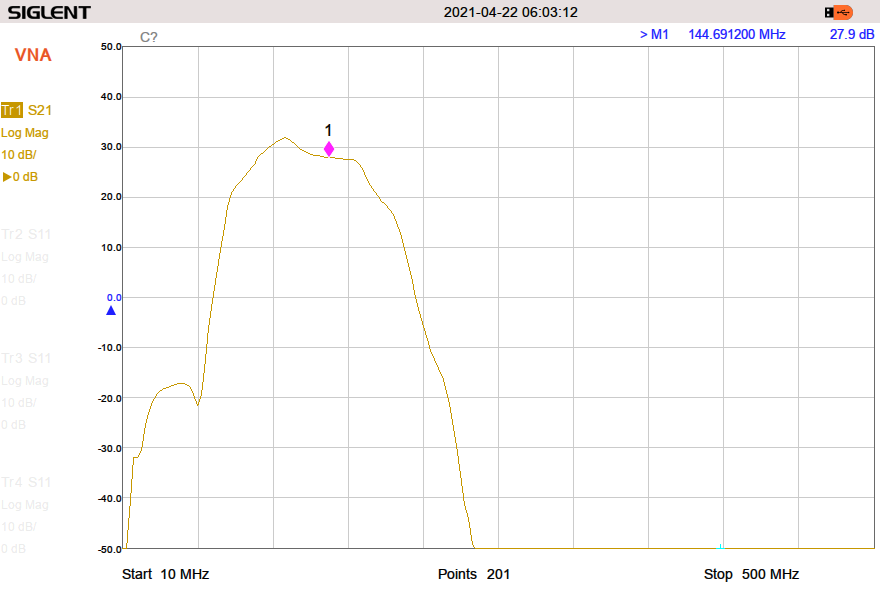
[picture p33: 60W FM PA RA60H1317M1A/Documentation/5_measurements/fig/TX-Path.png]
		
		\caption{TX-Path Transfer Function with 30dB gain}
		\label{fig:30dB Gain}
	\end{figure}
	\newpage
	
\section{RX-Path Transfer Function}
ToDo Text (Variable Attenuation with F2255)

\subsection{F2255NLGK Attenuation Diagram}
ToDo Text (What is a F2255)

	\begin{figure}[ht!]
		\centering
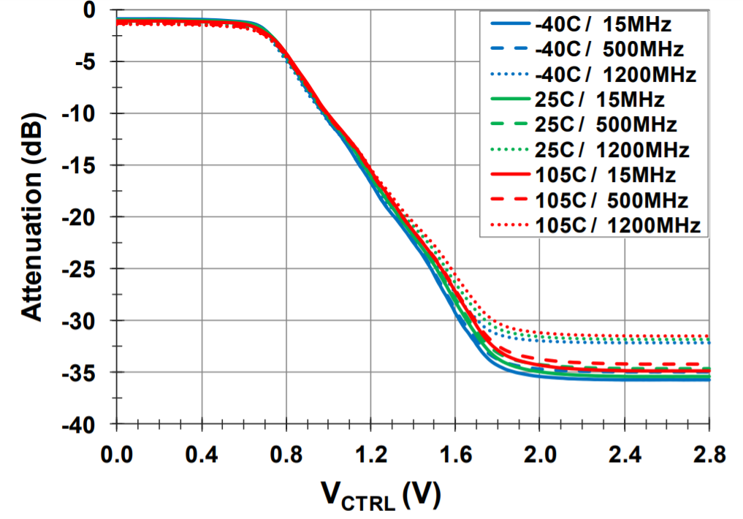
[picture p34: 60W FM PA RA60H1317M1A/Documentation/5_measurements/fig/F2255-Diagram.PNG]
		
		\caption{F2255NLGK Attenuation Diagram\protect\footnotemark \cite{f2255nlgk.2020}}
		\label{fig:F2255NLGK Att}
	\end{figure}

	\footnotetext{\url{https://www.mouser.at/datasheet/2/698/IDT_F2255_Datasheet_DST_20180209-1997542.pdf}}
	\newpage

\subsection{No Attenuation}
	\begin{figure}[ht!]
		\centering
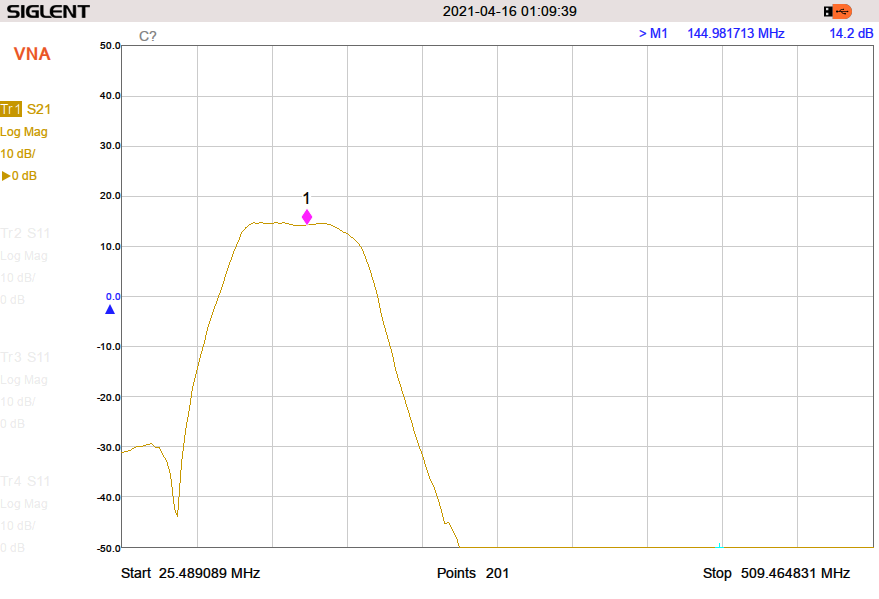
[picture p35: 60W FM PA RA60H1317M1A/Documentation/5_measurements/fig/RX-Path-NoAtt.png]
		
		\caption{RX-Path Transfer Function without attenuation}
		\label{fig:No Att}
	\end{figure}

\subsection{20dB Attenuation}
	\begin{figure}[ht!]
		\centering
		
		\caption{RX-Path Transfer Function with 20dB attenuation}
		\label{fig:20dB Att}
	\end{figure}
	\newpage
	
\section{Output Power}
For all output power measurements an input power of XYdBm (xyW) is used.
Furthermore, at the input of the Vector Network Analyzer a 23dBm attenuator is mounted to handle the power.
So, the final output Power consists of the measured power and the 23dBm.\\
For exmaple, if the spectrum analyser shows an output power of XYdBm the output power equals $XY+23dBm = dBm (XYW)$.

\subsection{20W Output Power} 
	\begin{figure}[ht!]
		\centering
		
		\caption{20W Output Power}
		\label{fig:20W OUT}
	\end{figure}
	\newpage

\subsection{40W Output Power}
	\begin{figure}[ht!]
		\centering
		
		\caption{40W Output Power}
		\label{fig:40W OUT}
	\end{figure}

\subsection{60W Output Power}
	\begin{figure}[ht!]
		\centering
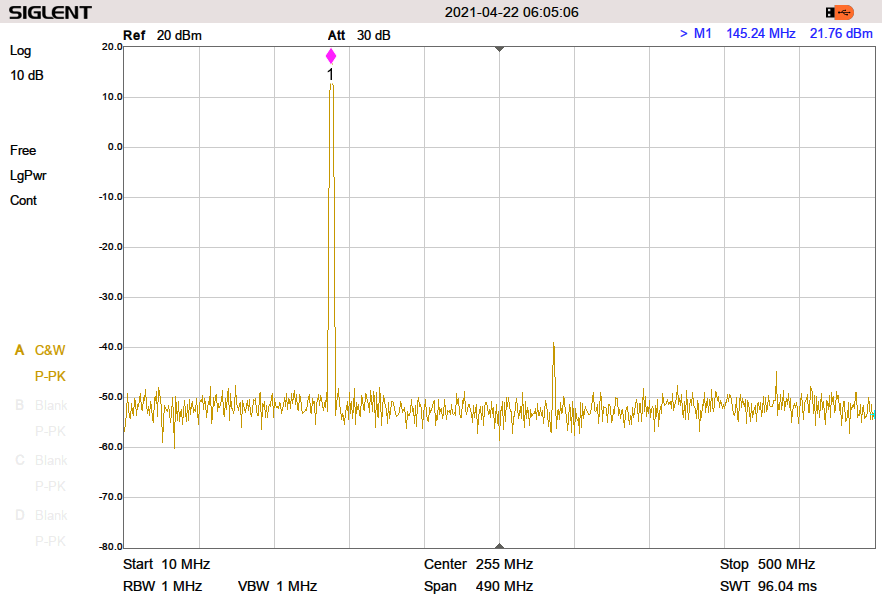
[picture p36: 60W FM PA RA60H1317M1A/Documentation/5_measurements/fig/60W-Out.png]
		
		\caption{60W Output Power}
		\label{fig:60W OUT}
	\end{figure}

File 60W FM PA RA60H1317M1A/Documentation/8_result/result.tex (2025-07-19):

\section{Assembled PCB}
	ToDo Text
	\begin{figure}[h]
		\centering
		
		\caption{Assembled PCB}
		\label{fig:Assembled PCB}
	\end{figure}
	\newpage

\section{Transceiver with Power Amplifier}
	ToDo Text
	\begin{figure}[h]
		\centering
		
		\caption{DRA818V Transceiver with Power Amplifier}
		\label{fig:TRX+PA}
	\end{figure}
	%\newpage
	
\section{Implemented in Enclosure}
Unfortunately, the 3D enclosure is not finished yet.

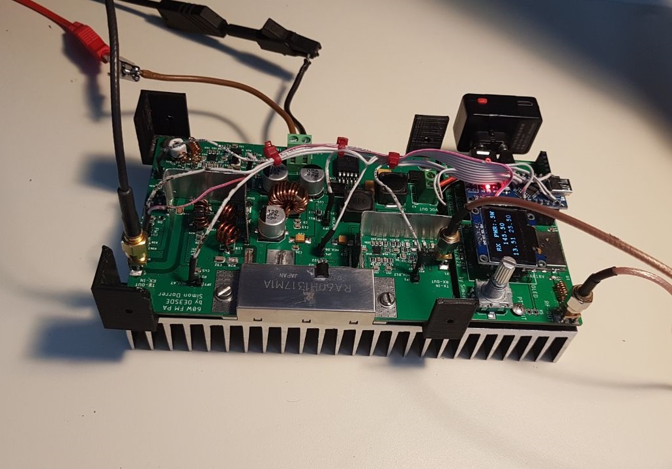
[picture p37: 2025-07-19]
60W FM PA RA60H1317M1A/Documentation/8_result/fig/PA_1.jpg

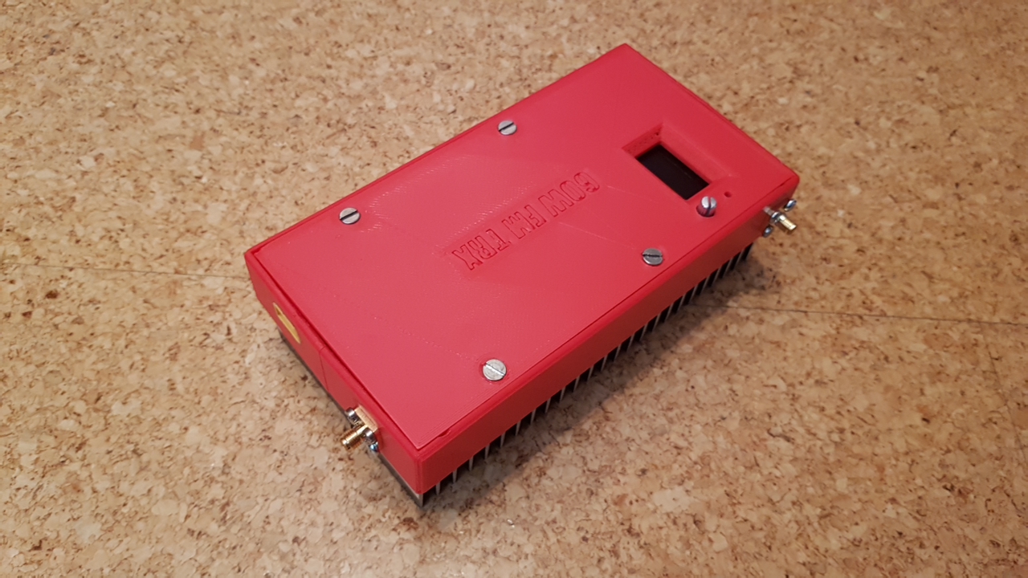
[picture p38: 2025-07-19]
60W FM PA RA60H1317M1A/Documentation/8_result/fig/result_3.jpg

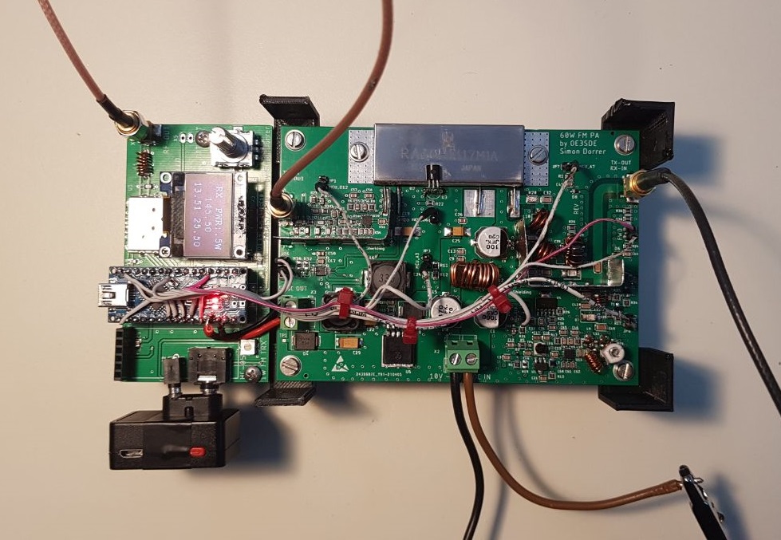
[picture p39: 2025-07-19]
60W FM PA RA60H1317M1A/Documentation/8_result/fig/PA_3.jpg

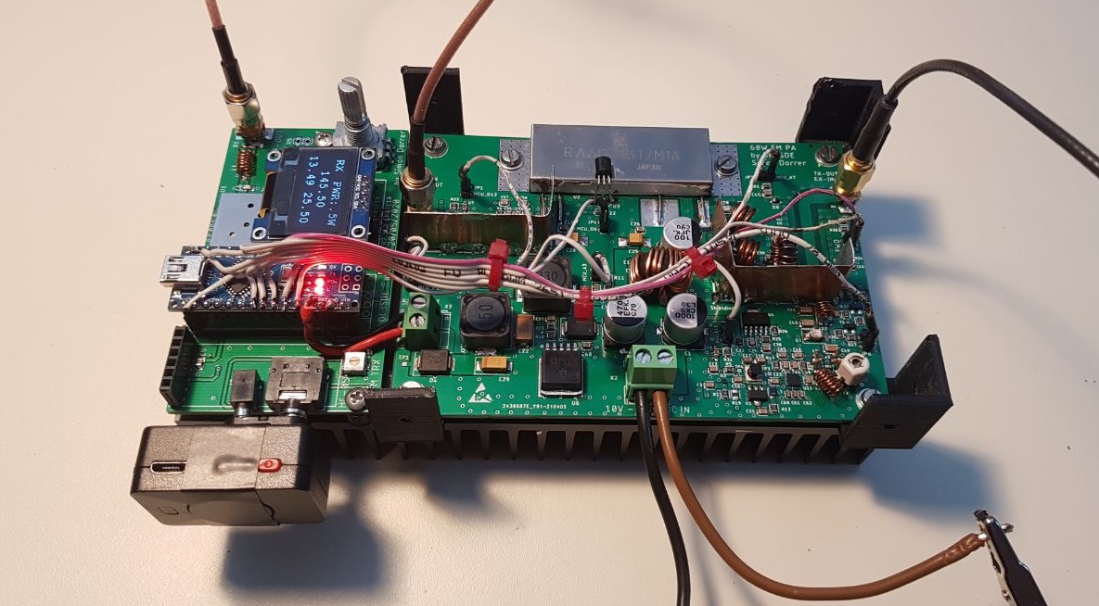
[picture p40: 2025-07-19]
60W FM PA RA60H1317M1A/Documentation/8_result/fig/PA_2.jpg

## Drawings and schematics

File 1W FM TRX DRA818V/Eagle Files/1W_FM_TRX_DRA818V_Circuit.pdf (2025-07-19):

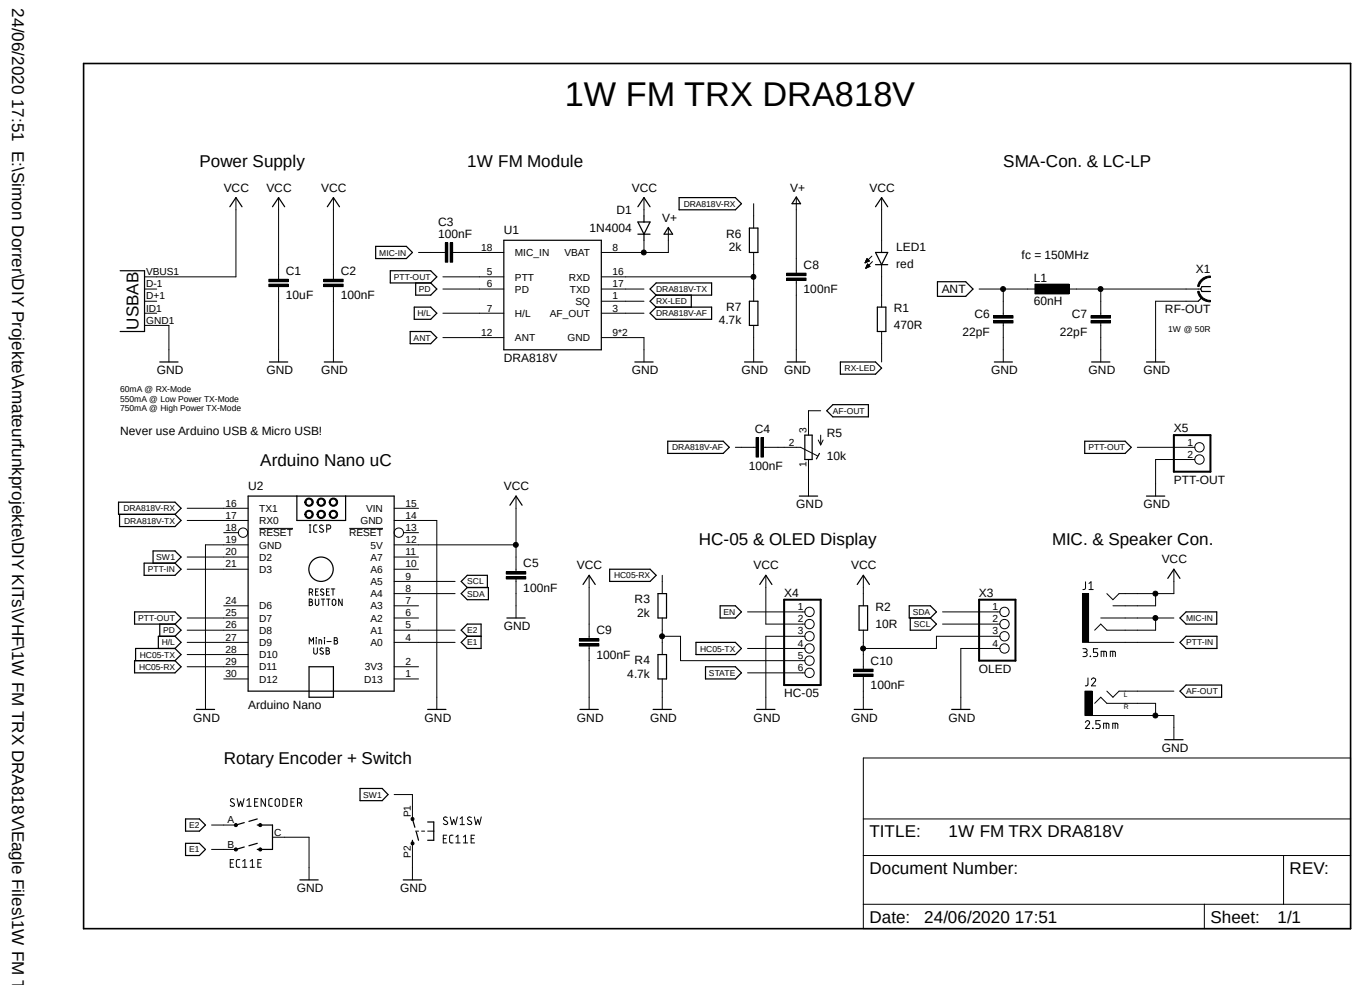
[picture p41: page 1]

24/06/2020 17:51 E:\Simon Dorrer\DIY Projekte\Amateurfunkprojekte\DIY KITs\VHF\1W FM TRX DRA818V\Eagle Files\1W FM TRX DRA818V.sch (Sheet: 1/1) 1W FM TRX DRA818V 60mA @ RX-Mode 550mA @ Low Power TX-Mode 750mA @ High Power TX-Mode 1W @ 50R 1W FM Module Arduino Nano uC Power Supply SMA-Con. & LC-LP HC-05 & OLED Display MIC. & Speaker Con. Rotary Encoder + Switch fc = 150MHz Never use Arduino USB & Micro USB! DRA818V RF-OUT 470R 10uF 100nF red GND GND GND GND GND GND 100nF 100nF 1N4004 100nF GND OLED GND VCC VCC VCC VCC VCC VCC HC-05 VCC GND 2k 4.7kGND 10k GND GND GND PTT-OUT GND 60nH 22pF 22pF 100nF GND GND GND GND 100nF 100nF VCC GND GND VCC VCC GND 10R Arduino Nano 2k 4.7kGND V+ V+ SQ

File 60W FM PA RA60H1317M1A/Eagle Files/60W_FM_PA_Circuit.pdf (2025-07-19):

SpiceOrder 2 | SpiceOrder 1 SpiceOrder 1 | SpiceOrder 2 GNDed Holes | RX-Amp. | RX LC-BP Filter n = 3 Type = Chebyshev fcu = 172MHz fcl = 120MHz LC-LP Filter IN | 60W FM PA 12VDC Supply + Filtering | 5VDC for Arduino + DRA818V n = 7 Type = Chebyshev fc = 155MHz | Measure VCC with Arduino ¹⁰VDC to max. 13.8VDC | 5VDC for PGA-103+ | Create VGG & measure it with Arduino PIN-Diode RX-Switch | TX-RX Switch OUT n = 5 Type = Chebyshev fc = 182MHz LC-LP Filter OUT Digital Attenuator -3dB Attenuator for max. 50W TX-OUT (-6dB + (-18dB)) PIN-Diode TX-Switch ⁵⁰R | TX-OUT RX-IN 0.5W or 1W: Second SMA Con. on Case Thermal Protection | SWR Protection by OE3SDE Simon Dorrer Directional coupler (PA --> ANT) MCU / DRA818V | Directional coupler (PA --> ANT) | REV FWD VOUTC unused MCU_A2 unused! | Digital Attenuator | HIGH (TX) LOW (RX) R23, R31 & R40 are for a defined voltage level at start-up of MCU! | >1mm dia. wire Alternative: L1 = L4 = 47nH, L3 = 68nH;

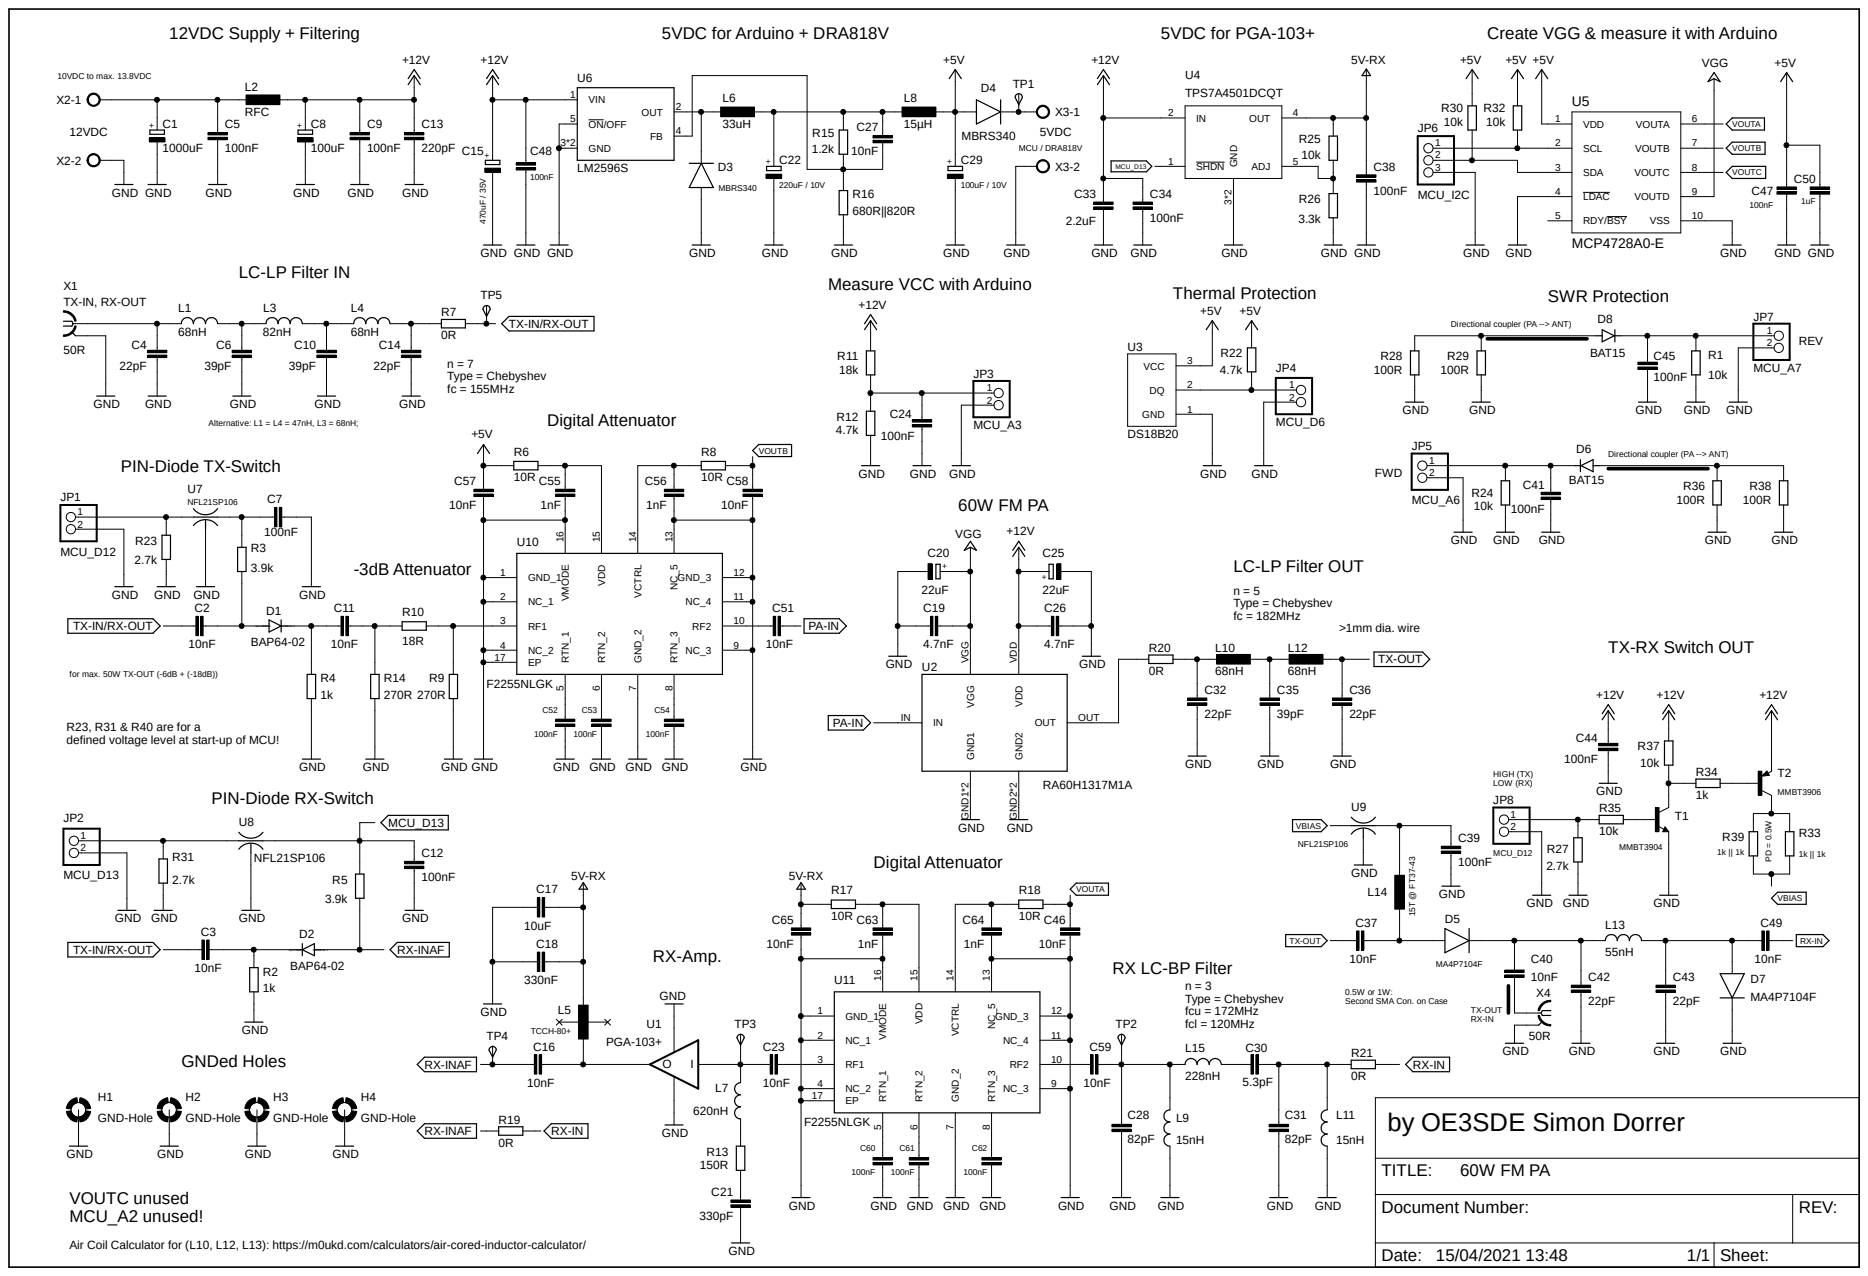
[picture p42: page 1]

PD = 0.5W Air Coil Calculator for (L10, L12, L13): https://m0ukd.com/calculators/air-cored-inductor-calculator/ PGA-103+ GND-Hole TX-IN, RX-OUT 50R GND GND GND GND 150R 10nF 330pF 10nF 10uF 330nF GND 22pF 39pF 68nH GND GND 82nH39pFGND TCCH-80+ 620nHGND 22uF 22uF 4.7nF 4.7nF GND GND GND GND 12VDC 100nF GND +12V 100uF 100nF 220pF GND +12V 10nF GND MCU_A3 18k 4.7kGND GND +12V GND GND 5VDC GND +12V 100nF 5V-RX GND 0R 0R 0R RFC GND GND GND GND 22pF 39pF 22pF 68nH 68nH GND GND GND 82pF 15nH 15nH 82pF GND GND GND GND 5V-RX 0R 68nH22pFGND 5.3pF 100nFGND VGG BAP64-02 NFL21SP106 100nF 3.9k 1k 10nF MCU_D13 GND GND GND GND BAP64-02 10nF NFL21SP106 100nF 3.9k 1k 10nF MCU_D12 GND GND GND GND 10k 10k GND 100nFGND GND 1uFGND VGG 10k 10k +5V +5V MCU_I2C GND GND 100nFGND MCU_D6 MCU_A6 MCU_A7 680R||820R 1.2k GND GND 100R BAT15 100nF GND GND GND 100RGND MA4P7104F NFL21SP106 100nF 10nF GND GND GND TPS7A4501DCQT 10k 2.2uF 3.3k GND 100nF GND LM2596S 33uH 220uF / 10V

470uF / 35V100uF / 10V GND GND GND GND GND +12V +5V 100R BAT15 100nFGND GND 100R GND GND 15µH 4.7k+5V GND +5V DS18B20 MCP4728A0-E F2255NLGK +5V +5V 10nF GND GND GND 100nF 100nF 100nF GND GND GND +5V 10R 1nF 1nF 10R 10nF 10nF 270R 18R 270R F2255NLGK 10nF GND GND GND 100nF 100nF 100nF GND GND GND 10R 1nF 1nF 10R 10nF 10nF 5V-RX GND GND 2.7k 2.7k 2.7kGND GND GND GND 100nF GND 1000uF GND-Hole GND-Hole GND-Hole MA4P7104F GND +12V +12V 1k MMBT3906 MMBT3904 +12V 1k || 1k 1k || 1k 15T @ FT37-43 10nF 22pF 22pF GND GND GND 228nH 10nF MCU_D12GND 10kGND 10k GND 55nH U1

GND1 GND1*2 IN IN OUT OUT VGG

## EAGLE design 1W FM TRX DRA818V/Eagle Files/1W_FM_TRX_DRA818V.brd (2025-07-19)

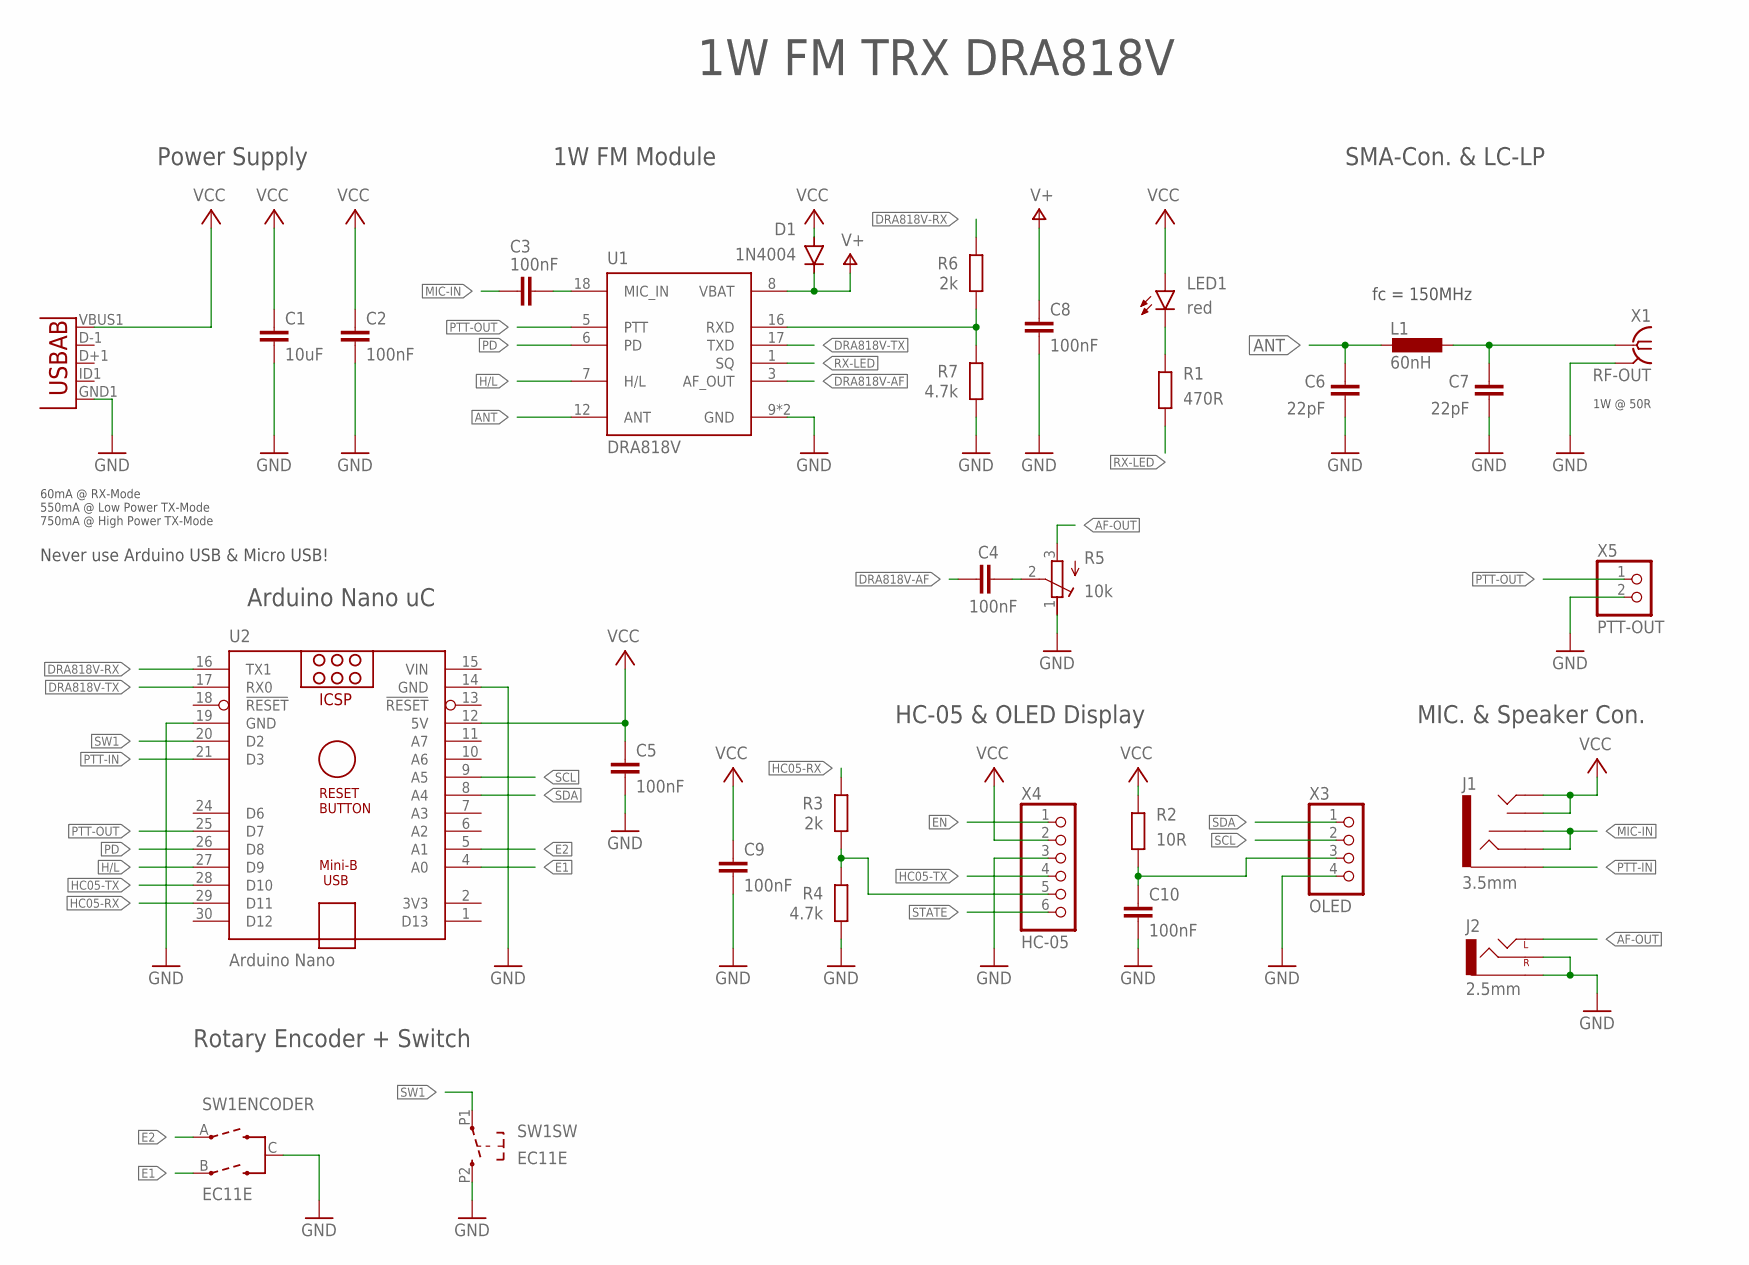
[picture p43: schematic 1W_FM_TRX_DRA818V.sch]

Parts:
C1: 10uF; C0805K
C2, C3, C4, C5, C8, C9, C10: 100nF; C0805K
C6, C7: 22pF; C0805K
D1: 1N4004; DO41-10
J1: 3.5mm; AUDIO-JACK
J2: 2.5mm; STEREOJACK2.5MM_STEREOJACK2.5MM
L1: 60nH; L8530M
LED1: red; CHIP-LED0805
R1: 470R; R0805
R2: 10R; R0805
R3, R6: 2k; R0805
R4, R7: 4.7k; R0805
R5: 10k; RTRIM3314J
SW1: EC11E; EC11E_INCREMENTAL_ENCODER
U1: DRA818V; DORJI_DRA818V
U2: Arduino Nano; ARDUINO_NANO
U3: USB Micro; USB-MICRO-SMD
X1: RF-OUT; J502-ND-142-0711-821/826
X3: OLED; 1X04
X4: HC-05; 1X06
X5: PTT-OUT; 1X02

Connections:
AF-OUT: J2.SHIELD (LEFT), R5.3 (A)
ANT: C6.2, L1.2, U1.12 (ANT)
DRA818V-AF: C4.1, U1.3 (AF_OUT)
DRA818V-RX: R6.2, U2.16 (TX1)
DRA818V-TX: U1.17 (TXD), U2.17 (RX0)
E1: SW1.B, U2.4 (A0)
E2: SW1.A, U2.5 (A1)
EN: X4.1
GND: C1.2, C2.2, C5.2, C6.1, C7.1, C8.1, C9.2, C10.2, J2.RING1 (SLEEVE), J2.TIP (RIGHT), R4.1, R5.1 (E), R7.1, SW1.C, SW1.P2 (2), U1.9 (GND), U1.10 (GND), U2.14 (GND), U2.19 (GND), U3.GND1 (GND), X1.G@1 (GND), X1.G@2 (GND), X1.G@3 (GND), X1.G@4 (GND), X3.4, X4.3, X5.2
H/L: U1.7 (H/L), U2.27 (D9)
HC05-RX: R3.2, U2.29 (D11)
HC05-TX: U2.28 (D10), X4.4
MIC-IN: C3.1, J1.RING, J1.RSH
unnamed: C3.2, U1.18 (MIC_IN)
unnamed: R3.1, R4.2, X4.5
unnamed: LED1.C, R1.2
unnamed: C4.2, R5.2 (S)
unnamed: C7.2, L1.1, X1.1 (RF)
unnamed: C10.1, R2.1, X3.3
unnamed: R6.1, R7.2, U1.16 (RXD)
PD: U1.6 (PD), U2.26 (D8)
PTT-IN: J1.SLEEVE, U2.21 (D3)
PTT-OUT: U1.5 (PTT), U2.25 (D7), X5.1
RX-LED: R1.1, U1.1 (SQ)
SCL: U2.9 (A5), X3.2
SDA: U2.8 (A4), X3.1
STATE: X4.6
SW1: SW1.P1 (1), U2.20 (D2)
V+: C8.2, D1.C, U1.8 (VBAT)
VCC: C1.1, C2.1, C5.1, C9.1, D1.A, J1.TIP, J1.TSH, LED1.A, R2.2, U2.12 (5V), U3.VBUS1 (VBUS), X4.2
VIN: U2.15 (VIN)

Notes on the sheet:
1W FM TRX DRA818V
60mA @ RX-Mode 550mA @ Low Power TX-Mode 750mA @ High Power TX-Mode
1W @ 50R
1W FM Module
Arduino Nano uC
Power Supply
SMA-Con. & LC-LP
HC-05 & OLED Display
MIC. & Speaker Con.
Rotary Encoder + Switch
fc = 150MHz
Never use Arduino USB & Micro USB!

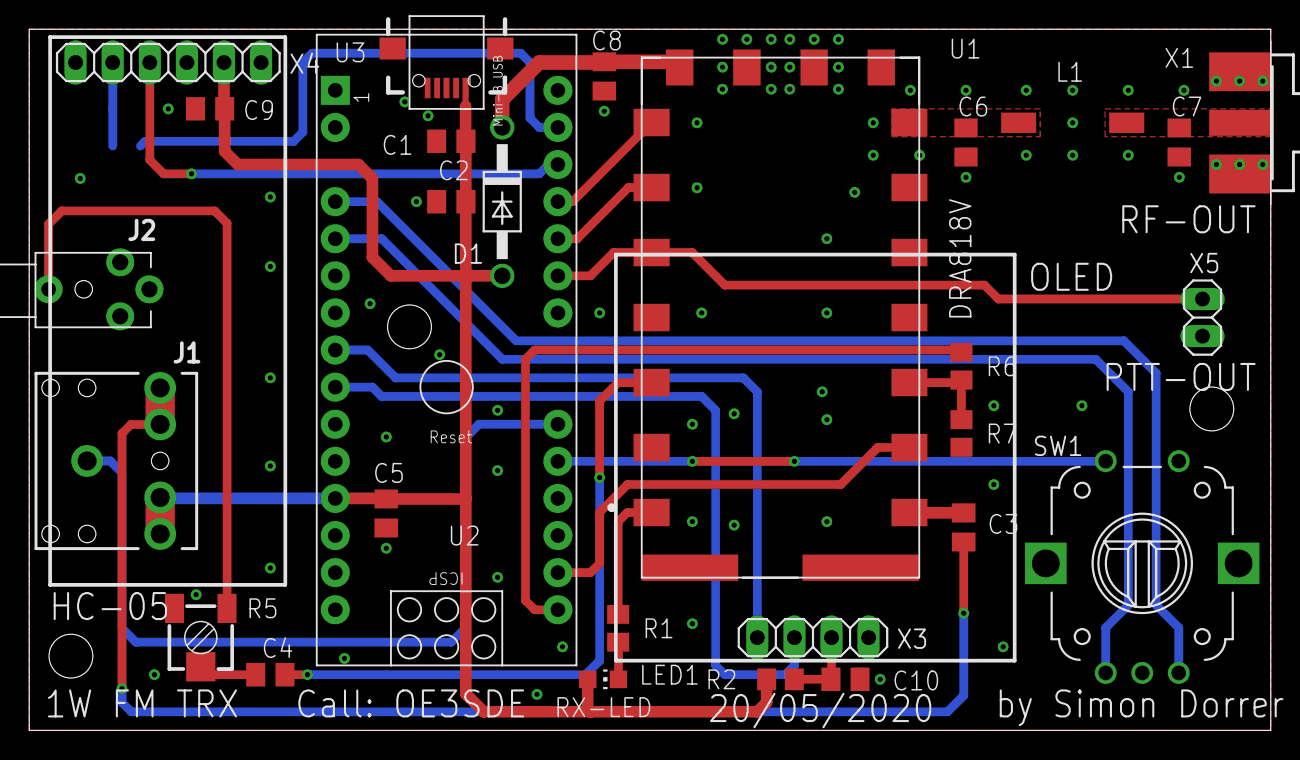
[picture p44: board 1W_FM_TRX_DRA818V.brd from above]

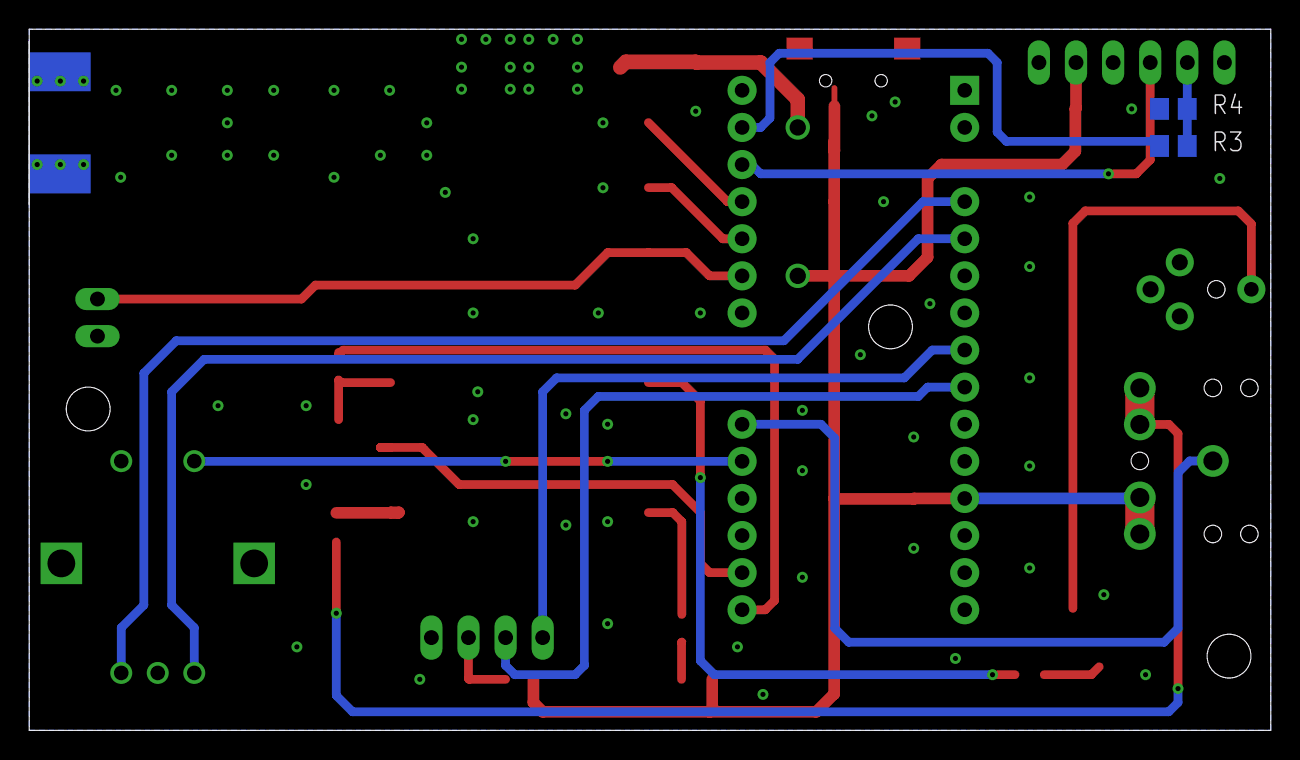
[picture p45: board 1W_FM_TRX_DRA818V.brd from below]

Board: 2 copper layers, 85.0 x 48.0 mm, 30 parts (2 on the bottom side), 28 nets.

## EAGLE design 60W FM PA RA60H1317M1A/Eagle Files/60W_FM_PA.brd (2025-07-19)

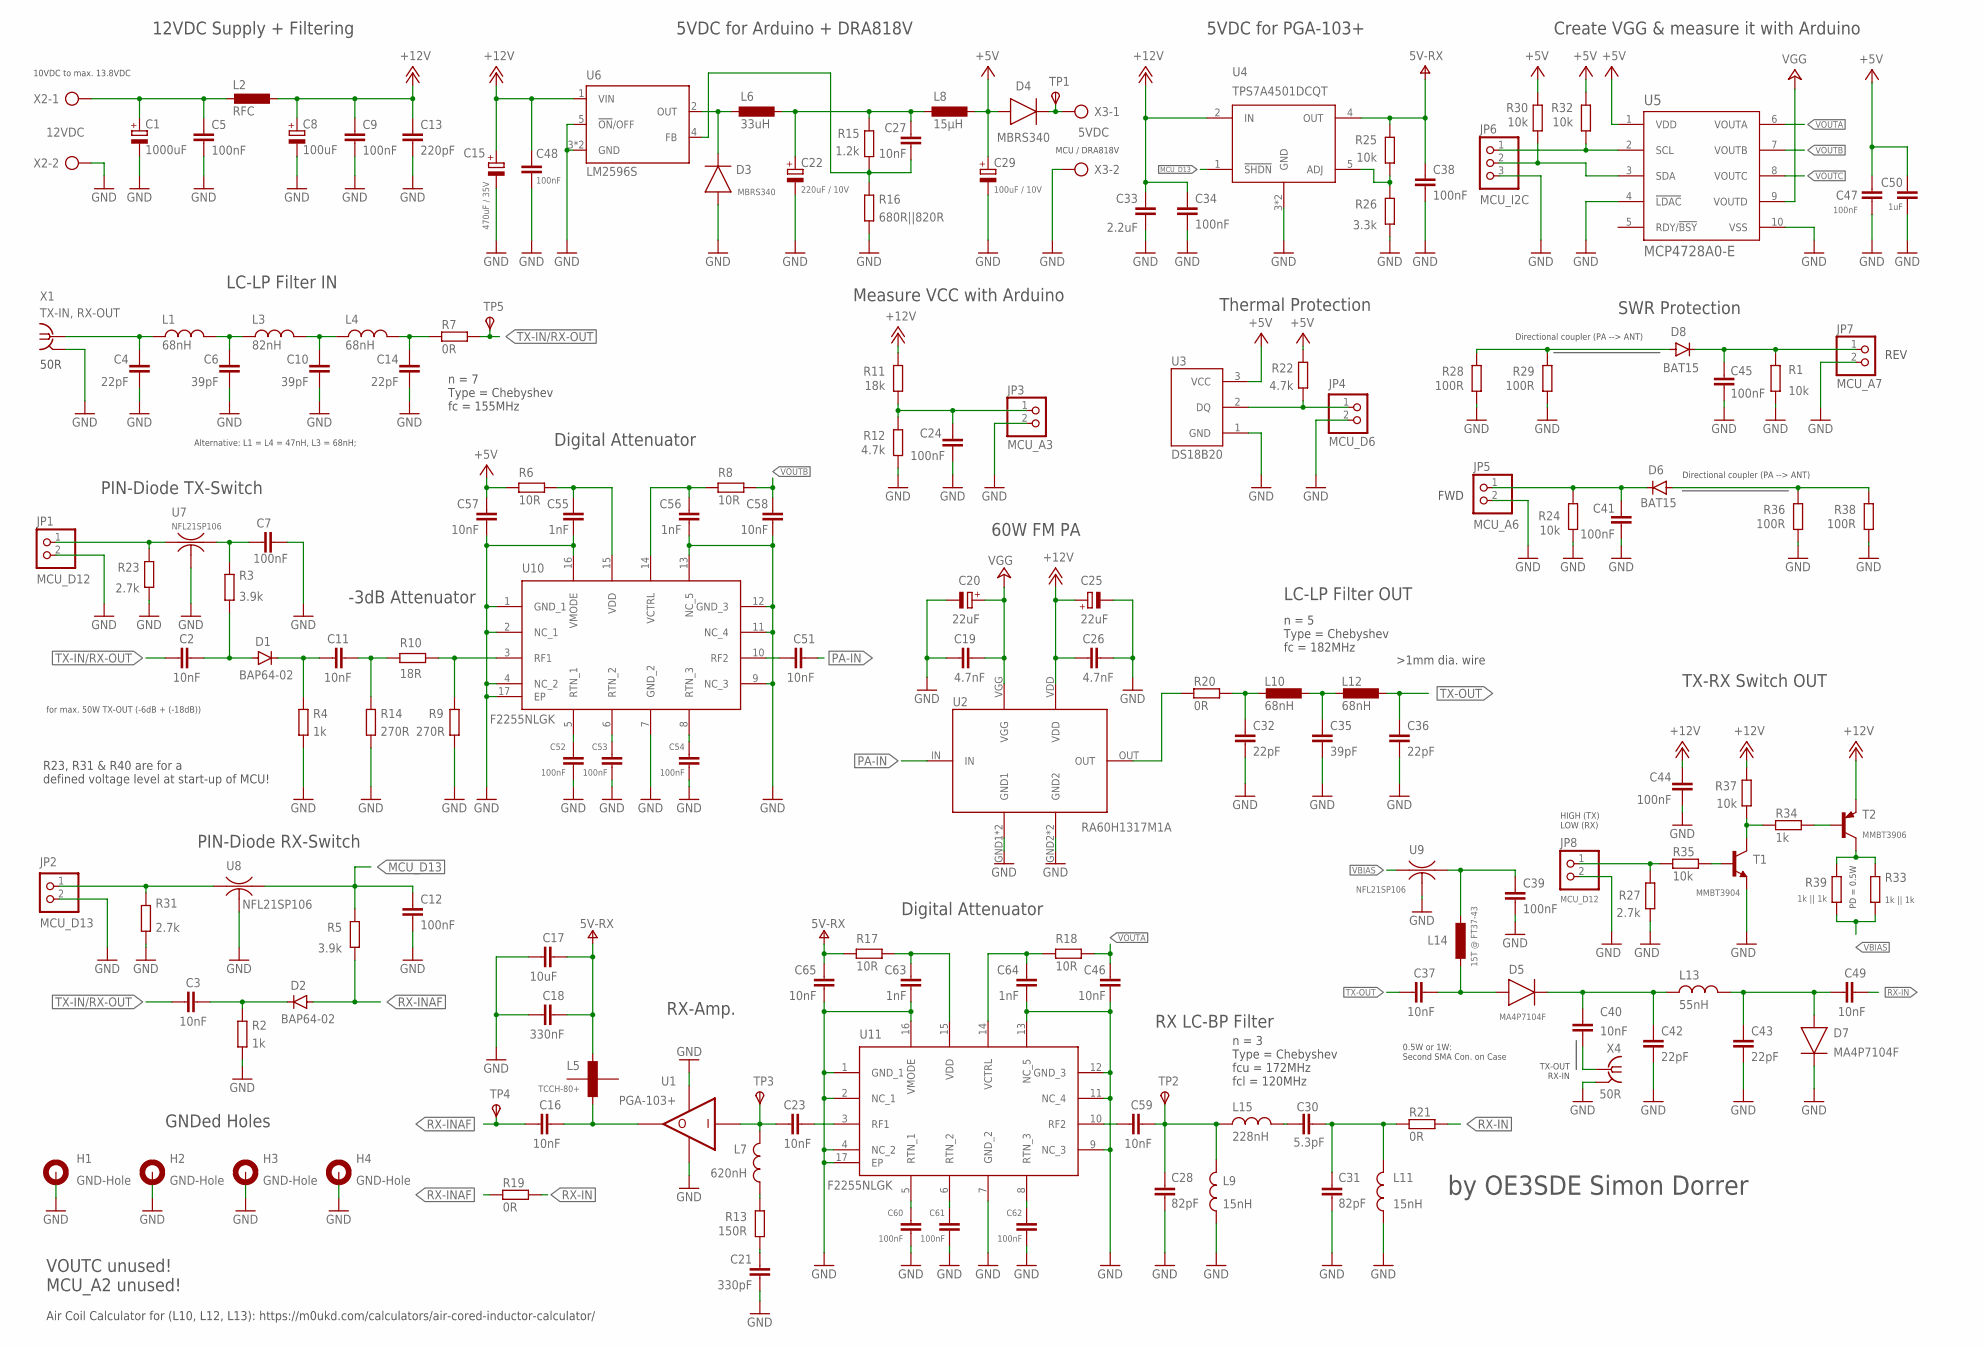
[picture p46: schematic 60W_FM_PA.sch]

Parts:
C1: 1000uF; CAPAE1030X1050N
C2, C3, C11, C16, C23, C27, C46, C51, C57, C58, C59, C65: 10nF; CAPC2012X110
C4, C14: 22pF; CAPC2012X110
C5, C7, C9, C12, C24, C34, C38, C39, C41, C44, C45, C47, C48: 100nF; CAPC2012X110
C6, C10: 39pF; CAPC2012X110
C8: 100uF; CAPAE1030X1050N
C13: 220pF; CAPC2012X110
C15: 470uF / 35V; CAPAE1030X1050N
C17: 10uF; CAPC2012X110
C18: 330nF; CAPC2012X110
C19, C26: 4.7nF; CAPC2012X110
C20, C25: 22uF; SMC_D
C21: 330pF; CAPC2012X110
C22: 220uF / 10V; CAPMP7343X310N
C28, C31: 82pF; CAPC2012X110
C29: 100uF / 10V; CAPMP7343X310N
C30: 5.3pF; CAPC2012X110
C32, C36, C42, C43: 22pF; CAPC3216X135
C33: 2.2uF; CAPC2012X110
C35: 39pF; CAPC3216X135
C37, C40, C49: 10nF; CAPC3216X135
C50: 1uF; CAPC2012X110
C52, C53, C54, C60, C61, C62: 100nF; CAPC1608X85
C55, C56, C63, C64: 1nF; CAPC2012X110
D1, D2: BAP64-02; SOD523
D3, D4: MBRS340; DIOM7959X625N
D5, D7: MA4P7104F; SODFL5336X110
D6, D8: BAT15; SOD-323
H1, H2, H3, H4: GND-Hole; 3,0-PAD
JP1, JP8: MCU_D12; 1X02
JP2: MCU_D13; 1X02
JP3: MCU_A3; 1X02
JP4: MCU_D6; 1X02
JP5: MCU_A6; 1X02
JP6: MCU_I2C; 1X03
JP7: MCU_A7; 1X02
L1, L4: 68nH; INDC2009X120
L2: RFC; T50-6SMD
L3: 82nH; INDC2009X120
L5: TCCH-80+; TCCH-80
L6: 33uH; 1260
L7: 620nH; INDC2009X120
L8: 15µH; 1260
L9, L11: 15nH; INDC3216X190
L10, L12: 68nH; AIR-COIL-SMD
L13: 55nH; INDC3216X190
L14: 15T @ FT37-43; AIR-COIL-SMD
L15: 228nH; INDC3216X190
R1, R24, R25, R30, R32, R35, R37: 10k; RESC2012X65
R2, R4, R34: 1k; RESC2012X65
R3, R5: 3.9k; RESC2012X65
R6, R8, R17, R18: 10R; RESC2012X65
R7, R19, R21: 0R; RESC2012X65
R9, R14: 270R; RESC2012X65
R10: 18R; RESC2012X65
R11: 18k; RESC2012X65
R12, R22: 4.7k; RESC2012X65
R13: 150R; RESC2012X65
R15: 1.2k; RESC2012X65
R16: 680R||820R; RESC2012X65
R20: 0R; RESC3216X70
R23, R27, R31: 2.7k; RESC2012X65
R26: 3.3k; RESC2012X65
R28, R29, R36, R38: 100R; RESC2012X65
R33, R39: 1k || 1k; RESC2012X65
T1: MMBT3904; SOT23-BEC
T2: MMBT3906; SOT23-BEC
TP1, TP2, TP3, TP4, TP5: TPSTP10SQ; TP10SQ
U1: PGA-103+; SOT89
U2: RA60H1317M1A
U3: DS18B20; 21-0248A_MXM
U4: TPS7A4501DCQT; DCQ6
U5: MCP4728A0-E; MSOP10_MC_MCH-M
U6: LM2596S; TO263-5
U7, U8, U9: NFL21SP106; NFM21C
U10, U11: F2255NLGK; QFN50P300X300X100-17N
X1: TX-IN, RX-OUT; J502-ND-142-0711-821/826
X2: 12VDC; AK300/2
X3: 5VDC; AK300/2
X4: 50R; J502-ND-142-0711-821/826

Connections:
+5V: C29.1 (+), C47.2, C50.2, C57.1, D4.2 (A), L8.- (2), R6.1, R22.2, R30.1, R32.1, U3.3 (VCC), U5.1 (VDD)
+12V: C8.1 (+), C9.2, C13.2, C15.1 (+), C25.+, C26.1, C33.2, C34.2, C44.2, C48.2, L2.P$2 (2), R11.2, R37.1, T2.E, U2.VDD, U4.2 (IN), U6.1 (VIN)
+24V: C19.2, C20.+, U2.VGG, U5.9 (VOUTD)
D12: JP1.1, R23.1, U7.1
GND: C1.2 (-), C4.2, C5.1, C6.2, C7.1, C8.2 (-), C9.1, C10.2, C12.1, C13.1, C14.2, C15.2 (-), C17.2, C18.2, C19.1, C20.-, C21.1, C22.2 (-), C24.1, C25.-, C26.2, C28.2, C29.2 (-), C31.2, C32.2, C33.1, C34.1, C35.2, C36.2, C38.1, C39.1, C41.2, C42.2, C43.2, C44.1, C45.2, C46.2, C47.1, C48.1, C50.1, C52.2, C53.2, C54.2, C55.2, C56.2, C57.2, C58.2, C60.2, C61.2, C62.2, C63.2, C64.2, C65.2, D3.2 (A), D7.1 (C), H1.B3,0, H2.B3,0, H3.B3,0, H4.B3,0, JP1.2, JP2.2, JP3.2, JP4.2, JP5.2, JP6.3, JP7.2, JP8.2, L9.1, L11.1, R1.2, R2.2, R4.2, R9.2, R12.1, R14.2, R16.1, R23.2, R24.1, R26.2, R27.2, R28.1, R29.1, R31.2, R36.1, R38.1, T1.E, U1.2 (GND1), U1.2@1 (GND2), U2.GND1, U2.GND2, U2.GND3 (GND1), U2.GND4 (GND2), U3.1 (GND), U4.3 (GND), U4.6 (GND), U5.4 (!LDAC), U5.10 (VSS), U6.3 (GND), U6.5 (!ON!/OFF), U6.6 (GND), U7.2@1 (2), U7.2@2 (2), U8.2@1 (2), U8.2@2 (2), U9.2@1 (2), U9.2@2 (2), U10.1 (GND_1), U10.2 (NC_1), U10.4 (NC_2), U10.7 (GND_2), U10.9 (NC_3), U10.11 (NC_4), U10.12 (GND_3), U10.13 (NC_5), U10.16 (VMODE), U10.17 (EP), U11.1 (GND_1), U11.2 (NC_1), U11.4 (NC_2), U11.7 (GND_2), U11.9 (NC_3), U11.11 (NC_4), U11.12 (GND_3), U11.13 (NC_5), U11.16 (VMODE), U11.17 (EP), X1.G@1 (2), X1.G@2 (2), X1.G@3 (2), X1.G@4 (2), X2.2, X3.2, X4.G@1 (2), X4.G@2 (2), X4.G@3 (2), X4.G@4 (2)
MCU_D13: C12.2, R5.1, U4.1 (!SHDN), U8.3
unnamed: C23.2, L7.2, TP3.TP, U1.1 (IN)
unnamed: C16.1, L5.RF-DC, U1.3 (OUT)
unnamed: JP8.1, R27.1, R35.2
unnamed: C6.1, L1.2, L3.1
unnamed: C10.1, L3.2, L4.1
unnamed: C24.2, JP3.1, R11.1, R12.2
unnamed: C59.2, U11.10 (RF2)
unnamed: L7.1, R13.2
unnamed: C21.2, R13.1
unnamed: C3.1, D2.C, R2.1
unnamed: C23.1, U11.3 (RF1)
unnamed: C1.1 (+), C5.2, L2.P$1 (1), X2.1
unnamed: JP6.1, R32.2, U5.2 (SCL)
unnamed: C14.1, L4.2, R7.2
unnamed: JP6.2, R30.2, U5.3 (SDA)
unnamed: JP2.1, R31.1, U8.1
unnamed: R25.2, R26.1, U4.5 (ADJ)
unnamed: C32.1, L10.P$1 (1), R20.1
unnamed: C35.1, L10.P$2 (2), L12.P$1 (1)
unnamed: C43.1, C49.2, D7.2 (A), L13.2
unnamed: C40.1, C42.1, D5.1 (C), L13.1
unnamed: C28.1, C59.1, L9.2, L15.1, TP2.TP
unnamed: C30.2, C31.1, L11.2, R21.2
unnamed: D4.1 (C), TP1.TP, X3.1
unnamed: R20.2, U2.OUT
unnamed: C51.2, U10.10 (RF2)
unnamed: JP4.1, R22.1, U3.2 (DQ)
unnamed: C52.1, U10.5 (RTN_1)
unnamed: C41.1, D6.C, JP5.1, R24.2
unnamed: C45.1, D8.C, JP7.1, R1.1
unnamed: D8.A, R28.2, R29.2
unnamed: C37.1, D5.2 (A), L14.P$1 (1)
unnamed: R34.2, R37.2, T1.C
unnamed: C53.1, U10.6 (RTN_2)
unnamed: D3.1 (C), L6.+ (1), U6.2 (OUT)
unnamed: C22.1 (+), C27.2, L6.- (2), L8.+ (1), R15.2
unnamed: C2.1, D1.A, R3.2
unnamed: R34.1, T2.B
unnamed: C11.2, D1.C, R4.1
unnamed: R35.1, T1.B
unnamed: D6.A, R36.2, R38.2
unnamed: C54.1, U10.8 (RTN_3)
unnamed: C27.1, R15.1, R16.2, U6.4 (FB)
unnamed: C55.1, R6.2, U10.15 (VDD)
unnamed: C56.1, R8.1, U10.14 (VCTRL)
unnamed: C11.1, R10.1, R14.1
unnamed: C60.1, U11.5 (RTN_1)
unnamed: C61.1, U11.6 (RTN_2)
unnamed: C62.1, U11.8 (RTN_3)
unnamed: C63.1, R17.2, U11.15 (VDD)
unnamed: C64.1, R18.1, U11.14 (VCTRL)
unnamed: R9.1, R10.2, U10.3 (RF1)
unnamed: R33.1, R39.1, T2.C
unnamed: C7.2, R3.1, U7.3
unnamed: C30.1, L15.2
unnamed: C39.2, L14.P$2 (2), U9.3
unnamed: C40.2, X4.1
PA-IN: C51.1, U2.IN
RX-IN: C49.1, R19.1, R21.1
RX-INAF: C16.2, D2.A, R5.2, R19.2, TP4.TP
RX-OUT: C4.1, L1.1, X1.1
TX-IN/RX-OUT: C2.2, C3.2, R7.1, TP5.TP
TX-OUT: C36.1, C37.2, L12.P$2 (2)
V+: C17.1, C18.1, C38.2, C65.1, L5.DC, R17.1, R25.1, U4.4 (OUT)
VBIAS: R33.2, R39.2, U9.1
VOUTA: C46.1, R18.2, U5.6 (VOUTA)
VOUTB: C58.1, R8.2, U5.7 (VOUTB)
VOUTC: U5.8 (VOUTC)

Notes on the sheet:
GNDed Holes
RX-Amp.
RX LC-BP Filter
n = 3 Type = Chebyshev fcu = 172MHz fcl = 120MHz
LC-LP Filter IN
60W FM PA
12VDC Supply + Filtering
5VDC for Arduino + DRA818V
n = 7 Type = Chebyshev fc = 155MHz
Measure VCC with Arduino
10VDC to max. 13.8VDC
Create VGG & measure it with Arduino
5VDC for PGA-103+
PIN-Diode RX-Switch
TX-RX Switch OUT
n = 5 Type = Chebyshev fc = 182MHz
LC-LP Filter OUT
Digital Attenuator
-3dB Attenuator
for max. 50W TX-OUT (-6dB + (-18dB))
PIN-Diode TX-Switch
50R
TX-OUT RX-IN
0.5W or 1W: Second SMA Con. on Case
Thermal Protection
SWR Protection
by OE3SDE Simon Dorrer
Directional coupler (PA --> ANT)
MCU / DRA818V
REV
FWD
VOUTC unused! MCU_A2 unused!
HIGH (TX) LOW (RX)
R23, R31 & R40 are for a defined voltage level at start-up of MCU!
Alternative: L1 = L4 = 47nH, L3 = 68nH;
PD = 0.5W
Air Coil Calculator for (L10, L12, L13): https://m0ukd.com/calculators/air-cored-inductor-calculator/

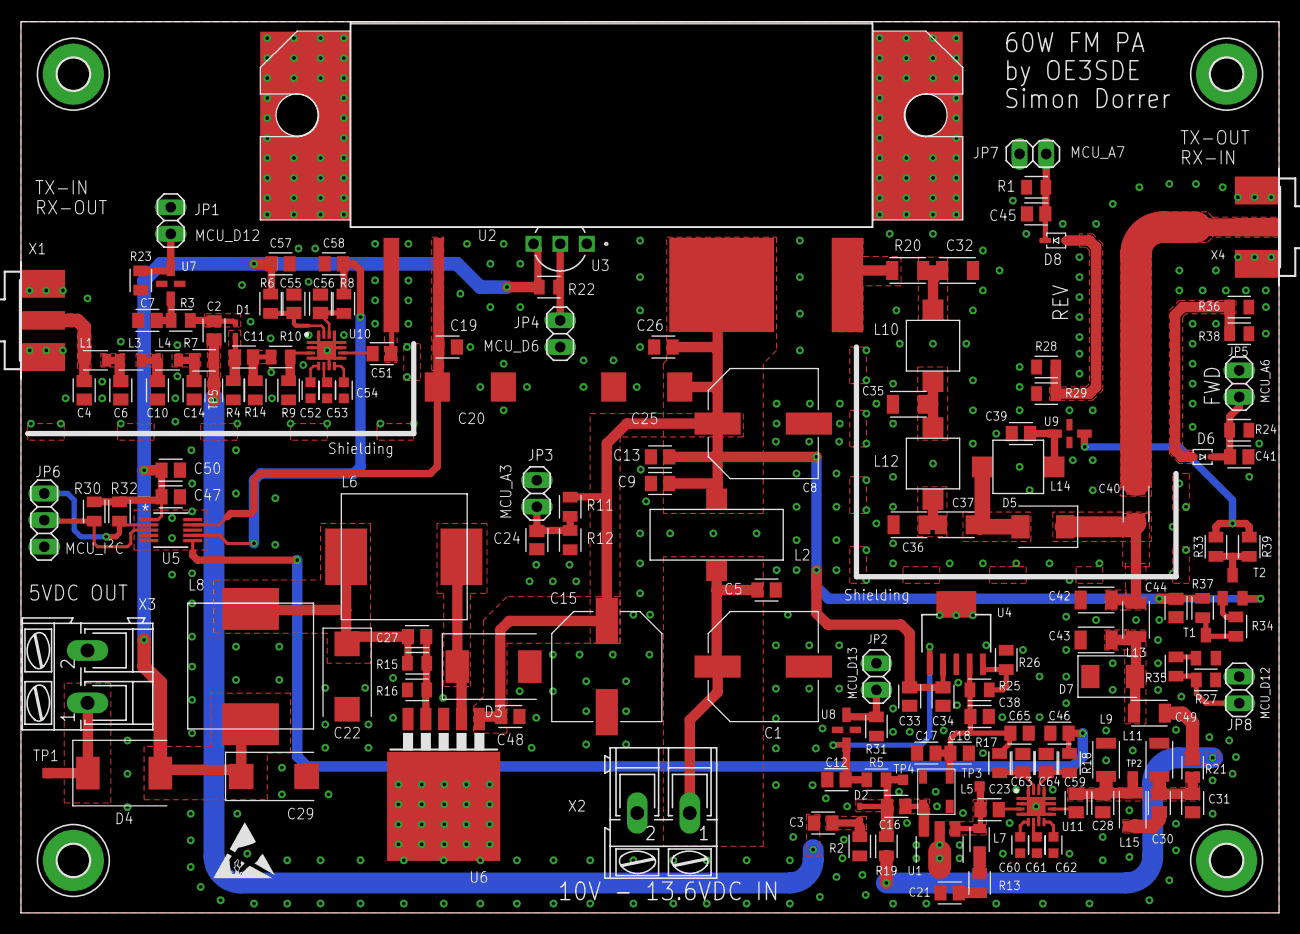
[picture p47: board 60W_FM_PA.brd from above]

Board: 2 copper layers, 120.0 x 85.0 mm, 161 parts (0 on the bottom side), 73 nets.

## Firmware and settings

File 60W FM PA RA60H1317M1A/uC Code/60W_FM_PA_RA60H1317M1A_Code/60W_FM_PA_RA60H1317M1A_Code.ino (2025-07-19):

//Arduino Code for DRA818V FM TRX + 60W RA60H1317M1A
//This code is written by OE3SDE, Simon Dorrer!

//Define CPU-Clock-Speed (16MHz internal clock)
//#define F_CPU 16000000UL

//Define Baudrate for UART
//#define BAUD 9600UL

//Include Libraries
#include <avr/io.h>
#include <stdio.h>
#include <avr/interrupt.h>

//I2C
#include <Wire.h>

//MCP4728
#include <Adafruit_MCP4728.h>

//DS18B20
#include <OneWire.h> 
#include <DallasTemperature.h>

//Libs. for SD1306 OLED-Display
#include <U8x8lib.h>
//----------------------------------------------------------------------------

//Definitions
//I/O Declaration
//1W FM TRX Board (DRA818V)
//#define TX        0     //PD0 / D0
//#define RX        1     //PD1 / D1
#define SW1         2     //PD2 / D2 - INT0
#define PTT_IN      3     //PD3 / D3 - INT1
#define PTT_OUT     7     //PD7 / D7
#define PD          0     //PB0 / D8
#define H_L         1     //PB1 / D9
#define HC05_TX     2     //PB2 / D10
#define HC05_RX     3     //PB3 / D11
#define E1          0     //PC0 / A0
#define E2          1     //PC1 / A1

//60W FM TRX Board (RA60H1317M1A)
#define PGA_SHDN    5     //PB5 / D13 (LOW --> PGA OFF, HIGH --> PGA ON) + RX Switch
#define TX_SW       4     //PB4 / D12 (HIGH: TX Switch ON, RX Switch OFF)
#define DS18B20_OW  6     //PD6 / D6  (One wire input of DS18B20 Temp. Sensor)
#define SWR_REV     7     //PC7 / A7  (ADC samples reverse voltage)
#define SWR_FWD     6     //PC6 / A6  (ADC samples forward voltage)
#define ADC_VDD     3     //PC3 / A3  (ADC samples VDD voltage) 

//I2C: OLED Display, MCP4728 (MCP4728_CHANNEL_C is unused!)

//Makros
//RX or TX ATTENUATOR
#define RX_ATTENUATOR_CHANNEL  MCP4728_CHANNEL_A
#define TX_ATTENUATOR_CHANNEL  MCP4728_CHANNEL_B

//PA max. ratings
#define VDD_LOWER_LIMIT 10.7  //in V
#define VDD_UPPER_LIMIT 14.2  //in V
#define SWR_LOWER_LIMIT 0.5   
#define SWR_UPPER_LIMIT 2
#define HEAT_UPPER_LIMIT 45   //in degrees
//----------------------------------------------------------------------------

//Global variables / Objects
uint8_t TX = 0;  // 0... RX; 1... TX
uint8_t switched = 0;

//OLED
U8X8_SH1106_128X64_NONAME_HW_I2C SH1106(/* reset=*/ U8X8_PIN_NONE); //0x3C I²C Address
uint8_t page = 1;
uint8_t clearOLED = 0;
uint8_t save = 1;

volatile uint16_t updateCount = 0;
volatile uint16_t pressedCount = 0;

//DRA818 Variables
typedef struct{
  float txFreq;         //TX-Frequency in MHz (134.0000 - 174.0000)
  float rxFreq;         //RX-Frequency in MHz (134.0000 - 174.0000)
  String txCTCSS;       //CTCSS frequency (0000 - 0038); 0000 = "no CTCSS" 
  String rxCTCSS;       //CTCSS frequency (0000 - 0038); 0000 = "no CTCSS" 
  uint8_t bw;           //Bandwith in kHz (0 = 12.5KHz or 1 = 25KHz)
  uint8_t squ;          //Squelch level  (0 - 8); 0 = "open" 
  uint8_t vol;
  uint8_t prf;
  uint8_t hpf;
  uint8_t lpf;
  uint8_t steps;        //frequency steps (1 = 12.5kHz, 2 = 25kHz, 4 = 50kHz, 8 = 100kHz)
}DRA818;

//CTCSS:
//https://en.wikipedia.org/wiki/Continuous_Tone-Coded_Squelch_System
//https://www.oevsv.at/oevsv/aktuelles/UKW-Bandplaene-Relais-etc.-CTCSS-in-OE-mit-System/
/*Wien (OE1)              EIA 01    67,0 Hz
Salzburg (OE2)            EIA 08    88,5 Hz
Niederösterreich (OE3)    EIA 26    162,2 Hz
Burgenland (OE4)          EIA 11    97,4 Hz
Oberösterreich (OE5)      EIA 18    123,0 Hz
Steiermark (OE6)          EIA 13    103,5 Hz
Tirol (OE7)               EIA 04    77,0 Hz
Kärnten (OE8)             EIA 08    88,5 Hz
Vorarlberg (OE9)          EIA 07    85,4 Hz*/
String ctcss_arr[] = {"0000", "0001", "0008", "0026", "0011", "0018", "0013", "0004", "0008", "0007"};
uint8_t idxTXCTCSS = 0;
uint8_t idxRXCTCSS = 0;

DRA818 dra818 = {145.5000, 145.5000, ctcss_arr[0], ctcss_arr[0], 0, 4, 8, 0, 0, 0, 2};

//DS18B20
OneWire oneWire(DS18B20_OW); 
DallasTemperature ds18b20(&oneWire);

//MCP4728
Adafruit_MCP4728 mcp4728;

//Rotary Encoder Variables
uint8_t lastState = 0;
uint8_t currentState = 0;

//RA60H1317M1A Variables in dB
uint8_t idxPWR = 0; //TX: 0: 5W = 37dBm, 1: 10W = 40dBm, 2: 20W = 43dBm, 3: 32W = 45dBm, 4: 50W = 47dBm, 5: no PA, only DRA818
String pwr_arr[] = {"5W", "10W", "20W", "32W", "50W", "0.5W"};
float txGain = 1;   //0... 0V, 1... 4.7V, 2... 5V @ RA60H Gate; RX --> 0, TX = 5W to 32W --> 1, TX = 50W --> 2
float txAtt = 12;   //5W = 17, 10W = 12, 20W = 3, 32W = 0, 40W = 0 @ 12.5VDC --> Higher PWR with higher VDD (max. 14.2V)
float rxAtt = 0;
uint8_t monitorPA = 0;  //monitorPA = 1... PA is OK!
//----------------------------------------------------------------------------

//Subprograms
//Hardware Init Methods
void IO_Init(){                 //initialize IO
  //Define INPUTs
  DDRD &= ~(1 << SW1);          //set PD2 (SW1) as Input
  PORTD |= (1 << SW1);          //activate Pull-Up-R at PD2 (SW1)    
  
  DDRD &= ~(1 << PTT_IN);       //set PD3 (PTT-IN) as Input
  PORTD |= (1 << PTT_IN);       //activate Pull-Up-R at PD3 (PTT_IN)     
  
  DDRC &= ~(1 << E1);           //set PC0 (E1) as Input    
  DDRC &= ~(1 << E2);           //set PC1 (E2) as Input
  PORTC |= (1 << E1);           //activate Pull-Up-R at PC0 (E1)
  PORTC |= (1 << E2);           //activate Pull-Up-R at PC1 (E2)
  
  DDRC &= ~(1 << ADC_VDD);      //set PC3 (ADC_VDD) as Input  
  PORTC |= (1 << ADC_VDD);      //activate Pull-Up-R at PC3 (ADC_VDD)

  DDRC &= ~(1 << SWR_FWD);      //set PC6 (SWR_FWD) as Input  
  PORTC |= (1 << SWR_FWD);      //activate Pull-Up-R at PC6 (SWR_FWD)

  DDRC &= ~(1 << SWR_REV);      //set PC7 (SWR_REV) as Input  
  PORTC |= (1 << SWR_REV);      //activate Pull-Up-R at PC7 (SWR_REV)
  
  //Define OUTPUTs
  DDRD |= (1 << PTT_OUT);       //set PD7 (PTT_OUT) as Output
  DDRB |= (1 << PD);            //set PB0 (PD) as Output
  DDRB |= (1 << H_L);           //set PB1 (H_L) as Output
  
  DDRB |= (1 << TX_SW);         //set PB4 (TX_Switch) as Output
  DDRB |= (1 << PGA_SHDN);      //set PB5 (PGA_SHDN) as Output
}

void Timer1_COMPA_Init(){
  //Control Registers
  TCCR1A = 0; 
  TCCR1B = 0; 
  TCCR1C = 0; //Reset
  
  // set CTC mode
  //TCCR1A |= (1 << WGM10);
  //TCCR1A |= (1 << WGM11);
  TCCR1B |= (1 << WGM12);
  
  // Set Prescaler 1024 (TCCR1B = (1 << WGM12) | (0x5 << CS10);)
  TCCR1B |= (1 << CS12);
  TCCR1B &= ~(1 << CS11);
  TCCR1B |= (1 << CS10);
  
  // initialize compare value
  OCR1A = 16;
  
  // enable timer compare interrupt
  TIMSK1 |= (1 << OCIE1A);
}

void INT0_Init(){
  //enable Interrupt
  EIMSK |= (1 << INT0); //Ext. Int0 ein
  
  //Set every Edge Interrupt
  EICRA |= (1 << ISC00);
  EICRA &= ~(1 << ISC01);
}

void INT1_Init(){
  //enable Interrupt
  EIMSK |= (1 << INT1); //Ext. Int1 ein
  
  //Set rising & falling Edge Interrupt (EICRA |= (0x2 << ISC10);)
  EICRA |= (1 << ISC10);
  EICRA &= ~(1 << ISC11);
}

void ADC_Init(){
  //ADC Setup
  //Set Reference Voltage (VCC = VREF)
  ADMUX &= ~(1 << REFS1);
  ADMUX |= (1 << REFS0);

  //Prescaler --> 128 (50kHz - 200kHz)
  ADCSRA |= (1 << ADPS0);
  ADCSRA |= (1 << ADPS1);
  ADCSRA |= (1 << ADPS2);
  
  ADCSRA |= (1 << ADEN); //Enable ADC

  //Dummy Readout to warm up the ADC
  ADCSRA |= (1<<ADSC);          //Start ADC conclusion
  while (ADCSRA & (1<<ADSC)){}  //wait until ADC is ready
  (void) ADC;
}

uint16_t ADC_ReadValue(uint8_t channel){
  ADMUX = (ADMUX & ~(0x1F)) | (channel & 0x1F); //which ADCx? Bit Mask to secure ADMUX settings in Init() function
  
  ADCSRA |= (1<<ADSC);          //Start ADC conclusion
  while (ADCSRA & (1<<ADSC)){}  //wait until ADC is ready
  
  return ADC;                   //return the ADC value
}
//--------------------------------------------------------------------------

//DRA818V Methods
void DRA818V_setGroup(){
  Serial.print("AT+DMOSETGROUP=");
  Serial.print(dra818.bw);
  Serial.print(",");
  Serial.print(dra818.txFreq, 4);
  Serial.print(",");
  Serial.print(dra818.rxFreq, 4);
  Serial.print(",");
  Serial.print(dra818.txCTCSS);
  Serial.print(",");
  Serial.print(dra818.squ);
  Serial.print(",");
  Serial.println(dra818.rxCTCSS);
}

void DRA818V_setVolume(){
  Serial.print("AT+DMOSETVOLUME=");
  Serial.println(dra818.vol);
}

void DRA818V_setFilter(){
  Serial.print("AT+SETFILTER=");
  Serial.print(dra818.prf);
  Serial.print(",");
  Serial.print(dra818.hpf);
  Serial.print(",");
  Serial.println(dra818.lpf);
}

void DRA818V_Init(){             // initialize DRA818V
  PORTB &= ~(1 << PD);
  delay(2000);
  
  //I/O
  PORTD |= (1 << PTT_OUT);      // set PD7 (PTT_OUT) HIGH at the beginning (RX-Mode)
  PORTB |= (1 << PD);           // set PB0 (PD) HIGH at the beginning (Normal-Mode)
  PORTB &= ~(1 << H_L);         // set PB1 (H/L) LOW at the beginning (LOW-Power = 0.5W)

  //UART
  Serial.begin(9600);
  delay(10);
  DRA818V_setGroup();
  delay(500);
  DRA818V_setVolume();
  delay(500);
  DRA818V_setFilter();
  delay(500);
}
//--------------------------------------------------------------------------

//RA60H1317M1A Methods
float getVDD(){      //Get VDD Voltage (10.8VDC to 13.6VDC)
  float vdd = ADC_ReadValue(ADC_VDD) * 5.0 / 1024.0;
  if(ADC_ReadValue(ADC_VDD) < 1020){
    vdd = vdd * ((4700 + 18000) / 4700) + 0.8; //magic numbers equals the voltage divider resistor values
  }  
  return vdd;  //returns supply voltage without voltage division
}

float getSWR(){      //Get SWR of output load (should be between 0.5 and 2)
  float rev = 0;
  float fwd = 0;
  
  for(int i = 0; i < 10; i++){   //10 iterations for a more precise result
    rev = rev + ADC_ReadValue(SWR_REV);
    fwd = fwd + ADC_ReadValue(SWR_FWD);
  }
  rev = rev / 10 / 1024 * 5;
  fwd = fwd / 10 / 1024 * 5;

  //SWR Calculation
  return((fwd + rev) / (fwd - rev));
}

float getPWR(){
  float fwd = 0;
  
  for(int i = 0; i < 10; i++){   //10 iterations for a more precise result
    fwd = fwd + ADC_ReadValue(SWR_FWD);
  }
  fwd = fwd / 10 / 1024 * 5;

  //PWR Calculation
  return((fwd * fwd) / 50);
}

float getHeat(){     //Get heat of RA60H1317M1A measured by DS18B20, should be smaller than 50
  ds18b20.requestTemperatures();
  float temp = ds18b20.getTempCByIndex(0);
  if(temp <= -30){temp = -30;}
  if(temp >= 60){temp = 60;}
  return temp;
}

void setTXGain(float gain){  //Set Gain of RA60H1317M1A via MCP4728 (VOUTD)
  if(gain == 0){
    mcp4728.setChannelValue(MCP4728_CHANNEL_D, 0);
  }else if(gain == 1){
    mcp4728.setChannelValue(MCP4728_CHANNEL_D, 3700);
  }else if(gain == 2){
    mcp4728.setChannelValue(MCP4728_CHANNEL_D, 4000);
  }
}

void setAttenuation(MCP4728_channel_t channel, float att){ //Attenuation of U11 (RX) or U12 (TX) (F2255NLGK)
  //Note that the PGA-103 has a constant gain of 15dB for RX path! RX_ATTENUATOR_CHANNEL MCP4728_CHANNEL_A
  //Note that an 3dB Attenuator is assembled on board for TX path! TX_ATTENUATOR_CHANNEL MCP4728_CHANNEL_B
  
  if(att > 35){
    mcp4728.setChannelValue(channel, 2048);
  }else if(att < 2.5){
    mcp4728.setChannelValue(channel, 0);
  }else{
    att = att * (-1);
    mcp4728.setChannelValue(channel, (uint16_t)(4096 * (-0.03692 * att + 0.60769) / 5));  //0.7V (-2.5dB) to 1.9V (-35dB), magic numbers are calculated according to the attenuation curve of the datasheet!
  }
}

void setTXPower(uint8_t pwr){
  switch(pwr) {
    case 0:   //5W
        txGain = 1;
        txAtt = 17;
        break;
    case 1:   //10W
        txGain = 1;
        txAtt = 12;
        break;
    case 2:   //20W
        txGain = 1;
        txAtt = 3;
        break;
    case 3:   //32W
        txGain = 1;
        txAtt = 0;
        break;
    case 4:   //50W
        txGain = 2;
        txAtt = 0;
        break;
    case 5:   //0.5W
        txGain = 0;
        txAtt = 36;
        break;
    default:
        break;
  }
}

void switchPAtoTX(uint8_t TX_Att, uint8_t TX_Gain){
  if(monitorPA == 1){
    //turn OFF RX:
    PORTB &= ~(1 << PGA_SHDN);                        //turn OFF PGA RX-Amp. and RX-IN Switch (D13 to LOW)
    setAttenuation(RX_ATTENUATOR_CHANNEL, 36);        //set full attenuation of U11 (F2255NLGK)
    
    delay(100);     //100ms settling time
    
    //turn ON TX:
    PORTB |= (1 << TX_SW);                            //turn ON TX-OUT Switch, turn OFF RX-OUT Switch (D12 to HIGH)
    PORTD &= ~(1 << PTT_OUT);                         //turn TX Path in TRX-IN Switch ON (D7 LOW)
    setAttenuation(TX_ATTENUATOR_CHANNEL, TX_Att);    //set attenuation of U12 (F2255NLGK)
    setTXGain(TX_Gain);                               //Set TX gain (VGG (Gate) voltage) of RA60H1317M1A
    delay(100);                                       //100ms settling time
  }else{
    switchPAtoRX(rxAtt);
  }
}

void switchPAtoRX(float RX_Att){
  //turn OFF TX:
  setTXGain(0);                                       //Set gain of RA60H1317M1A to 0
  setAttenuation(TX_ATTENUATOR_CHANNEL, 36);          //set full attenuation of U12 (F2255NLGK)
  PORTD |= (1 << PTT_OUT);                            //turn TX Path in TRX-IN Switch OFF (D7 HIGH)
  PORTB &= ~(1 << TX_SW);                             //turn ON RX-OUT Switch, turn OFF TX-OUT Switch (D12 to LOW)
  delay(100);                                         //100ms settling time
  
  //turn ON RX
  PORTB |= (1 << PGA_SHDN);                           //turn ON PGA RX-Amp. and RX-IN Switch (D13 to HIGH)
  setAttenuation(RX_ATTENUATOR_CHANNEL, RX_Att);      //set attenuation of U11 (F2255NLGK)
  delay(100);                                         //100ms settling time
}

void verifyPA(){   //Shutdown RA60H1317M1A according to SWR, VDD and Heat
  float vdd = getVDD();
  float swr = getSWR();
  float heat = getHeat();
  
  //if((vdd >= VDD_LOWER_LIMIT && vdd <= VDD_UPPER_LIMIT) && (swr >= SWR_LOWER_LIMIT && swr <= SWR_UPPER_LIMIT) && heat <= HEAT_UPPER_LIMIT)
  if((vdd >= VDD_LOWER_LIMIT && vdd <= VDD_UPPER_LIMIT) && heat <= HEAT_UPPER_LIMIT){
    monitorPA = 1;  //PA is OK!
  }else{
    monitorPA = 0;
    if(TX == 1){
      switchPAtoRX(rxAtt);
    }
  }
}

//Display Methods
void displayInit(){
  SH1106.begin();
  SH1106.clear();
  //FONTS: https://github.com/olikraus/u8g2/wiki/fntlist8x8
  SH1106.setFont(u8x8_font_8x13_1x2_r);
}

void displayStartScreen(){
  //Set start Text 
  SH1106.setFont(u8x8_font_8x13B_1x2_r);
  SH1106.drawString(3, 0, "60W FM TRX");
  SH1106.drawString(3, 3, "by OE3SDE");
  SH1106.drawString(3, 6, "S. Dorrer");
  SH1106.setFont(u8x8_font_8x13_1x2_r);
}
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
void loop(){
  if(updateCount >= 200){
    updateCount = 0;
    verifyPA();
    refreshDisplay();
  }

  if(TX == 1 && switched == 1){
    switchPAtoTX(txAtt, txGain);    //PA PCB is transmitting now!
    switched = 0;
  }else if (TX == 0 && switched == 1){
    switchPAtoRX(rxAtt);            //PA PCB is receiving now!
    switched = 0;
  }
}
//----------------------------------------------------------------------------

//ISP (Interrupt Service Routine) 
ISR(TIMER1_COMPA_vect){  // every 1ms
  updateCount++;
  pressedCount++;

  //Rotary Switch
  currentState = PINC & (1 << E1);
  
  if (currentState != lastState && currentState == 1){
    if(!(PINC & (1 << E2)) == currentState) {     //UP
      if(page == 2){                              //Page 2: Increasing steps
        if(dra818.steps == 8){dra818.steps = 1;}
        else{dra818.steps = dra818.steps * 2;}
        
      }else if(page == 3){                        //Page 3: Increasing TX-Frequency by step
        if(dra818.txFreq >= 146.000){dra818.txFreq = 144.000;}
        else{dra818.txFreq = dra818.txFreq + 0.0125 * dra818.steps;}
        
      }else if(page == 4){                        //Page 4: Increasing RX-Frequency by step
        if(dra818.rxFreq >= 146.000){dra818.rxFreq = 144.000;}
        else{dra818.rxFreq = dra818.rxFreq + 0.0125 * dra818.steps;}
        
      }else if(page == 5){                        //Page 5: Increasing Bandwidth
        if(dra818.bw == 0){dra818.bw = 1;}
        else {dra818.bw = 0;}
        
      }else if(page == 6){                        //Page 6: Increasing TX-Power
        if(idxPWR == 5){idxPWR = 0;}
        else{idxPWR++;}
        
      }else if(page == 7){                        //Page 7: Increasing RX-Attenuation
        if(rxAtt >= 35){rxAtt = 0;}
        else{rxAtt = rxAtt + 5;}
        
      }else if(page == 8){                        //Page 8: Increasing Volume
        if(dra818.vol == 8){dra818.vol = 1;}
        else{dra818.vol++;}
        
      }else if(page == 9){                        //Page 9: Increasing Squelch
        if(dra818.squ == 8){dra818.squ = 0;}
        else{dra818.squ++;}
        
      }else if(page == 10){                       //Page 10: Increasing TX-CTCSS
        if(idxTXCTCSS == 9){idxTXCTCSS = 0;}
        else{idxTXCTCSS++;}
        dra818.txCTCSS = ctcss_arr[idxTXCTCSS];
        
      }else if(page == 11){                       //Page 11: Increasing RX-CTCSS
        if(idxRXCTCSS == 9){idxRXCTCSS = 0;}
        else{idxRXCTCSS++;}
        dra818.rxCTCSS = ctcss_arr[idxRXCTCSS];
      }
    } else {                                      //DOWN
      if(page == 2){                              //Page 2: Decreasing steps
        if(dra818.steps == 1){dra818.steps = 8;}
        else{dra818.steps = dra818.steps / 2;}
        
      }else if(page == 3){                        //Page 3: Decreasing TX-Frequency by step
        if(dra818.txFreq <= 144.000){dra818.txFreq = 146.000;}
        else{dra818.txFreq = dra818.txFreq - 0.0125 * dra818.steps;}
        
      }else if(page == 4){                        //Page 4: Decreasing RX-Frequency by step
        if(dra818.rxFreq <= 144.000){dra818.rxFreq = 146.000;}
        else{dra818.rxFreq = dra818.rxFreq - 0.0125 * dra818.steps;}
        
      }else if(page == 5){                        //Page 5: Decreasing Bandwidth
        if(dra818.bw == 1){dra818.bw = 0;}
        else {dra818.bw = 1;}
        
      }else if(page == 6){                        //Page 6: Decreasing TX-Power
        if(idxPWR == 0){idxPWR = 5;}
        else{idxPWR--;}
       
      }else if(page == 7){                        //Page 7: Decreasing RX-Attenuation
        if(rxAtt <= 0){rxAtt = 35;}
        else{rxAtt = rxAtt - 5;}
        
      }else if(page == 8){                        //Page 8: Decreasing Volume
        if(dra818.vol == 1){dra818.vol = 8;}
        else{dra818.vol--;}
        
      }else if(page == 9){                        //Page 9: Decreasing Squelch
        if(dra818.squ == 0){dra818.squ = 8;}
        else{dra818.squ--;}
        
      }else if(page == 10){                       //Page 10: Decreasing TX-CTCSS
        if(idxTXCTCSS == 0){idxTXCTCSS = 9;}
        else{idxTXCTCSS--;}
        dra818.txCTCSS = ctcss_arr[idxTXCTCSS];
        
      }else if(page == 11){                       //Page 11: Decreasing RX-CTCSS
        if(idxRXCTCSS == 0){idxRXCTCSS = 9;}
        else{idxRXCTCSS--;}
        dra818.rxCTCSS = ctcss_arr[idxRXCTCSS];
      }
    }
    clearOLED = 1;
  }
  lastState = currentState;
}

ISR(INT0_vect){  //Rotary Encoder Switch
  if(PIND & (1 << 2)){    // HIGH?
    if(pressedCount >= 250){
      save = 1;
      page = 1;
    } else {
      if(page == 12){
        page = 0;
      }
      page++;
    }
    clearOLED = 1;
    pressedCount = 0;
  }

  if(!(PIND & (1 << 2))){ // LOW?
    pressedCount = 0;
  }
}

ISR(INT1_vect){ //PTT-IN (active LOW)
  switched = 1;
  page = 1;
  clearOLED = 1;
  
  if(!(PIND & (1 << PTT_IN))){         //PTT_IN changed to LOW
    TX = 1;
  }else if (PIND & (1 << PTT_IN)){      //PTT_IN changed to HIGH
    TX = 0;
  }
}
//----------------------------------------------------------------------------
//End of Code!

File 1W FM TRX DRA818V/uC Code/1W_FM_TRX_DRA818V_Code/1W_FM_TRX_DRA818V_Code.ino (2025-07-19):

//Arduino Code for DRA818V FM TRX
//This code is written by OE3SDE, Simon Dorrer!

//Define CPU-Clock-Speed (16MHz internal clock)
//#define F_CPU 16000000UL

//Define Baudrate for UART
//#define BAUD 9600UL

//Include Libraries
#include <avr/io.h>
#include <stdio.h>
#include <avr/interrupt.h>

//I2C
#include <Wire.h>

//Libs. for SD1306 OLED-Display
#include <Adafruit_GFX.h>               // Include core graphics library for the display
#include <Adafruit_SSD1306.h>           // Include Adafruit_SSD1306 library to drive the display
#include <Fonts/FreeMonoBold12pt7b.h>   // Add a custom font
#include <Fonts/FreeMono9pt7b.h>        // Add a custom font
/*List of fonts that support right alignment:
FreeMono9pt7b.h
FreeMono12pt7b.h
FreeMono18pt7b.h
FreeMono24pt7b.h
FreeMonoBold9pt7b.h
FreeMonoBold12pt7b.h
FreeMonoBold18pt7b.h
FreeMonoBold24pt7b.h
FreeMonoBoldOblique9pt7b.h
FreeMonoBoldOblique12pt7b.h
FreeMonoBoldOblique18pt7b.h
FreeMonoBoldOblique24pt7b.h
FreeMonoOblique9pt7b.h  
FreeMonoOblique12pt7b.h
FreeMonoOblique18pt7b.h
FreeMonoOblique24pt7b.h*/
//----------------------------------------------------------------------------

//Definitions
//I/O Declaration
//#define TX        0     //PD0 / 0
//#define RX        1     //PD1 / 1
#define SW1         2     //PD2 / 2 - INT0
#define PTT_IN      3     //PD3 / 3 - INT1
#define PTT_OUT     7     //PD7 / 7
#define PD          0     //PB0 / 8
#define H_L         1     //PB1 / 9
#define HC05_TX     2     //PB2 / 10
#define HC05_RX     3     //PB3 / 11
#define TX_LED      5     //PB5 / 13
#define E1          0     //PC0 / 14 (A0)
#define E2          1     //PC1 / 15 (A1)
//----------------------------------------------------------------------------

//Global variables

//OLED
Adafruit_SSD1306 display(128, 64);  // Create display
uint16_t timer1Count = 500;

//DRA818V Variables
uint8_t bw = 1;                //Bandwith in KHz (0= 12.5KHz or 1= 25KHz)
float tx_f = 145.5000;         //TX-Frequency in MHz (134.0000 - 174.0000)
float rx_f = 145.5000;         //RX-Frequency in MHz (134.0000 - 174.0000)
String tx_ctcss = "0000";      //CTCSS frequency (0000 - 0038); 0000 = "no CTCSS" 
String rx_ctcss = "0000";      //CTCSS frequency (0000 - 0038); 0000 = "no CTCSS" 
uint8_t squ = 4;               //Squelch level  (0 - 8); 0 = "open" 
uint8_t vol = 8;
uint8_t PRF = 0;
uint8_t HPF = 0;
uint8_t LPF = 0;
uint8_t tx = 0;                 // 0... RX; 1... TX

//Rotary Encoder Variables
uint8_t encoderPressedCounter = 1;
uint16_t timer2Count = 0;
int counter = 0; 
int aState;
int aLastState;  
//----------------------------------------------------------------------------

//Subprograms
//IO Subprograms
void IO_Init()                  //initialize IO
{
  //Define INPUTs
  DDRD &= ~(1 << SW1);          //set PD2 (SW1) as Input
  PORTD |= (1 << SW1);          //activate Pull-Up-R at PD2 (SW1)    
  
  DDRD &= ~(1 << PTT_IN);       //set PD3 (PTT-IN) as Input
  PORTD |= (1 << PTT_IN);       //activate Pull-Up-R at PD3 (PTT_IN)     
  
  DDRC &= ~(1 << E1);           //set PC0 (E1) as Input    
  DDRC &= ~(1 << E2);           //set PC1 (E2) as Input
  
  //Define OUTPUTs
  DDRD |= (1 << PTT_OUT);       //set PD7 (PTT_OUT) as Output
  DDRB |= (1 << PD);            //set PB0 (PD) as Output
  DDRB |= (1 << H_L);           //set PB1 (H_L) as Output
  
  DDRB |= (1 << TX_LED);        //set PB5 (TX_LED) as Output
  PORTB &= ~(1 << TX_LED);      //set PB5 (TX_LED) LOW at the beginning
}

void Timer1_COMPA_Init()
{
  //Control Registers
  TCCR1A = 0;
  TCCR1B = 0;
  TCCR1C = 0;
  
  // set CTC mode
  //TCCR1A |= (1 << WGM10);
  //TCCR1A |= (1 << WGM11);
  TCCR1B |= (1 << WGM12);
  
  // Set Prescaler 1024
  TCCR1B |= (1 << CS12);
  TCCR1B &= ~(1 << CS11);
  TCCR1B |= (1 << CS10);
  
  // initialize compare value
  OCR1A = 16;
  
  // enable timer compare interrupt
  TIMSK1 |= (1 << OCIE1A);
}

void Timer2_COMPA_Init()
{
  //Timer2 settings
  //Enable Timer2 CTC Mode
  TCCR2A = 0x00;
  TCCR2B = 0x00;
  
  //TCCR2A |= (1 << WGM20);
  TCCR2A |= (1 << WGM21);
  //TCCR2B |= (1 << WGM22);
  
  //Prescaler
  // 1024 prescaling for Timer2
  TCCR2B |= (1 << CS20);
  TCCR2B |= (1 << CS21);
  TCCR2B |= (1 << CS22);

  //Initialize compare value
  OCR2A = 0;
  
  //initialize TIMER0-Counter
  //TCNT2 = 0; // set counter value FORMEL: x = maximaler Zählwert - ((CPUtakt/PRESCALER)/ gesuchte Frequenz)
  
  // disable Timer compare interrupt
  TIMSK2 &= ~(1 << OCIE2A);
}

void INT0_Init()
{
  //enable Interrupt
  (EIMSK |= (1 << INT0)); //Ext. Int0 ein
  
  //Set falling Edge Interrupt
  (EICRA &= ~(1 << ISC00));
  (EICRA |= (1 << ISC01));
}
void INT1_Init()
{
  //enable Interrupt
  (EIMSK |= (1 << INT1)); //Ext. Int1 ein
  
  //Set rising & falling Edge Interrupt
  (EICRA |= (1 << ISC10));
  (EICRA &= ~(1 << ISC11));
}

void DRA818V_setGroup()
{
  Serial.print("AT+DMOSETGROUP=");         // begin message
  Serial.print(bw);
  Serial.print(",");
  Serial.print(tx_f,4);
  Serial.print(",");
  Serial.print(rx_f,4);
  Serial.print(",");
  Serial.print(tx_ctcss);
  Serial.print(",");
  Serial.print(squ);
  Serial.print(",");
  Serial.println(rx_ctcss);
}
void DRA818V_setVolume()
{
  Serial.print("AT+DMOSETVOLUME=");
  Serial.println(vol);
}
void DRA818V_setFilter()
{
  Serial.print("AT+SETFILTER=");
  Serial.print(PRF);
  Serial.print(",");
  Serial.print(HPF);
  Serial.print(",");
  Serial.println(LPF);
}
void DRA818V_Init()             // initialize DRA818V
{
  PORTB &= ~(1 << PD);
  delay(2000);
  
  //I/O
  PORTD |= (1 << PTT_OUT);      // set PD7 (PTT_OUT) HIGH at the beginning (RX-Mode)
  PORTB |= (1 << PD);           // set PB0 (PD) HIGH at the beginning (Normal-Mode)
  PORTB &= ~(1 << H_L);         // set PB1 (H/L) LOW at the beginning (LOW-Power = 0.5W)

  //UART
  Serial.begin(9600);
  delay(10);
  DRA818V_setGroup();
  delay(500);
  DRA818V_setVolume();
  delay(500);
  DRA818V_setFilter();
  delay(500);
  //Serial.end();
}

void refreshDisplay()
{
  display.clearDisplay();
  
  // TX / RX
  if(tx == 1)
  {
    display.setCursor(10, 15);                  // (x,y)
    display.println("TX");
  }
  else if(tx == 0)
  {
    display.setCursor(10, 15);                  // (x,y)
    display.println("RX");
  }
  
  // Power
  display.setCursor(50, 15);                    // (x,y)
  display.println("PWR:.5W");

  // Frequency
  display.setCursor(30, 45);                    // (x,y)
  display.println(tx_f);

  display.display();
}
//----------------------------------------------------------------------------
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

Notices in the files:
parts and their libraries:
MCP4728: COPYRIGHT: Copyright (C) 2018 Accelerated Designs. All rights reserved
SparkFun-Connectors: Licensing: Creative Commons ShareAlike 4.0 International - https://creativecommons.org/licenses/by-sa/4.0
